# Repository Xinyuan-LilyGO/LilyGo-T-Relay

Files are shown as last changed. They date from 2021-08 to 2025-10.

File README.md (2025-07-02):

<h1 align = "center">🌟LILYGO T-Relay Series🌟</h1>

## 1️⃣ Quick Start:

* T-Relay  Channel  (Basic ESP32S3) **[English](docs/RELAY_2_ESP32S3.MD)**
* T-Relay 4 Channel (Basic ESP32) **[English](docs/RELAY_ESP32.md)/[中文](docs/RELAY_ESP32_CN.MD)**
* T-Relay 8 Channel (Basic ESP32) **[English](docs/RELAY_ESP32.md)/[中文](docs/RELAY_ESP32_CN.MD)**
* T-Relay S3 (Basic ESP32S3)      **[English](docs/RELAY_ESP32S3.MD)/[中文](docs/RELAY_ESP32S3_CN.MD)**

## 2️⃣ Where to buy:

#### T-Relay 4 Channel (Basic ESP32)
[LilyGo Shop](https://www.lilygo.cc/products/t-relay)

#### T-Relay 8 Channel (Basic ESP32)
[LilyGo Shop](https://www.lilygo.cc/products/t-relay-5v-8-channel-relay)

#### T-Relay S3 (Basic ESP32S3)
[LilyGo Shop](https://www.aliexpress.us/item/3256805375487806.html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)

## FAQ

* Q. How should I correctly connect the W5500 Shield to the motherboard?
* A. There are two versions of the W5500 Shield.

    1.T-Relay 4 Channel and T-Relay 8 Channel versions
    <p align="left">
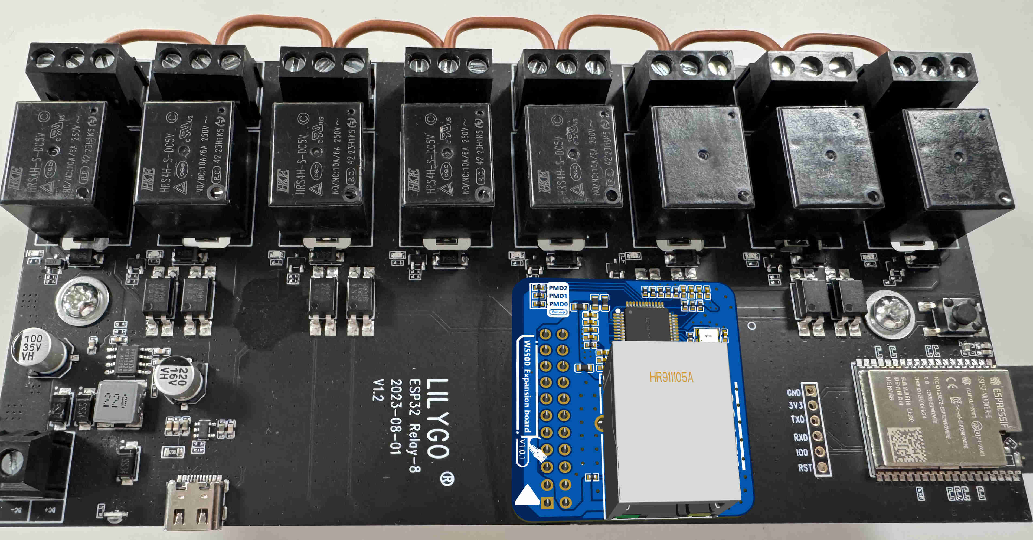
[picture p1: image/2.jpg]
        
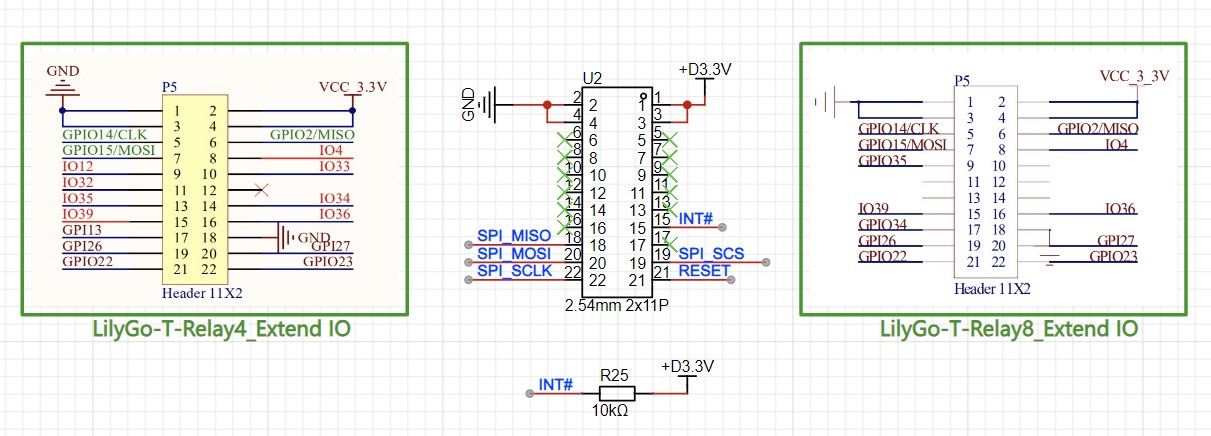
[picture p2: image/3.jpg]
        
    </p>
    <p align="left">
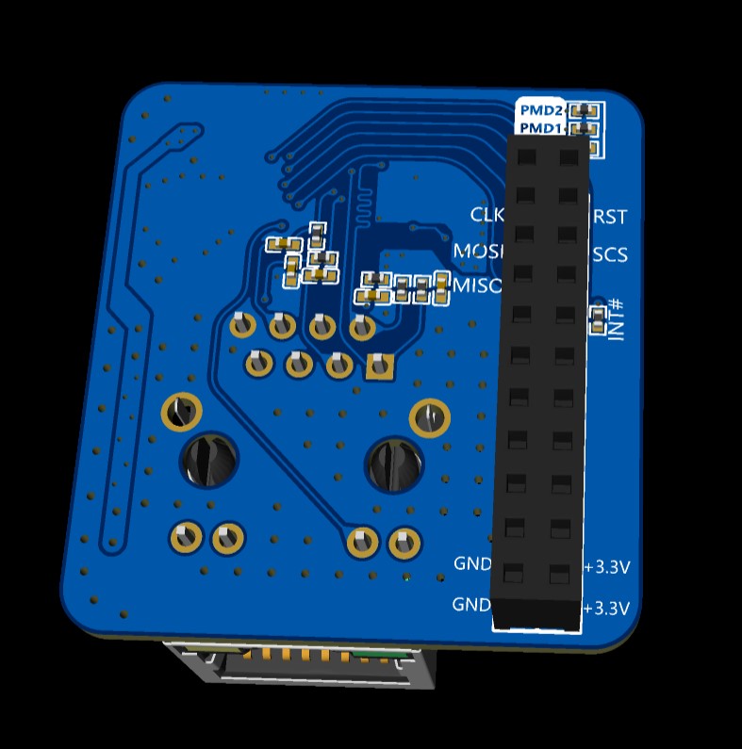
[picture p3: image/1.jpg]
        
    </p>

    2.T-Relay S3 versions
    <p align="left">
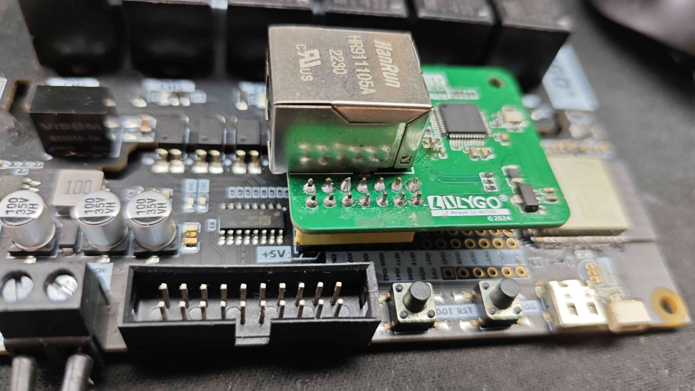
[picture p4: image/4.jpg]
        
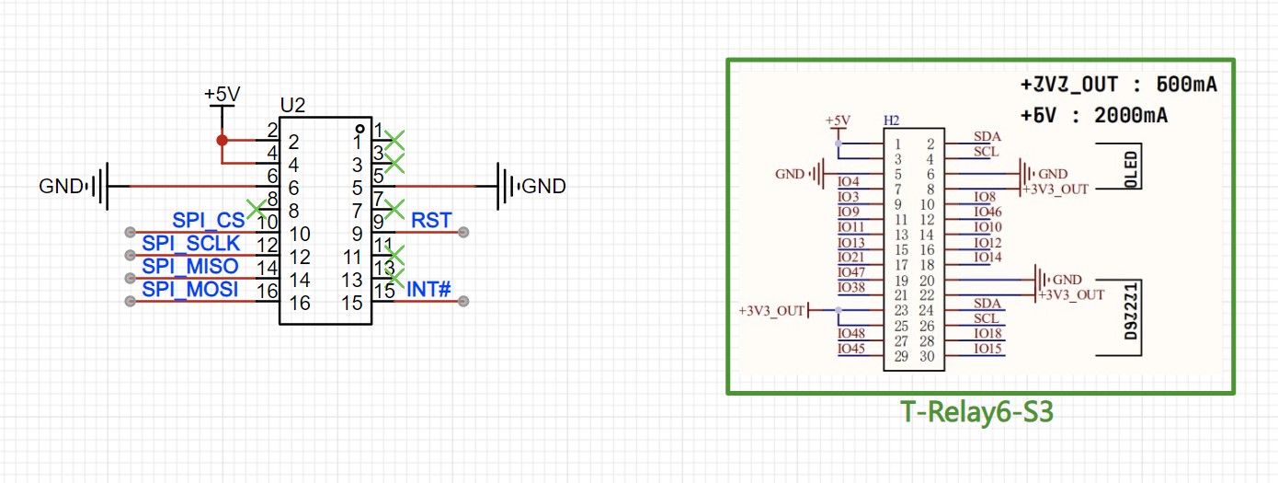
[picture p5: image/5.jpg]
        
    </p>
    <p align="left">
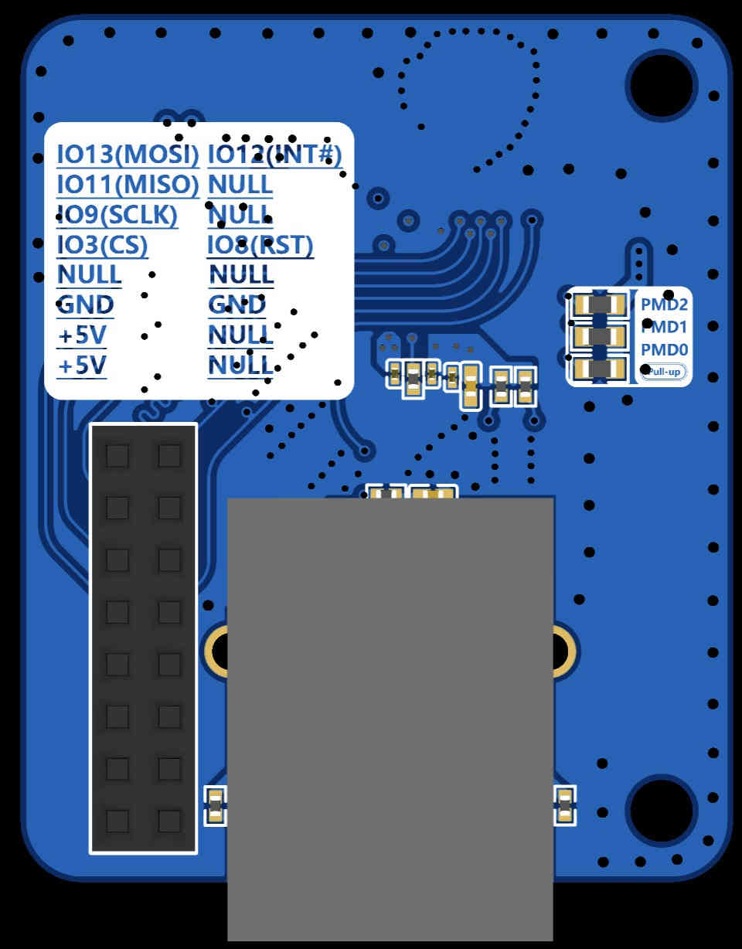
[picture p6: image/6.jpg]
        
    </p>

<br />

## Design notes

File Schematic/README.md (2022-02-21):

## This is LILYGO T-RELAY Schematic File

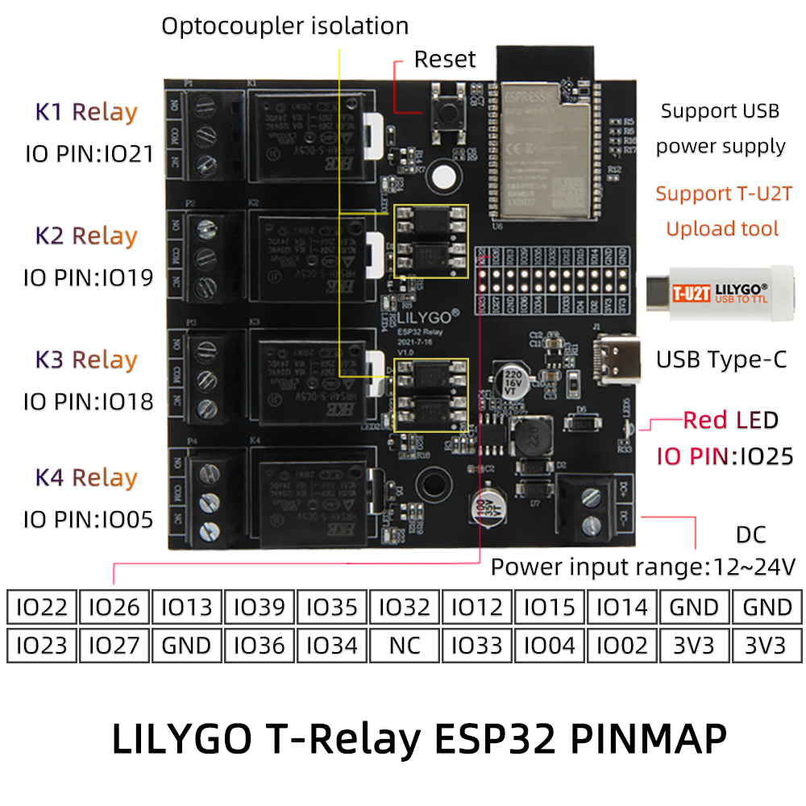
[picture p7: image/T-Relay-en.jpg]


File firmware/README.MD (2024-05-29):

# Write to new users

- This page provides a quick diagnosis of whether the hardware is normal. The firmware in the example table below provides quick testing of the hardware. Please follow the steps below to test

# 1️⃣ Quickly diagnose hardware

| Product | Firmware Name |
| --- | --- |
| [LilyGo-T-Relay-4][1] | [firmware](./LilyGo-T-Relay-4/LilyGo-T-Relay-4-20210816.bin) |
| [LilyGo-T-Relay-8][2] | [firmware](./LilyGo-T-Relay-8/LilyGo-T-Relay-8-20220516.bin) |
| [LilyGo-T-Relay-S3][3] | [firmware](./LilyGo-T-Relay-S3/firmware_LilyGo-Relay-UnitTest_20230830.bin) |
| [LilyGo-T-Relay_W5500_Ethernet 4 Channel][4] | [firmware](./LilyGo-T-Relay_W5500_EthernetServer_Relay4_V1.0_firmware/W5500_EthernetServer_Relay4_V1.0.bin) |
| [LilyGo-T-Relay_W5500_Ethernet 8 Channel][4] | [firmware](./LilyGo-T-Relay_W5500_EthernetServer_Relay8_V1.0_firmware/W5500_EthernetServer_Relay8_V1.0.bin) |
| [T-Relay6-S3-W5500_Original_Test] | [firmware](./LilyGo-T-Relay6-S3-W5500_Original_Test/[T-Relay6-S3_V1.0][T-Relay6-S3_W5500_Original_Test]_firmware_V1.0.0.bin) |

[1]: https://www.lilygo.cc/products/t-relay
[2]: https://www.lilygo.cc/products/t-relay-5v-8-channel-relay
[3]: https://www.lilygo.cc/products/t-relay-s3
[4]: https://www.lilygo.cc/products/t-relay?variant=43164455207093

### Use ESP Download Tool

- Download [Flash_download_tool](https://www.espressif.com.cn/sites/default/files/tools/flash_download_tool_3.9.5_0.zip)

web_flasher

* Note that after writing is completed, you need to press RST to reset.

### Use Web Flasher

- [ESP Web Flasher Online](https://espressif.github.io/esptool-js/)

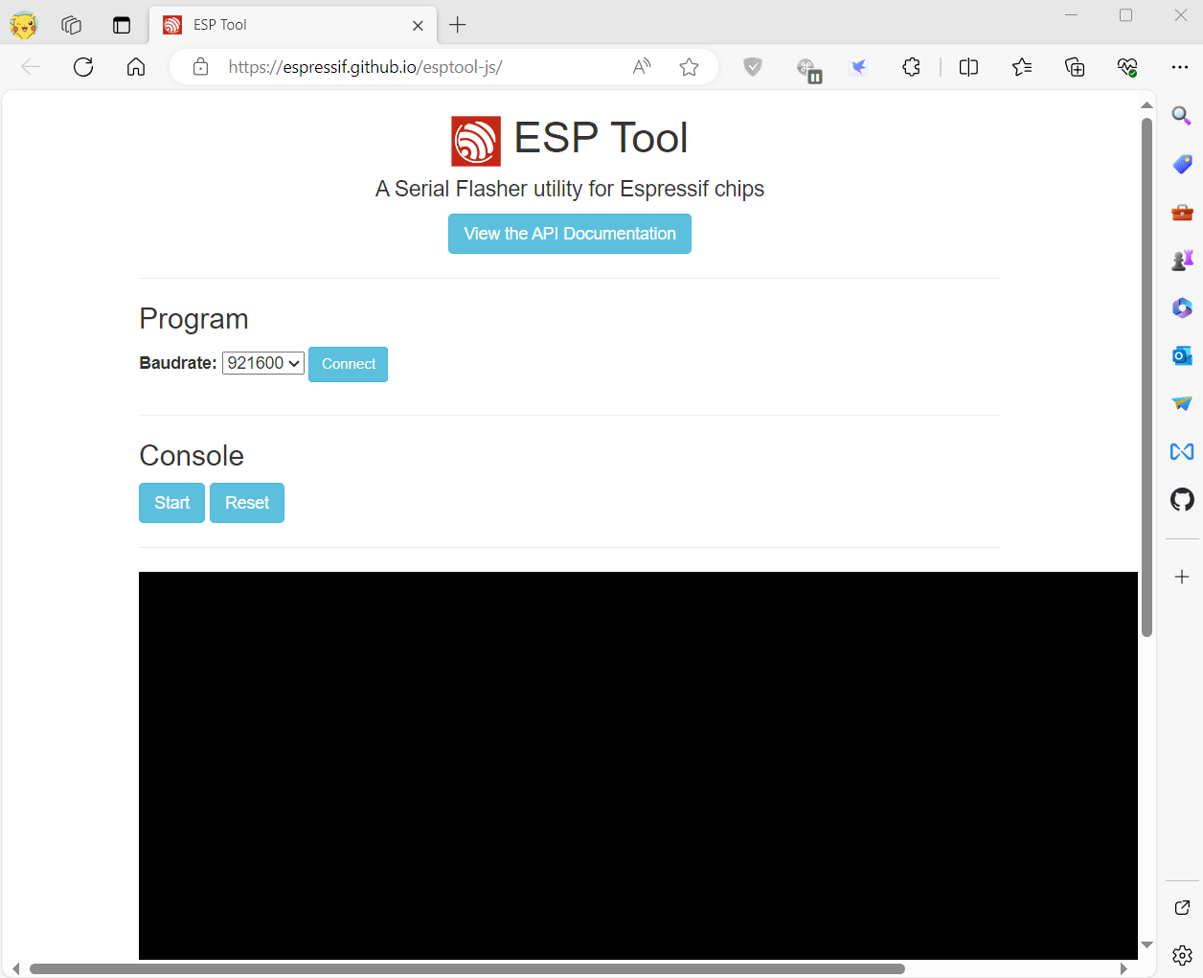
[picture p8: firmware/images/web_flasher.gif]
web_flasher


* Note that after writing is completed, you need to press RST to reset.

### Use command line

If system asks about install Developer Tools, do it.

```
python3 -m pip install --upgrade pip
python3 -m pip install esptool
```

In order to launch esptool.py, exec directly with this:

```
python3 -m esptool
```

For ESP32-S3 use the following command to write

```
esptool --chip esp32s3  --baud 921600 --before default_reset --after hard_reset write_flash -z --flash_mode dio --flash_freq 80m 0x0 firmware.bin

```

# 2️⃣FAQ

- Can't upload any sketch，Please enter the upload mode manually.
   1. Connect the board via the USB cable
   2. Press and hold the **BOOT** button , While still pressing the **BOOT** button (If there is no **BOOT** button, you need to use wires to connect **GND** and **IO0** together.)
   3. Press **RST** button
   4. Release the **RST** button
   5. Release the **BOOT** button (If there is no **BOOT** button, disconnect IO0 from GND.)
   6. Upload sketch
   7. Press the **RST** button to exit download mode

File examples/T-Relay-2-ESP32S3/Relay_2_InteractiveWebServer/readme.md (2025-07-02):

<h1 align = "center">🌟LILYGO T-RELAY🌟</h1>

## You need to write the right wifiCredentials.View the IP Address on the serial port.Enter the IP Address in the same LAN.You can control the state of the relay on the page.

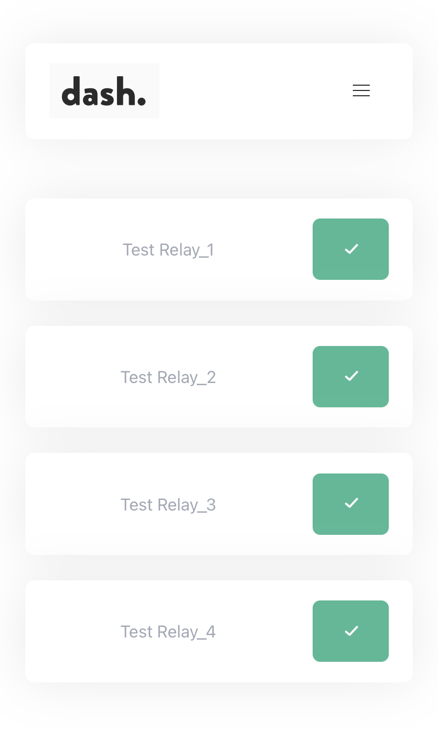
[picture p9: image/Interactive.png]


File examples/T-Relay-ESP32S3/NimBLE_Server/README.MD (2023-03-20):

```
    BLE send data format:
|  Pin index          |  setValue  |
|  Shift register pin |  value     |

```

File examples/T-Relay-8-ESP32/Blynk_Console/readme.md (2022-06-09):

<h1 align = "center">🌟LILYGO T-RELAY🌟</h1>

For [reference](../../../examples/T-Relay/Blynk_Console/readme.md). just add 4 moreVirtual Pin Datastream

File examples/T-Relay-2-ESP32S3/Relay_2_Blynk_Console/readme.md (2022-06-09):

<h1 align = "center">🌟LILYGO T-RELAY🌟</h1>

## Quick start
1. Register and login [blynk.cloud](https://blynk.cloud/dashboard/login)
2. Create a new template or use an existing template (The name can be customized)

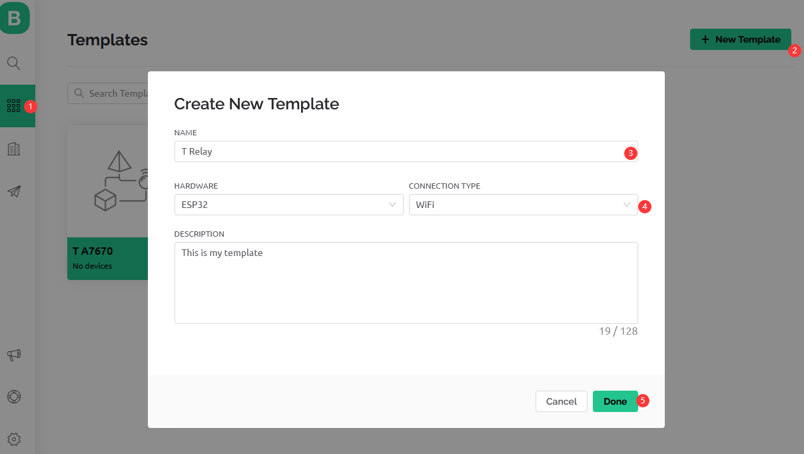
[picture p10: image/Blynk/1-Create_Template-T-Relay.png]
  

3. When the Template is ready, go to Search -> Devices - Create New Device

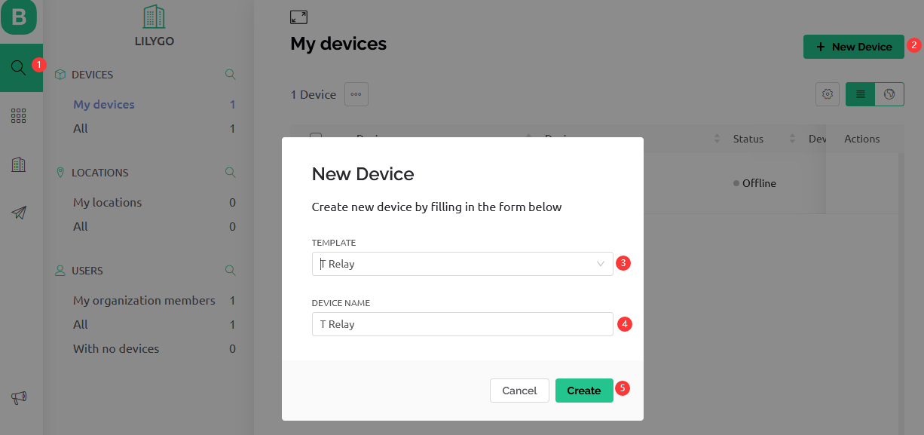
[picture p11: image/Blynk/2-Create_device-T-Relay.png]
  

4. Configuration module

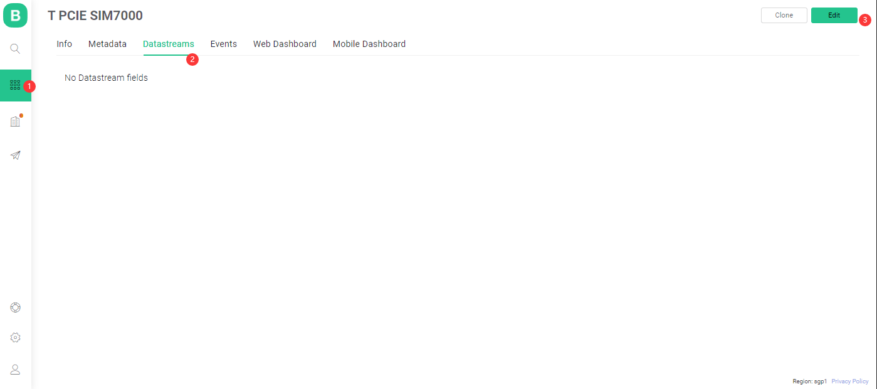
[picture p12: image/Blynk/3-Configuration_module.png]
  

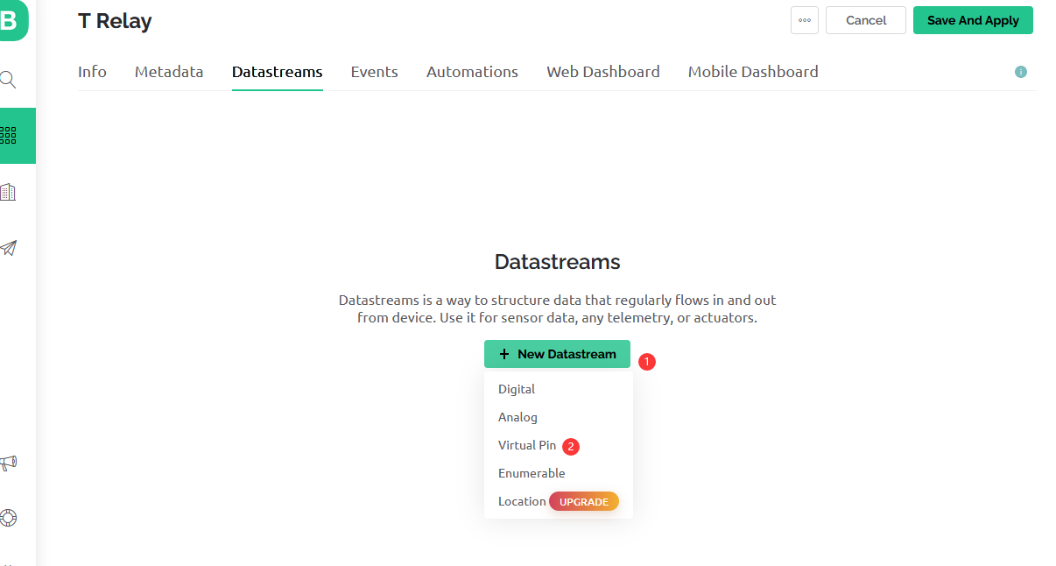
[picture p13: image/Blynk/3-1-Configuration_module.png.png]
  

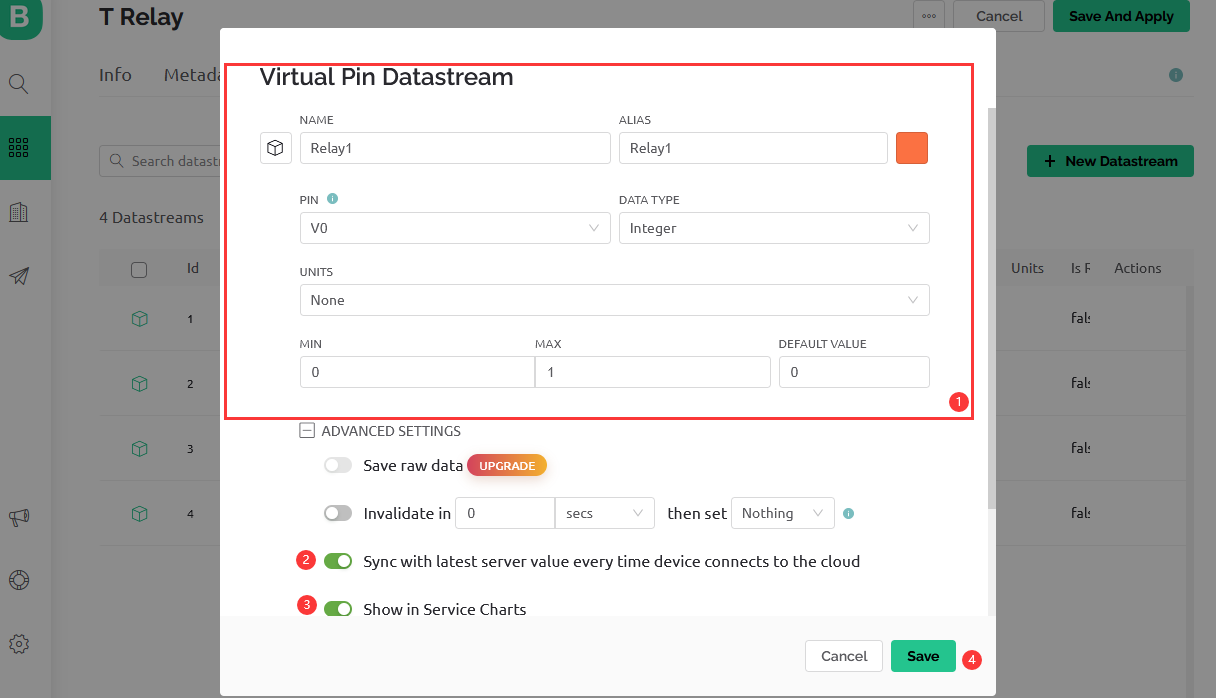
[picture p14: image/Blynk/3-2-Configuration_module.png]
  

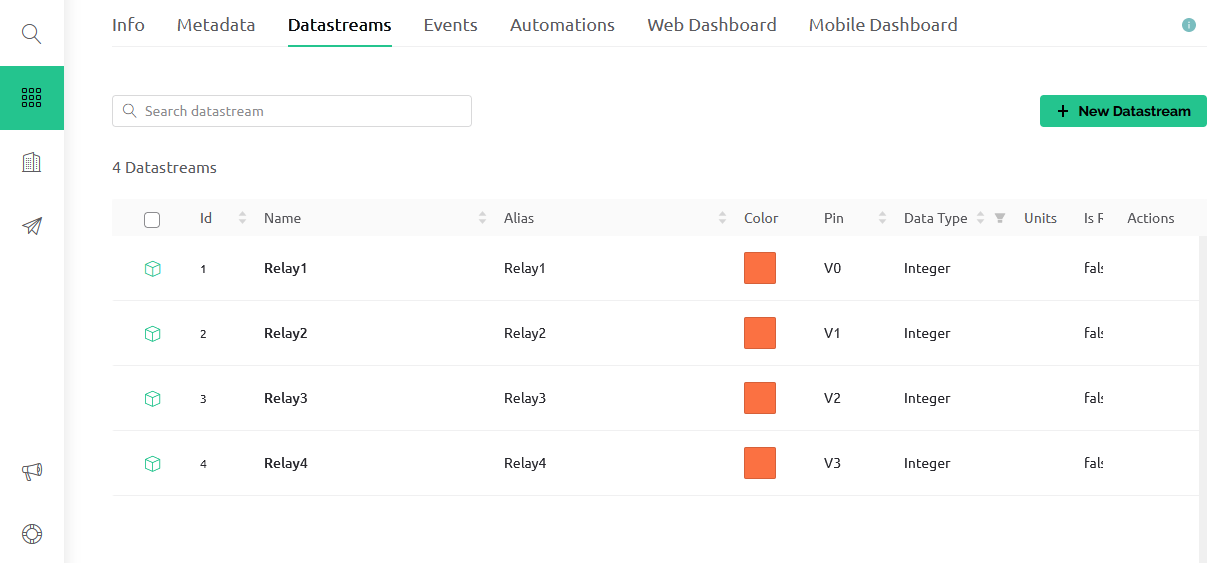
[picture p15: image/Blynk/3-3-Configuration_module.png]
  

5. Set up the Web dashboard 

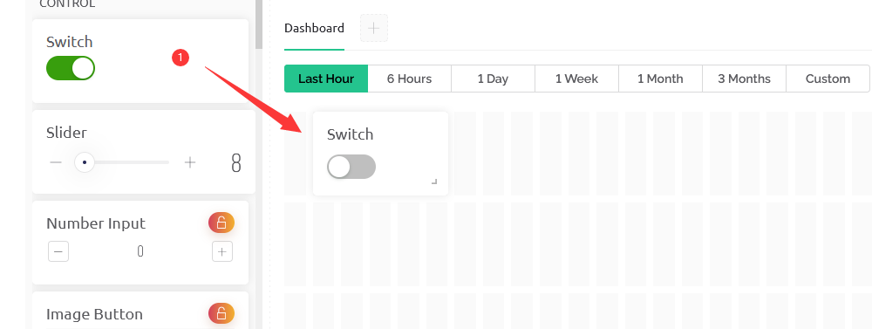
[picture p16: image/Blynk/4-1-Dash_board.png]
  

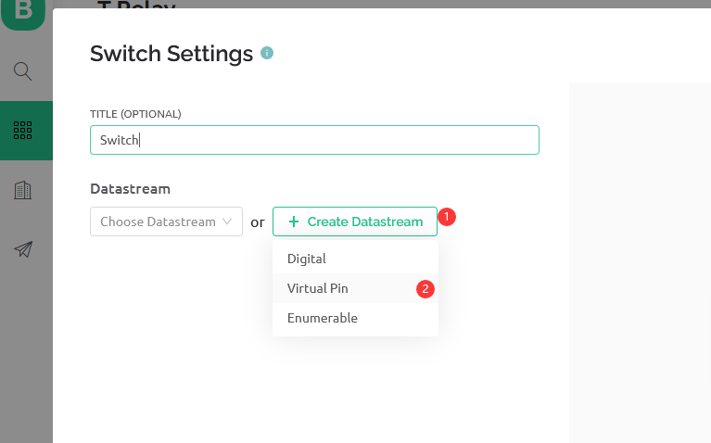
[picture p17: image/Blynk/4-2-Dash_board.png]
  

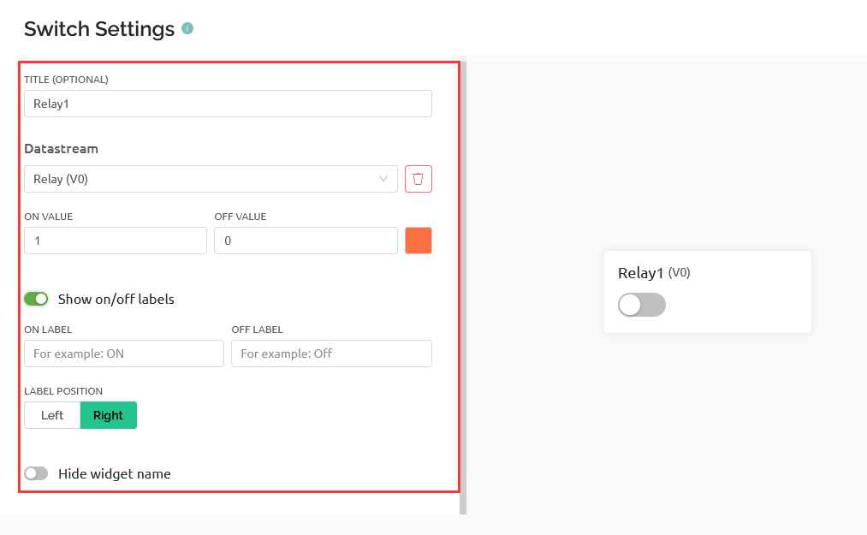
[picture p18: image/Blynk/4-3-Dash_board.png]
   

6. Create a New Event. Go to Template -> Edit -> Events tab.

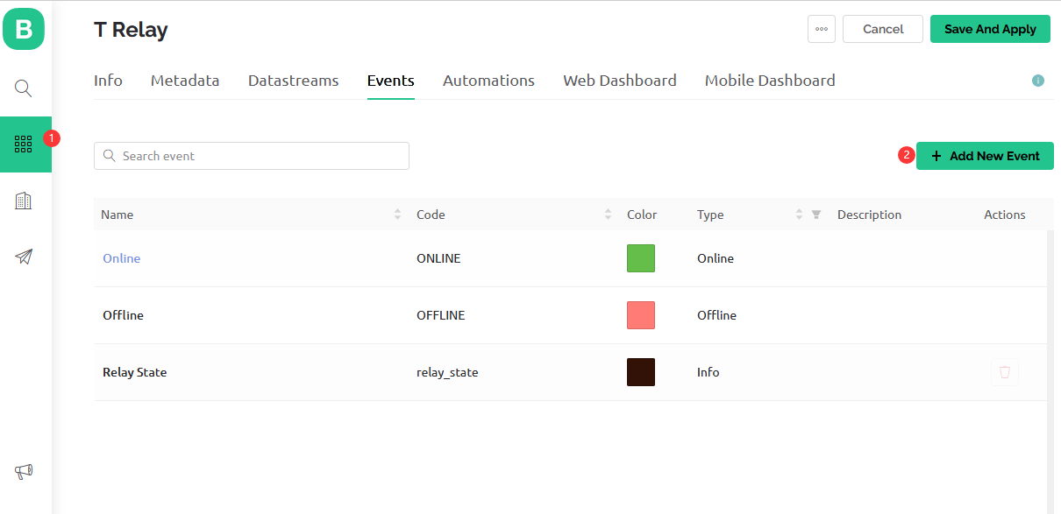
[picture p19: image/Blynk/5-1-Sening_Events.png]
  

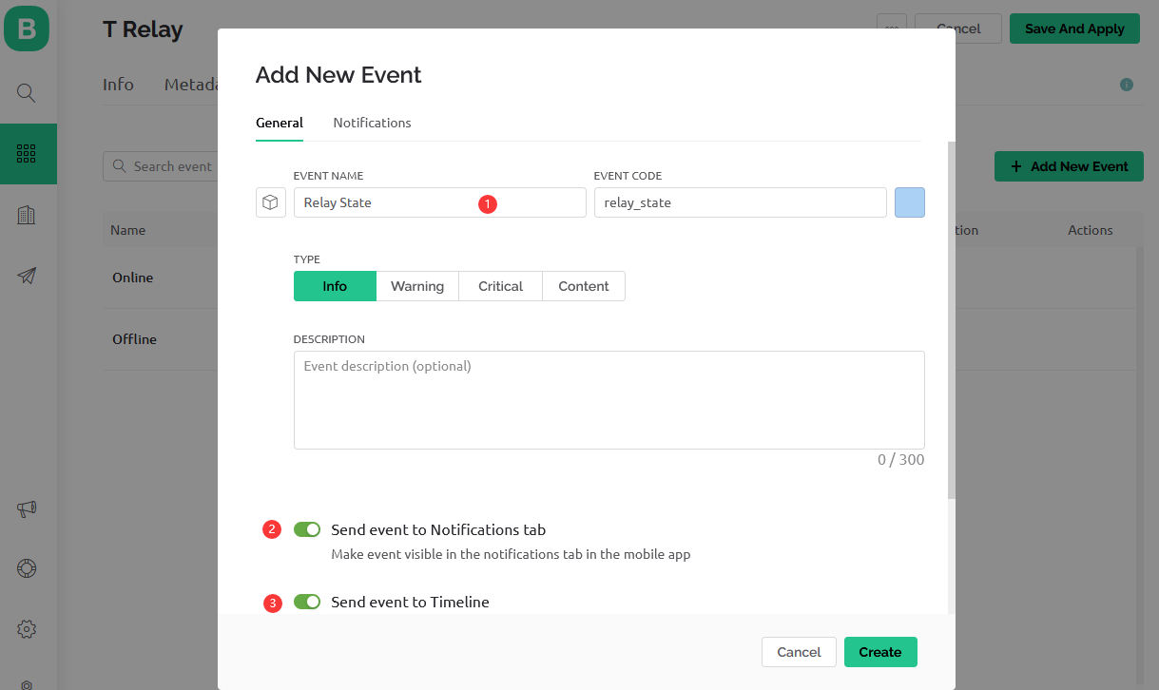
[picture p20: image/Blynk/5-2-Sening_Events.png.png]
  

7. Replace the macro definition in the code

    #define BLYNK_TEMPLATE_ID "" 
    #define BLYNK_DEVICE_NAME "" 
    #define BLYNK_AUTH_TOKEN ""

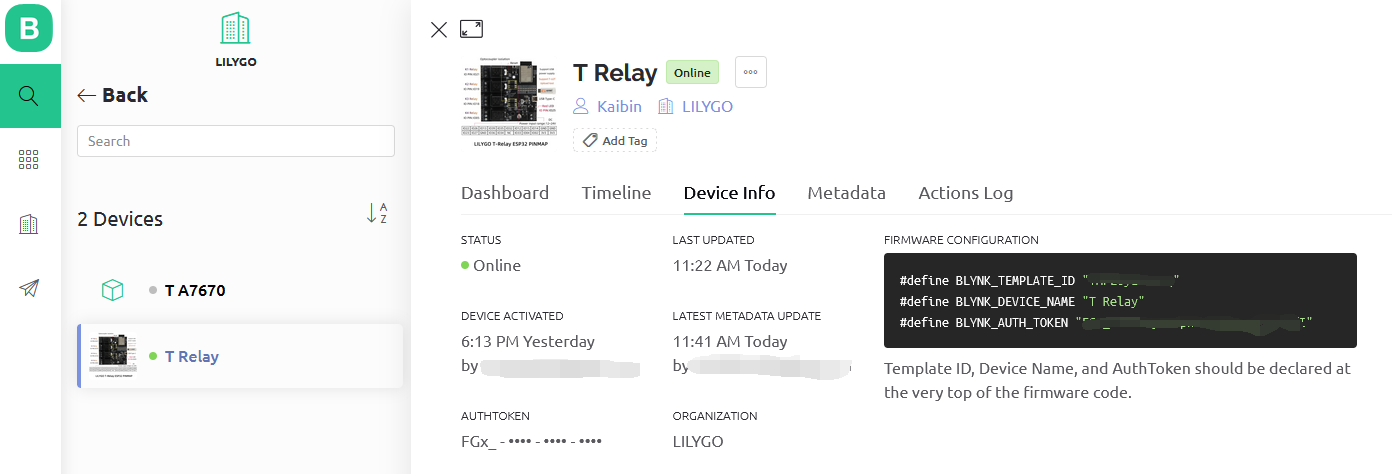
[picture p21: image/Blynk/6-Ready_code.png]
  

8. Upload the code and now you control the LDE and get the data in the cloud

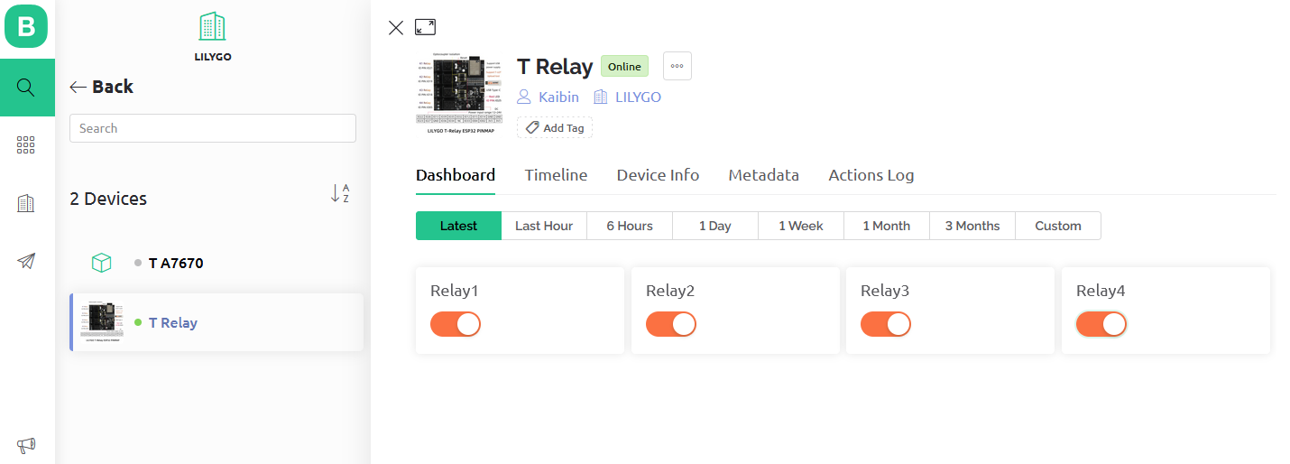
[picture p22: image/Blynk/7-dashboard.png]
  

9. USE [blynk.app](https://docs.blynk.io/en/downloads/blynk-apps-for-ios-and-android)

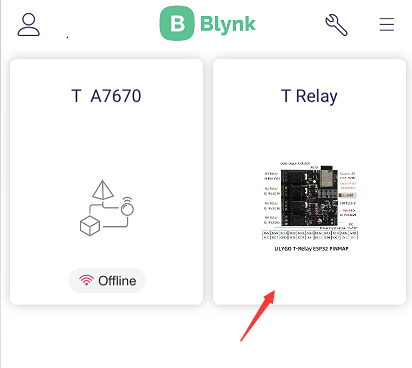
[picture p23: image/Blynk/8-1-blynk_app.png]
  

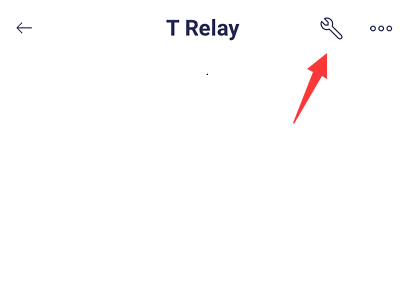
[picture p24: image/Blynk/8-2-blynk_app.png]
  

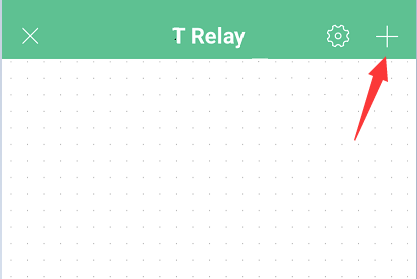
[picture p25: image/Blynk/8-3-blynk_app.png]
  

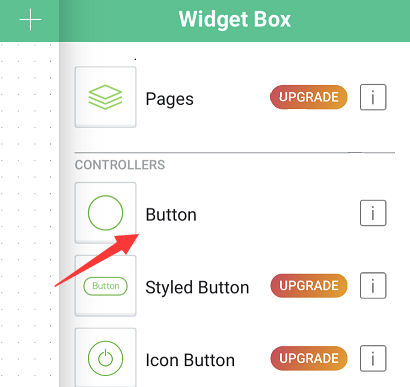
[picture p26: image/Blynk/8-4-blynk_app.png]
  

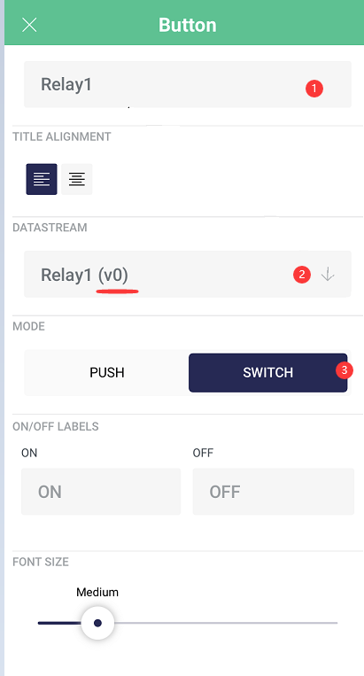
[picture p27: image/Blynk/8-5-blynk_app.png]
  

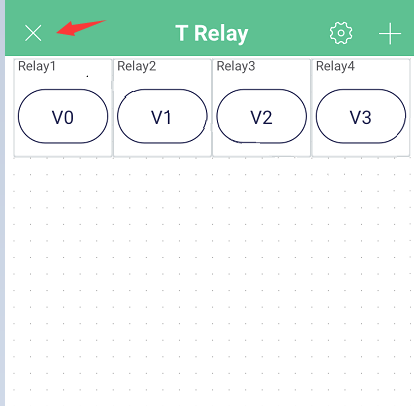
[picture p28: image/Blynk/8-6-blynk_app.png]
  

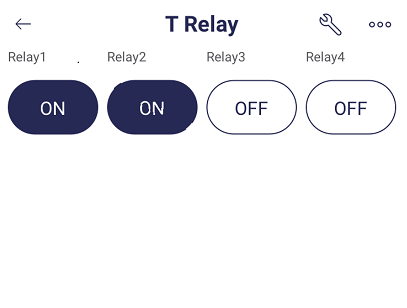
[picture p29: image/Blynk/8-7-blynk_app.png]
  

## Blynk References

1. [Getting Started Guide](https://www.blynk.cc/getting-started)
2. [Documentation](https://docs.blynk.io/en/blynk.apps/overview)
3. [Sketch generator](https://examples.blynk.cc/)

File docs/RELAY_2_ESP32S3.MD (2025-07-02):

<h1 align = "center">✨ LilyGO T-Relay-S3  2-Channel ✨</h1>

## 1️⃣ Examples preview

````

examples 
├── Relay_2_Blynk_Console        ; Blynk example
├── Relay_2_Blynk_WiFi           ; Blynk example
├── Relay_2_Factory              ; Factory test
├── Relay_2_InteractiveWebServer ; WebServer control relay
└── Relay_2_simple               ; Simple test relay

````

## 2️⃣ Quick Start

### PlatformIO

1. Install [VisualStudioCode](https://code.visualstudio.com/) and [Python](https://www.python.org/)
2. Search for the `PlatformIO` plugin in the `VisualStudioCode` extension and install it.
3. After the installation is complete, you need to restart `VisualStudioCode`
4. After restarting `VisualStudioCode`, select `File` in the upper left corner of `VisualStudioCode` -> `Open Folder` -> select the `LilyGo-T-Relay` directory
5. Click on the `platformio.ini` file, and in the `platformio` column, cancel the sample line that needs to be used, please make sure that only one line is valid
6. Click the (✔) symbol in the lower left corner to compile
7. Connect the board to the computer USB
8. Click (→) to upload firmware
9. Click (plug symbol) to monitor serial output

### ArduinoIDE

1. Install [ArduinoIDE](https://www.arduino.cc/en/software)
2. Copy all the folders in the `LilyGo-T-Relay/lib` directory to `<C:\Users\UserName\Documents\Arduino\libraries>`. If there is no `libraries` directory, please create a new one. Please note that you are not copying the `lib` directory, but copying the folders in the lib directory
3. Open ArduinoIDE -> Tools
- Board -> ESP32S3 Dev Module
- USB CDC On Boot -> Enable
- CPU Frequency -> 240MHz
- USB DFU On Boot -> Disable
- Flash Mode -> QIO 80MHz
- Flash Size -> 4MB(32Mb)
- USB Firmware MSC On Boot -> Disable
- PSRAM -> Disabled
- Partition Scheme -> Default 4MB with spiffs (1.2MB APP/1.5MB SPIFFS)
- USB Mode -> Hardware CDC and JIAG
- Upload Mode -> UART0/Hardware CDC
- Upload Speed -> 921600

## 3️⃣ Tips

1. The board uses USB as the JTAG upload port. When printing serial port information on USB_CDC_ON_BOOT configuration needs to be turned on. 
If the port cannot be found when uploading the program or the USB has been used for other functions, the port does not appear. 
Please enter the upload mode manually.
   1. Connect the board via the USB cable
   2. Press and hold the BOOT button , While still pressing the BOOT button, press RST
   3. Release the RST
   4. Release the BOOT button
   5. Upload sketch

## 4️⃣ ESP32S3 Pins

| Relay num | ESP32S3 Pins |
| :---: | :---: |
|  Relay 1  | IO35 |
|  Relay 2  | IO36 |

## QWIIC I2C Pins

| Name  | ESP32S3 Pins |
| :---: | :---: |
|  SDA  | IO16 |
|  SCL  | IO17 |

## QWIIC UART Pins

| Name  | ESP32S3 Pins |
| :---: | :---: |
|  TXD  | IO43 |
|  RXD  | IO44 |

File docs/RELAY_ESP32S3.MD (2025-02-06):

<!--
 * @Description: None
 * @version: V1.0.0
 * @Author: None
 * @Date: 2024-05-29 14:38:46
 * @LastEditors: LILYGO_L
 * @LastEditTime: 2024-07-19 09:57:19
 * @License: GPL 3.0
-->
<h1 align = "center">✨ LilyGO T-Relay S3  ✨</h1>

## **English | [中文](RELAY_ESP32S3_CN.MD)**

## 1️⃣ Examples preview

````

examples 
├─DS18x20_Temperature          # External DS18B20 Example，The default is that there is no such sensor, which requires an external connection
├─HomeAssistant                # Example of easy configuration for accessing Home Assistant+OLED SS1306
├─NimBLE_Server                # uses BLE to control the relay
├─RTC_DS3231_External_Module   # using DS3231 External RTC module
├─RTC_PCF8563_TimeSynchronization    # using On board PCF8563 RTC 
├─TFT_ESPI                     # using a 2.4 'inch resistive touch screen
├─UnitTestExample              # Test programt
├─HT74HC595                #HT74HC595 test program 
└─T-Relay6-S3-W5500_Original_Test        #T-Replay6-S3 External W5500 Factory Test Procedure

````

## 2️⃣ Quick Start

### PlatformIO

1. Install [VisualStudioCode](https://code.visualstudio.com/) and [Python](https://www.python.org/)
2. Search for the `PlatformIO` plugin in the `VisualStudioCode` extension and install it.
3. After the installation is complete, you need to restart `VisualStudioCode`
4. After restarting `VisualStudioCode`, select `File` in the upper left corner of `VisualStudioCode` -> `Open Folder` -> select the `LilyGo-T-Relay` directory
5. Click on the `platformio.ini` file, and in the `platformio` column, cancel the sample line that needs to be used, please make sure that only one line is valid
6. Click the (✔) symbol in the lower left corner to compile
7. Connect the board to the computer USB
8. Click (→) to upload firmware
9. Click (plug symbol) to monitor serial output

### ArduinoIDE

1. Install [ArduinoIDE](https://www.arduino.cc/en/software)
2. Copy all the folders in the `LilyGo-T-Relay/lib` directory to `<C:\Users\UserName\Documents\Arduino\libraries>`. If there is no `libraries` directory, please create a new one. Please note that you are not copying the `lib` directory, but copying the folders in the lib directory
3. Open ArduinoIDE -> Tools
- Board -> ESP32S3 Dev Module
- USB CDC On Boot -> Enable
- CPU Frequency -> 240MHz
- USB DFU On Boot -> Disable
- Flash Mode -> QIO 80MHz
- Flash Size -> 16MB(128Mb)
- USB Firmware MSC On Boot -> Disable
- PSRAM -> OPI PSRAM
- Partition Scheme -> 16M Flash(3MB APP/9.9MB FATFS)
- USB Mode -> Hardware CDC and JIAG
- Upload Mode -> UART0/Hardware CDC
- Upload Speed -> 921600

## 3️⃣ Tips:

1. ⚠`T-Relay` uses `Octal SPI` Flash, so **GPIO35 ~ GPIO37** are not available, please do not use these IOs in the software
2. ⚠`T-Relay` **3v3*** The maximum external current allowed is **500mA**, please do not exceed this supply current
3. ⚠`T-Relay` **5V** Pin The maximum allowable current is 3000mA, ESP32S3 and other external components require nearly 800mA current, so please do not connect external components greater than **2000mA**
4. ⚠`T-Relay` The maximum allowable current for electric shock on relay pins is 10A load current, please do not connect load devices exceeding **2500W**
5. ⚠**If an external relay load greater than 48V is connected, please power off the main board and connected equipment first to prevent electric shock.**
6. ⚠`T-Relay` is a serial-to-parallel design for `74HC595`, allowing multiple `T-Relay` sub-boards to be connected, but please note that due to the design of the power supply of the main board, it is currently recommended that cascaded devices not More than 3 relay sub-boards, cascading three sub-boards, the power supply of the main board will be hot, which is normal, please do not touch it with your hands to prevent burns. If you work for a long time, it is recommended to paste a heat sink on the inductor of the power supply to assist the main board to dissipate heat.
7. ⚠ The DS18B20 sensor interface is reserved by default, and there is no such sensor by default
8. External reserved expansion screen interface [Support TFT Module Link](http://www.lcdwiki.com/zh/2.8inch_SPI_Module_ILI9341_SKU:MSP2807) , Relay-S3 default design size is 2.4 inches
9. The board uses USB as the JTAG upload port. When printing serial port information on USB_CDC_ON_BOOT configuration needs to be turned on. 
If the port cannot be found when uploading the program or the USB has been used for other functions, the port does not appear. 
Please enter the upload mode manually. 
   1. Connect the board via the USB cable
   2. Press and hold the BOOT button , While still pressing the BOOT button, press RST
   3. Release the RST
   4. Release the BOOT button
   5. Upload sketch

## 4️⃣ ESP32S3 Pins:

| Shift register | DATA | CLOCK | LATCH | nOE |
| --- | ---- | ----- | ----- | --- |
| GPIO | 7 | 5 | 6 | 4 |

| RTC  | SDA | SCL | IRQ |
| ---- | --- | --- | --- |
| GPIO | 16  | 17  | 18  |

## 5️⃣ Shift register hardware distribution:

| Relay Channel | CH1 | CH2 | CH3 | CH4 | CH5 | CH6 | CH7 | CH8 |
| --- | --- | --- | --- | --- | --- | --- | --- | --- |
| GPIO | SR1 | SR2 | SR3 | SR4 | SR5 | SR6 | GREEN LED | RED LED |

## 6️⃣ T-Relay6-S3-W5500 Pin:

| T-Relay6-S3-W5500 Pin  | ESP32S3 Pin|
| :---: | :---:|
| SCLK | IO9 |
| MISO | IO11 |
| MOSI | IO13 |
| CS | IO3 |
| RST | IO8 |
| INT | IO12 |

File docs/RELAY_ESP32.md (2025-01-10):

<h1 align = "center">🌟LILYGO T-RELAY🌟</h1>

## **English | [中文](./RELAY_ESP32_CN.MD)**

<h3 align = "left">Quick start:</h3>

## Using **Arduino IDE**

1. Install the current upstream Arduino IDE at the 1.8 level or later. The current version is at the [Arduino website](http://www.arduino.cc/en/main/software).
2. Start Arduino and open Preferences window. In additional board manager add url: https://raw.githubusercontent.com/espressif/arduino-esp32/gh-pages/package_esp32_index.json .separating them with commas.
3. Select Tools -> Board -> ESP32 Dev Module
4. Need to install the following dependencies
     - [blynk-library](https://github.com/blynkkk/blynk-library)
     - [ESP-DASH](https://github.com/ayushsharma82/ESP-DASH)
     - [AsyncTCP](https://github.com/me-no-dev/AsyncTCP)
     - [ESPAsyncWebServer](https://github.com/me-no-dev/ESPAsyncWebServer)

## Using **PlatformIO**

1. Install [VSCODE](https://code.visualstudio.com/) and [Python](https://www.python.org/)

2. Search for the PlatformIO plug-in in the VSCODE extension and install it.

3. After the installation is complete and the reload is completed, there will be a small house icon in the lower left corner. Click to display the Platformio IDE home page

4. Go to file - > Open folder - > Select the LilyGO-T-RELAY .In the platforio.ini file select the project you want to upload. folder and click the (√) symbol in the lower left corner to compile (→) for upload.

<h3 align = "left">Product 📷:</h3>

|  Product  | Product  Link |
| :---: | :---: |
|  T-Relay  | [AliExpress](https://pt.aliexpress.com/item/3256802975186083.html)/[Amazon](https://www.amazon.com/dp/B09XX1HL9Z?ref=myi_title_dp) |
| T-Relay-8 | [AliExpress](https://pt.aliexpress.com/item/3256804149327347.html)/[Amazon](https://www.amazon.com/dp/B0B6TXKXDN?ref=myi_title_dp) |

## T-Relay-8 Pinout


## T-Relay Pinout


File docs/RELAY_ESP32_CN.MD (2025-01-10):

<h1 align = "center">🌟LILYGO T-RELAY🌟</h1>

## **[English](RELAY_ESP32.md) | 中文**

<h3 align = "left">快速开始:</h3>

## 使用**Arduino IDE**

1. 安装1.8以上的[Arduino IDE](http://www.arduino.cc/en/main/software).
2. 打开Arduino IDE 在文件->首选项->附加开发板管理器网站添加 https://raw.githubusercontent.com/espressif/arduino-esp32/gh-pages/package_esp32_index.json .最后用以逗号隔开。(由于这个网站服务器在国外，可能比较慢或者不成功。也可以参考[LilyGo-Document](https://github.com/Xinyuan-LilyGO/LilyGo-Document)来搭建)
3. 选择"工具"->开发板 -> ESP32 Dev Module
4. 需要安装的库
     - [blynk-library](https://github.com/blynkkk/blynk-library)
     - [ESP-DASH](https://github.com/ayushsharma82/ESP-DASH)
     - [AsyncTCP](https://github.com/me-no-dev/AsyncTCP)
     - [ESPAsyncWebServer](https://github.com/me-no-dev/ESPAsyncWebServer)

### 使用**PlatformIO**
1. 安装[VSCODE](https://code.visualstudio.com/)和[Python](https://www.python.org/)
2. 在VSCODE扩展中搜索PlatformIO插件并安装。
3. 安装完成，重新加载后，左下角会多一个小房子图标，点击后即可显示Platformio IDE主页
4. 进入文件- >打开文件夹- >选择LilyGO-T-RELAY，在platform .ini文件中选择要上传的项目。点击左下角的(√)符号编译(→)即可上传。

<h3 align = "left">Product 📷:</h3>

| Product | Product  Link  |
| :---: | :---: |
| [T-Relay]() | [AliExpress]() |

## Pinout


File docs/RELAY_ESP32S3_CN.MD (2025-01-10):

<!--
 * @Description: None
 * @version: V1.0.0
 * @Author: None
 * @Date: 2024-05-29 14:38:46
 * @LastEditors: LILYGO_L
 * @LastEditTime: 2024-05-29 16:53:51
 * @License: GPL 3.0
-->

<h1 align = "center">✨ LilyGO T-Relay S3 ✨</h1>

## **[English](RELAY_ESP32S3.MD) | 中文**

## 1️⃣ 示例预览

```
examples 
├─DS18x20_Temperature            #外接DS18B20示例     
├─HomeAssistant                  #简易配置就可以接入家庭助理 +OLED SS1306  示例
├─NimBLE_Server                  #使用BLE 控制继电器        
├─RTC_DS3231_External_Module   # 使用 外部接入 DS3231 RTC模块
├─RTC_PCF8563_TimeSynchronization    # 使用板载 PCF8563 RTC 
├─TFT_eSPI                       #使用2.4'寸电阻触摸屏 
├─UnitTestExample                #测试程序     
├─HT74HC595                #HT74HC595测试程序     
└─T-Relay6-S3-W5500_Original_Test        #T-Relay6-S3外插W5500出厂测试程序     

```

## 2️⃣ 快速开始

### PlatformIO

1. 安装[VisualStudioCode](https://code.visualstudio.com/) 和 [Python](https://www.python.org/)
2. 在`VisualStudioCode`扩展中搜索`PlatformIO`插件并安装.
3. 安装完成后需要将`VisualStudioCode`重新启动
4. 重新开启`VisualStudioCode`后,选择 `VisualStudioCode` 左上角的 `文件` -> `打开文件夹` ->选择 `LilyGo-T-Relay` 目录
5. 点击 `platformio.ini` 文件,在`platformio` 栏目中取消需要使用的示例行,请确保仅仅一行有效
6. 点击左下角的（✔）符号编译
7. 将板子与电脑USB进行连接
8. 点击（→）上传固件
9. 点击 (插头符号) 监视串行输出s

### ArduinoIDE

1. 安装 [ArduinoIDE](https://www.arduino.cc/en/software)
2. 将 `LilyGo-T-Relay/lib` 目录内的所有文件夹拷贝到`<C:\Users\UserName\Documents\Arduino\libraries>`,如果没有`libraries`目录,请新建,请注意,不是拷贝`lib`目录,而是拷贝lib目录里面的文件夹
3. 打开ArduinoIDE -> Tools 
   - Board -> ESP32S3 Dev Module
   - USB CDC On Boot -> Enable
   - CPU Frequency -> 240MHz
   - USB DFU On Boot -> Disable
   - Flash Mode -> QIO 80MHz
   - Flash Size -> 16MB(128Mb)
   - USB Firmware MSC On Boot -> Disable
   - PSRAM -> OPI PSRAM
   - Partition Scheme -> 16M Flash(3MB APP/9.9MB FATFS)
   - USB Mode -> Hardware CDC and JIAG
   - Upload Mode -> UART0/Hardware CDC
   - Upload Speed -> 921600
4. 插入USB到PC,点击上传<如果无法顺利上传,请保持按压BOOT按键,然后单击RST,然后再点击上传,上传完成时需要点击RST退出下载模式

### ESPHome

1. 请查看参考[配置文件](./esphome/relay.yaml)
2. 在使用过程中,ESPHome得到的效果并不好,不建议使用,如果需要接入HomeAssistant请使用 <examples/HomeAssistant> 草图，可以通过入网配置期间配置继电器数量，MQTT服务器参数 ,HomeAssistant如果开启了自动发现,那么 `T-Relay`能够被 HomeAssistant 自动发现.

## 3️⃣ 提示:

1. ⚠`T-Relay` 使用 `Octal SPI` Flash ,所以 **GPIO35 ~ GPIO37** 为不可用,请不要在软件中使用这几个IO
2. ⚠`T-Relay` **3v3*** 外部允许最大电流为**500mA**，请不要超过此供电电流
3. ⚠`T-Relay` **5V** Pin 最大允许电流为3000mA，ESP32S3 和其他外部元器件需要将近800mA电流，所以请不要在外部连接大于**2000mA**的元器件
4. ⚠`T-Relay` 继电器引脚触电最大允许电流为10A负载电流，请不要连接超过**2500W**的负载设备
5. ⚠**如果外接大于48V的继电器负载，请先将主板和连接设备进行断电，防止触电.**
6. ⚠`T-Relay` 为`74HC595`串行转并行设计,允许多个`T-Relay`副板进行连接,但是请注意，受限于主板的供电的设计,目前建议 级联设备不超过 3 个继电器副板，级联三个副板，主板电源会发烫这是正常的，请不要用手触摸,防止烫伤,如果长时间工作，建议在电源电感处粘贴散热器辅助主板散热.
7. ⚠ 默认预留DS18B20传感器接口,默认是没有这个传感器的

## 4️⃣ ESP32S3 引脚分布:

| Shift register | DATA | CLOCK | LATCH |
| --- | ---- | ----- | ----- |
| GPIO | 7 | 5 | 6 |

| RTC  | SDA | SCL | IRQ |
| ---- | --- | --- | --- |
| GPIO | 16  | 17  | 18  |

## 5️⃣ 移位寄存器硬件分布:

| Relay Channel | CH1 | CH2 | CH3 | CH4 | CH5 | CH6 | CH7 | CH8 |
| --- | --- | --- | --- | --- | --- | --- | --- | --- |
| GPIO | SR1 | SR2 | SR3 | SR4 | SR5 | SR6 | GREEN LED | RED LED |

## 6️⃣ T-Relay6-S3-W5500 引脚:

| T-Relay6-S3-W5500 引脚  | ESP32S3 引脚|
| :---: | :---:|
| SCLK | IO9 |
| MISO | IO11 |
| MOSI | IO13 |
| CS | IO3 |
| RST | IO8 |
| INT | IO12 |

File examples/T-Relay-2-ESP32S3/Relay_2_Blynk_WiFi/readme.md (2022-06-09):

<h1 align = "center">🌟LILYGO T-RELAY🌟</h1>

## Quick start

**Note that this example requires an older version of Blynk.app.  Please use the new version [reference](../Blynk_Console)**

1. Downloads APP
Blynk Apps for iOS or Android
2. Create a Blynk Account
After you download the Blynk App, you’ll need to create a New Blynk account.(If you have already created an account, you can skip this step)

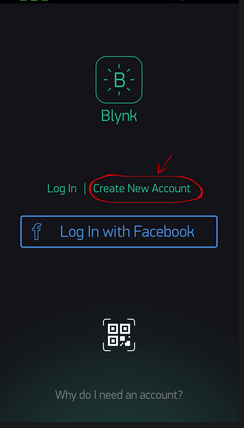
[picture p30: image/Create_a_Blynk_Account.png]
  

3. Create a New Project
After you’ve successfully logged into your account, start by creating a new project.

  

4. Choose Your Hardware
Select the hardware model you will use. 

  

5. Auth Token

  
  

6. Add a Widget

  
Configure GP21, GP19, GP18, and GP5 in sequence.

  

  

7. Upload routines (note the configuration of wifi and Auth tokens).Now you can use it to control the state of the relay.

## Blynk References

1. [Getting Started Guide](https://www.blynk.cc/getting-started)
2. [Documentation](https://docs.blynk.io/en/blynk.apps/overview)
3. [Sketch generator](https://examples.blynk.cc/)

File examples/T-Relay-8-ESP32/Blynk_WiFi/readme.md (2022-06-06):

<h1 align = "center">🌟LILYGO T-RELAY🌟</h1>

## Quick start
1. Downloads APP
Blynk Apps for iOS or Android
2. Create a Blynk Account
After you download the Blynk App, you’ll need to create a New Blynk account.(If you have already created an account, you can skip this step)

  

3. Create a New Project
After you’ve successfully logged into your account, start by creating a new project.

  

4. Choose Your Hardware
Select the hardware model you will use. 

  

5. Auth Token

  
  

6. Add a Widget

  

7. Upload routines (note the configuration of wifi and Auth tokens).Now you can use it to control the state of the relay.

## Blynk References

1. [Getting Started Guide](https://www.blynk.cc/getting-started)
2. [Documentation](https://docs.blynk.io/en/blynk.apps/overview)
3. [Sketch generator](https://examples.blynk.cc/)

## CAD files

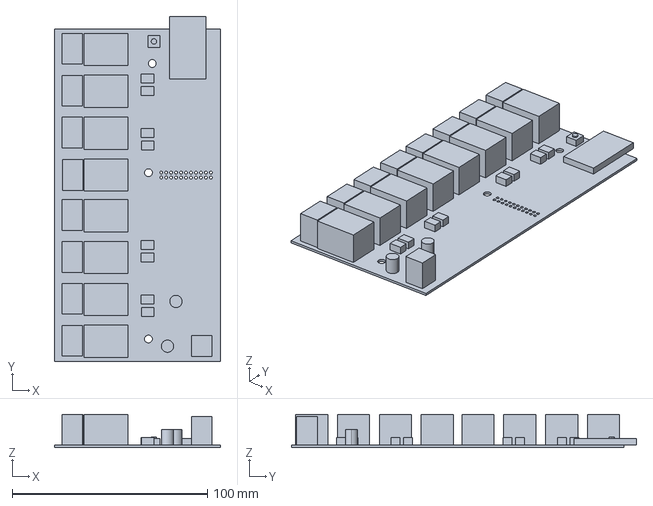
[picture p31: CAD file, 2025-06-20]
dxf/T-Relay8-ESP32-3D.stp
85.0 x 176.5 x 16.9 mm

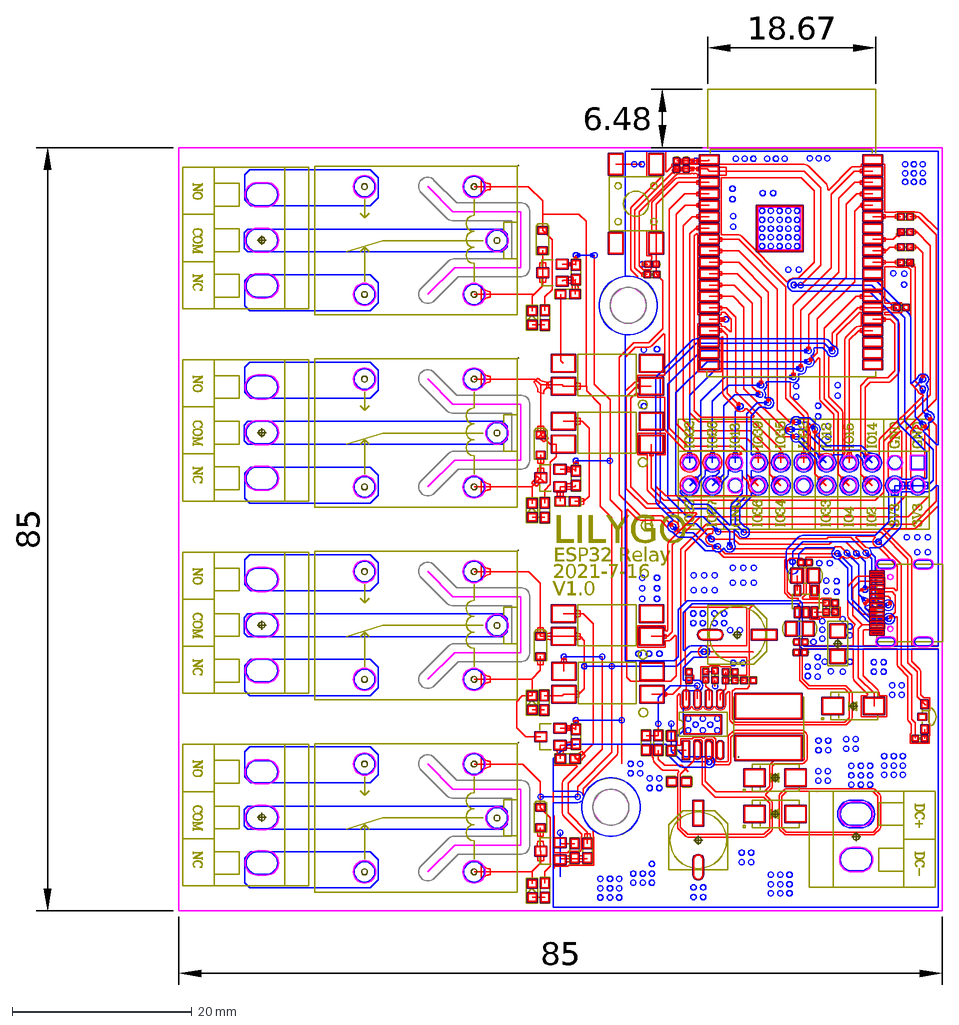
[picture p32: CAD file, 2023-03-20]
dxf/T-Relay-ESP32.dxf
R
LILYGO
ESP32 Relay
2021-7-16
V1.0
85
18.67
6.48

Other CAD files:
dxf/T-Relay6-ESP32S3.dwg
dxf/T-Relay8-ESP32.dxf

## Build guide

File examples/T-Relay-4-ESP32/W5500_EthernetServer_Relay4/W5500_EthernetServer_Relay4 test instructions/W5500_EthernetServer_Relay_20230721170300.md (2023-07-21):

<!--
 * @Description: None
 * @version: V1.0.0
 * @Author: None
 * @Date: 2023-07-21 15:51:36
 * @LastEditors: LILYGO_L
 * @LastEditTime: 2023-07-21 17:29:46
 * @License: GPL 3.0
-->
## Test Instructions V1.0
---
### 1.Whether the W5500 device can be found
* 1.1 Insert the W5500 into the LILYGO-T-Relay, with the Ethernet port facing the edge of the board. After opening the serial port, if there is a W5500 device, it will display "Ethernet W5500 Discovery!" 
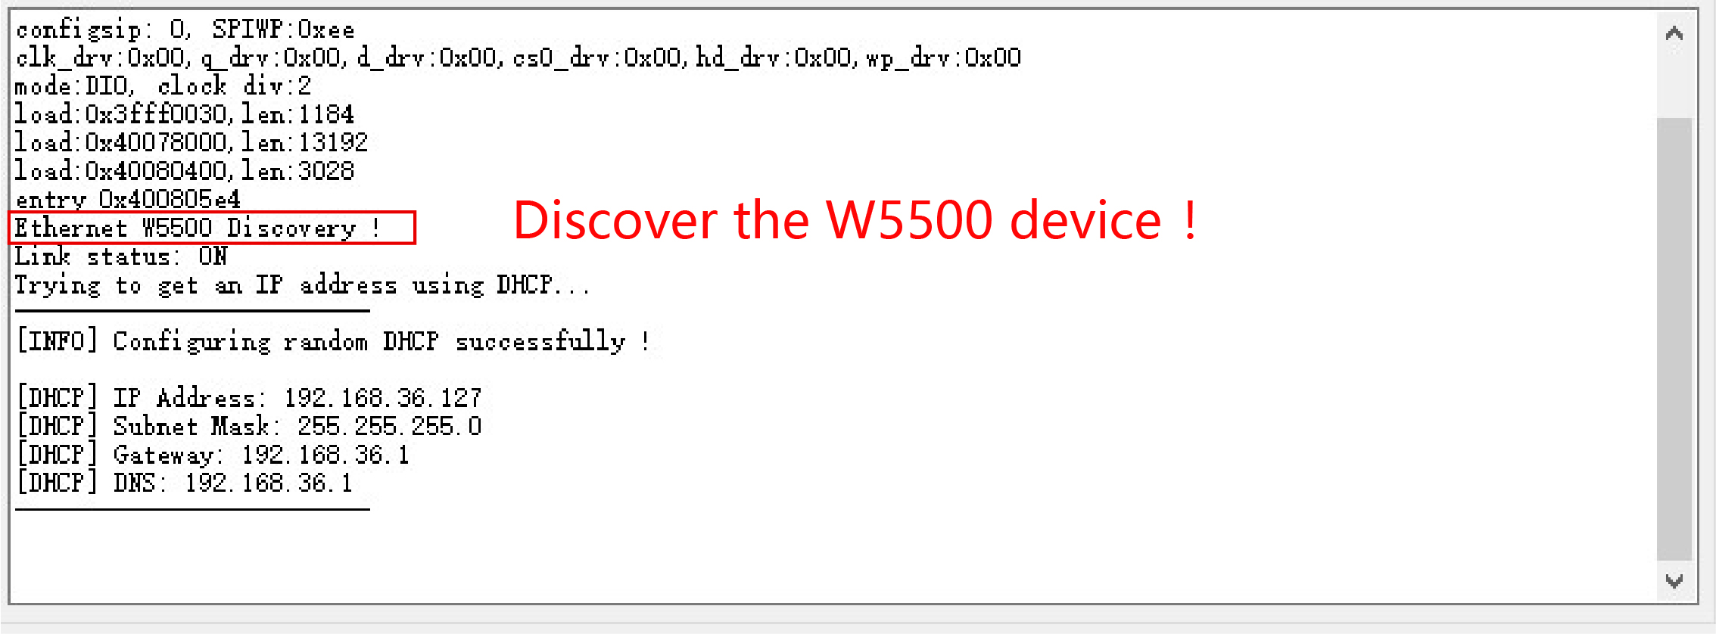
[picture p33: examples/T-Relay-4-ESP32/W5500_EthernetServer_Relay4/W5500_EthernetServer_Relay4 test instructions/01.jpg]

* 1.2 Otherwise, it will display "Ethernet No Hardware". 
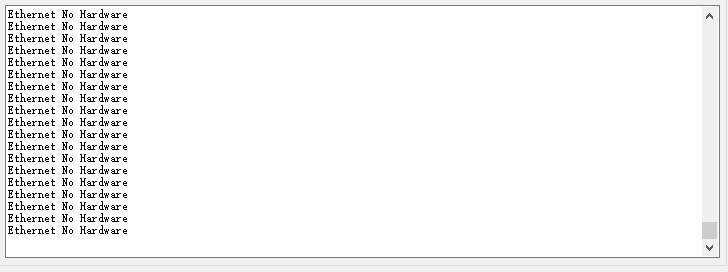
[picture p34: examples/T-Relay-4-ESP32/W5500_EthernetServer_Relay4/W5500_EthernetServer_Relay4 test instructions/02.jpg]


### 2.Whether the Ethernet jack and W5500 chip can communicate properly
* 2.1 After the W5500 device is correctly recognized, insert the router-connected Ethernet cable, and you will see "Link status: ON" on the serial port, indicating that the connection is normal. (There are 3 states: "Link status: ON" indicates a normal connection, "Link status: OFF" indicates that the Ethernet port is not plugged in, and "Link status: Unknown" indicates an unknown connection, which is a hardware error and the W5500 and Ethernet port cannot communicate.) 
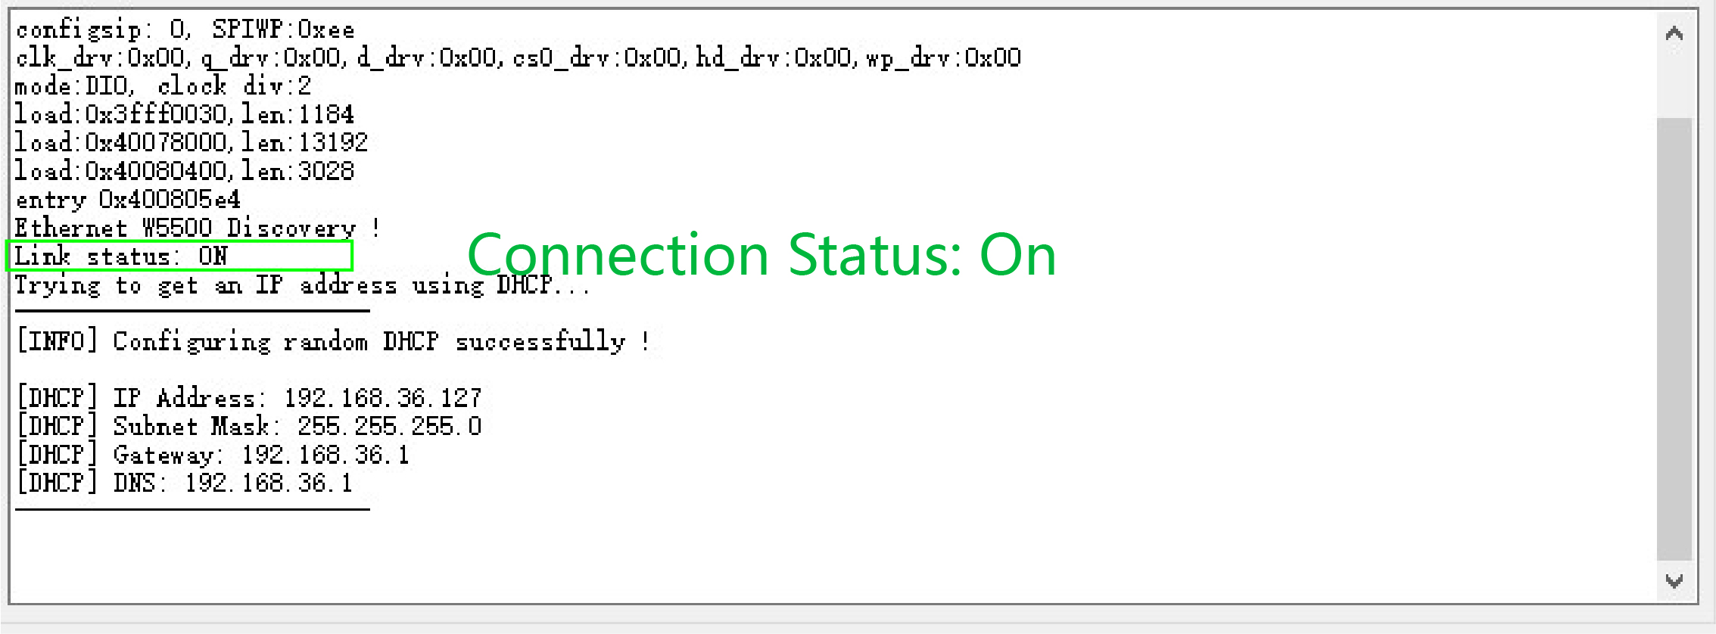
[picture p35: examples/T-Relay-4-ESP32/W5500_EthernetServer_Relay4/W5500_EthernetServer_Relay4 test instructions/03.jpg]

* 2.2 After the W5500 device is correctly recognized, but without inserting the Ethernet cable, it will display "The network cable is not connected!", "Please insert the network cable and try again!", indicating that the Ethernet cable is not inserted, please insert the Ethernet cable and try again. 
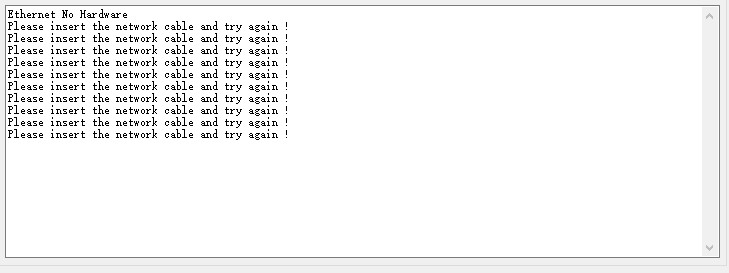
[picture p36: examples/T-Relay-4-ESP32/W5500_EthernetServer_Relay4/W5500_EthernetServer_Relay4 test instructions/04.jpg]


### 3.Whether it can obtain a dynamic IP address (DHCP) properly
* 3.1 If the W5500 can be correctly recognized and the Ethernet cable is connected properly, the system will automatically obtain a random IP address from the router. After waiting for a few seconds, the obtained network IP information will be output to the serial port. 
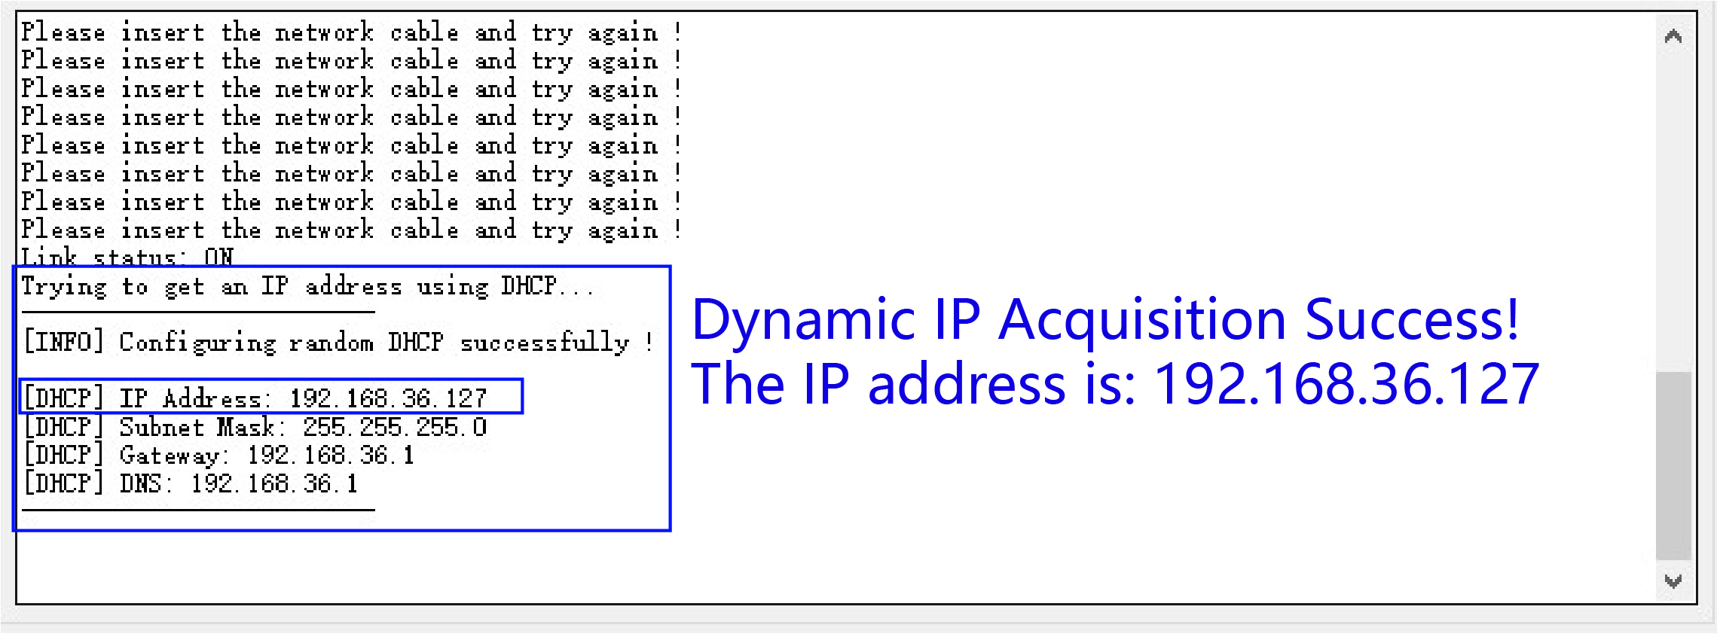
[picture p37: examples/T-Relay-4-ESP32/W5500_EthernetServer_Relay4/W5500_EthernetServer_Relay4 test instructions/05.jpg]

* 3.2 If there are any unexpected situations during the connection (such as plugging in a non-router device into the Ethernet port, or disconnecting during the connection), a static IP address will be assigned. 
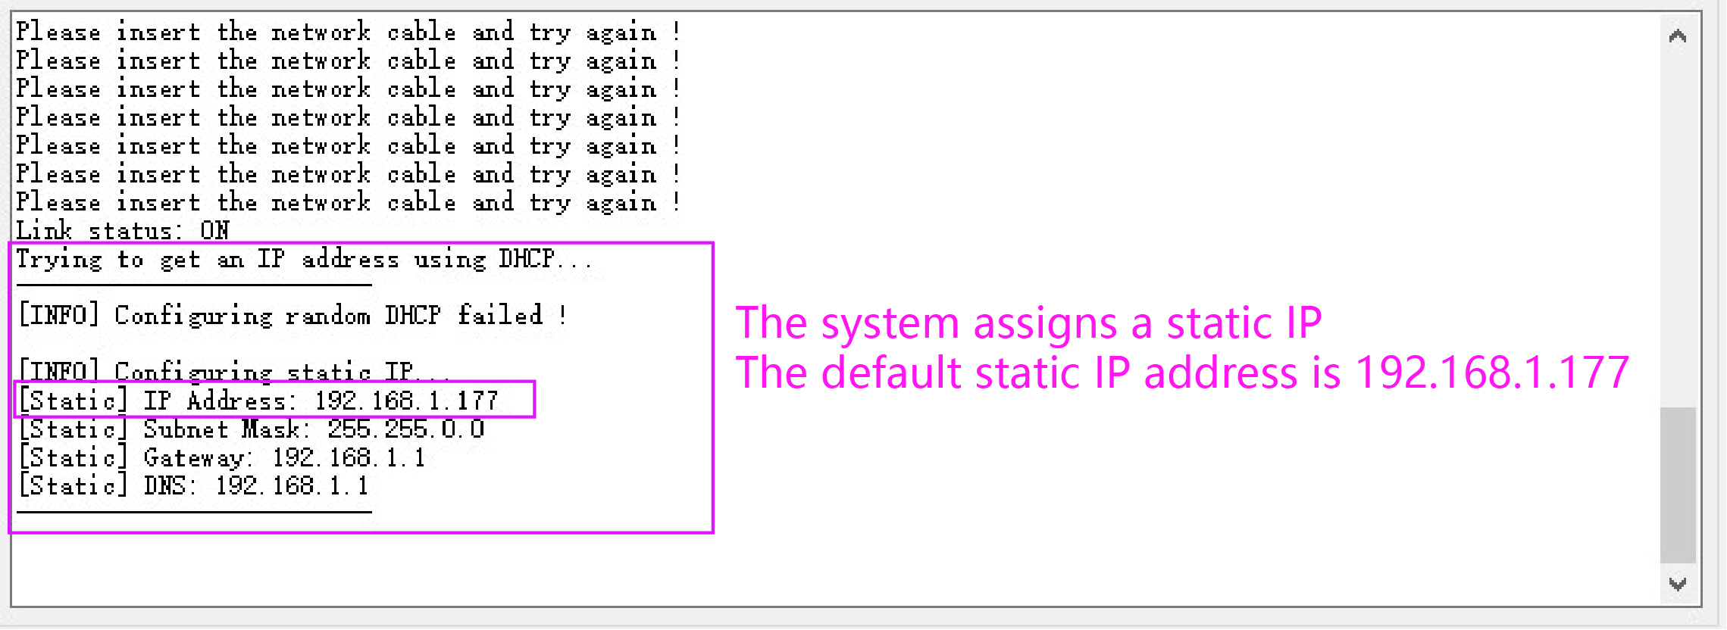
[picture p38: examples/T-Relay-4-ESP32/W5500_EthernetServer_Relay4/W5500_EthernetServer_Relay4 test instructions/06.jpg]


### 4.Whether the relays can be controlled through the web interface
* 4.1 Open the browser on your mobile phone or computer and enter the dynamic IP address (DHCP) assigned by the router, which is displayed on the serial port in 3.1. You will see the LilyGo-T-Relay-4W5500 Ethernet Server Test interface, which has 4 relay control options. If you are using the LilyGo-T-Relay-8 development board, the LilyGo-T-Relay-8W5500 Ethernet Server Test interface will be displayed, which has 8 relay control options. 
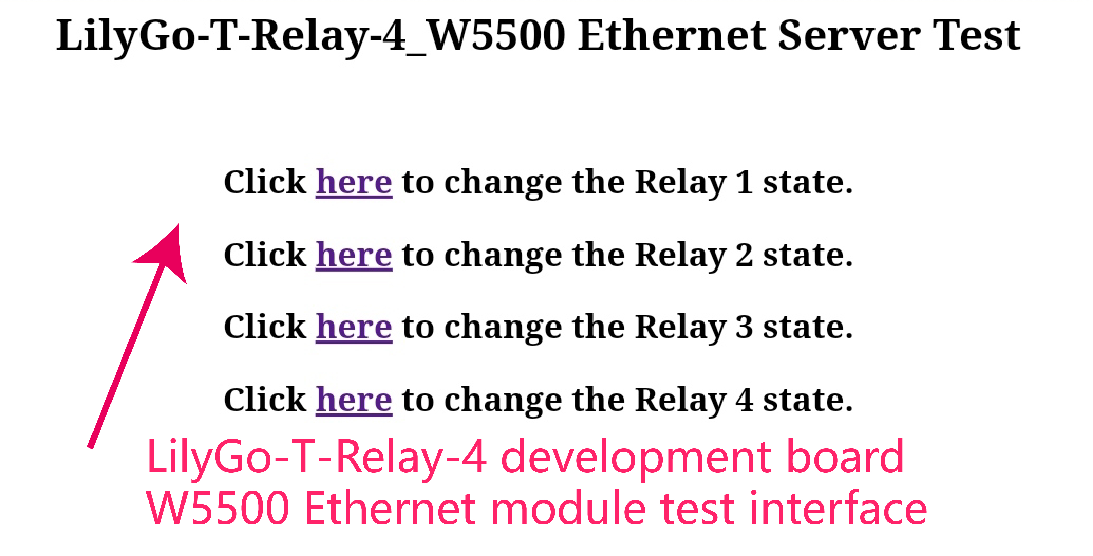
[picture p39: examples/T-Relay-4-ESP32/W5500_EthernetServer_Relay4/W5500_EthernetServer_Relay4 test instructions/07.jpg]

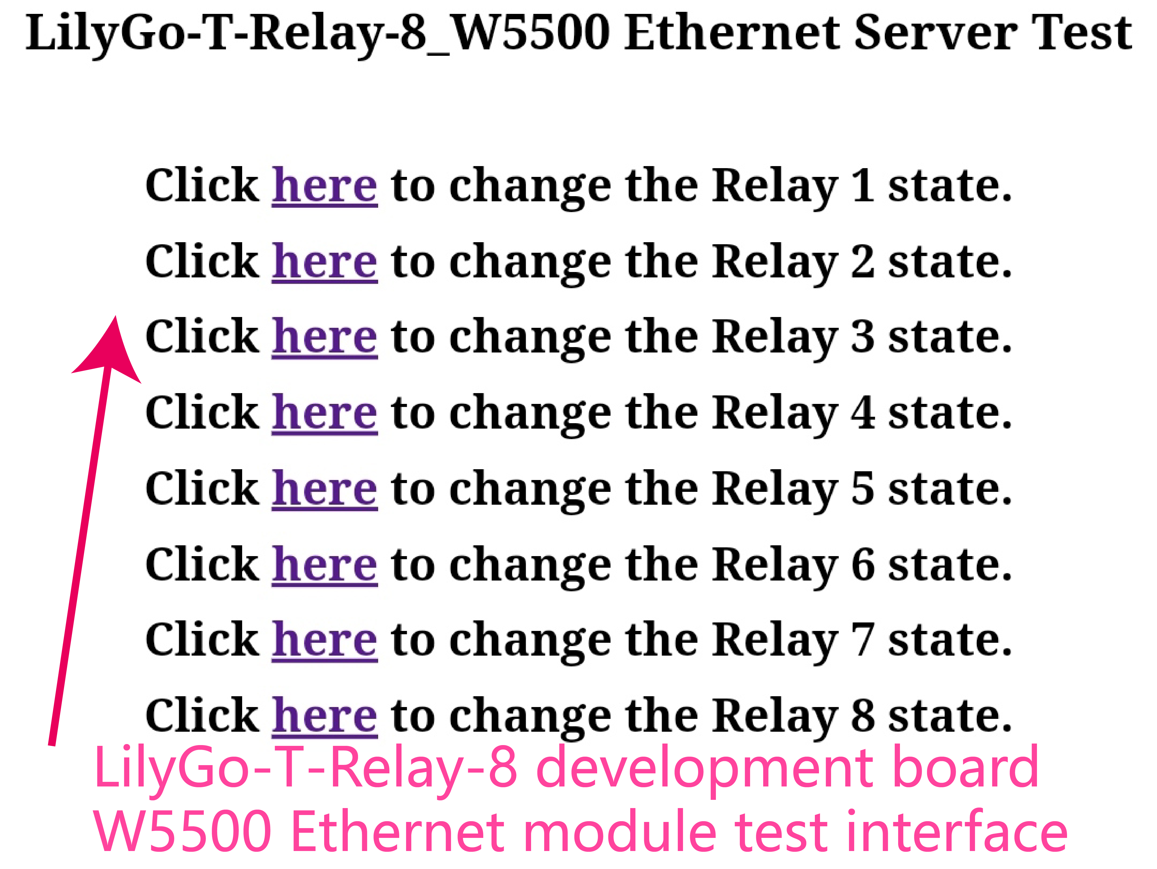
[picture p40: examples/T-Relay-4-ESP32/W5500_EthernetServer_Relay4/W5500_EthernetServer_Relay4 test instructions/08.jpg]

* 4.2 Click on "here" on the web page to control the opening and closing of the relays.

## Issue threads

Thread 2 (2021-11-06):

Is it possible to add external anten for Wifi  ?

David-2D3FE9, 2021-11-06:
Hello first of all, thank you for the versatily and the quality of your products.
I am realy enjoy to discover your T-Relay board and I am wondering if it is possible to add an external antenna for the wifi.

On the product picture it seem to have pads near ESP32,
Is it for soldering an SMA connector for external Wifi Antenna ?

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

Thanks in advance for your response

LilyGO, 2021-11-09:
Hello. Modules have onboard antennas. If external antennas are used, jump resistors and weld antenna seats are required.

David-2D3FE9, 2021-11-24:
Thanks for your response.
My delivery isdelayed so I will see that in January :-)

Closed 2021-11-24.

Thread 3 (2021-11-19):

What is the maximum current rating for the relay ?

X-Ryl669, 2021-11-19:
I see you have mounted 10A relay. Are the screw terminal block and PCB trace matched for 10A ?

LilyGO, 2021-11-20:
Yes. You can refer to the parameters of the relay

X-Ryl669, 2021-11-20:
The trace width seems like they are 3.8mm on the bottom layer but 7.6mm is required to pass 10A on a 1oz PCB (unless there is a trace going under the relay themselves on the top layer too).
Is the PCB copper layer made of 2oz ?
Or is there a trace on the relay pin on the top layer too ?

LilyGO, 2021-11-22:
Yes, it is not recommended to exceed the limit value.

SublimeMudTime, 2022-03-04:
It almost looks like there are traces for the relay on the top and bottom when examining my board. And 2 X 3.8 = 7.6 so it seems ok...

X-Ryl669, 2022-03-04:
Thanks! I've received mine recently and indeed, there are traces on both side so it's ok.

Closed 2022-03-04.

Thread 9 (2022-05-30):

Pin swap required on the connector

X-Ryl669, 2022-05-30:
Hi,

For a future version, it would be better if you could swap the Vcc (3.3V) and GND on the pins row:
```
[... | 15 | 14 | Gnd | Gnd ]
[... | 04 | 02 | 3.3V| 3.3V]
```
to this instead
```
[... | 15 | 14 | 3.3V| Gnd ]
[... | 04 | 02 | 3.3V| Gnd ]
```

Because if you want to make independent connectors, you're more likely to use rows (15,14,Vcc,Gnd) and (4,2,Vcc,Gnd) than columns.

iwoodcock1952, 2022-11-28:
I have 4-relay item. IO21 is normally default I2C SDA..which pin is assigned I2C in this case?

X-Ryl669, 2022-11-28:
You choose what pin to use when instantiating the I2C driver. It's free to use any of them except 32-39 that are readonly IIRC.

iwoodcock1952, 2022-12-01:
Dear Sirs,

I am trying to use the LILYGO ESP32  2021-7-16 V1.0 Relay unit with ESP32
but I find it is almost impossible to program it.

Sometimes randomly it accepts a program, but then refuses to accept
revisions.

I am using Arduino 1.8.18 on latest updated Windows 10.

My aim is to use the dual core capability but it is very difficult when I
can not upload program updates.

Website is no help. Github no help.

It is probable I will discontinue the use of these devices in my projects,
unless you can provide a CLEAR and UNAMBIGUOUS guide how to upload programs
reliably.

KInds regards

Ian Woodcock

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

ZaleAnderson, 2022-12-09:
>
Hey, make sure you have a usb to ttl adapter for the board, it does not come with an on board converter so you need an external one

iwoodcock1952, 2022-12-09:
Good morning
Yes thanks I have the connector.
What I have so far failed is to get the relay unit to detect any i2c
devices using suggestions I've seen on the internet.

Please provide your recommended code to assign i2c to pins 13 and 14 for
example

Kind regards

Ian Woodcock

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

jaseiffert, 2022-12-14:
> Dear Sirs, I am trying to use the LILYGO ESP32 2021-7-16 V1.0 Relay unit with ESP32 but I find it is almost impossible to program it. Sometimes randomly it accepts a program, but then refuses to accept revisions. I am using Arduino 1.8.18 on latest updated Windows 10. My aim is to use the dual core capability but it is very difficult when I can not upload program updates. Website is no help. Github no help. It is probable I will discontinue the use of these devices in my projects, unless you can provide a CLEAR and UNAMBIGUOUS guide how to upload programs reliably. KInds regards Ian Woodcock
> […](#)
> On Mon, 28 Nov 2022 at 15:52, X-Ryl669 ***@***.***> wrote: You choose what pin to use when instantiating the I2C driver. It's free to use any of them except 32-39 that are readonly IIRC. — Reply to this email directly, view it on GitHub <[#9 (comment)](https://github.com/Xinyuan-LilyGO/LilyGo-T-Relay/issues/9#issuecomment-1329333293)>, or unsubscribe <https://github.com/notifications/unsubscribe-auth/ATHI45SO7ZUTHKOWOZSOGKTWKTIKZANCNFSM5XKRMOQQ> . You are receiving this because you commented.Message ID: ***@***.***>

I've had problems with my T-U2T Adapter and had intermittent problems till I pushed the USB C cable into the T-U2T very far till I heard a click. It worked much better after that. I'm not sure why but there is barely any silver of the connector showing.

Thanks,

Jeffery

jaseiffert, 2022-12-14:
> Good morning Yes thanks I have the connector. What I have so far failed is to get the relay unit to detect any i2c devices using suggestions I've seen on the internet. Please provide your recommended code to assign i2c to pins 13 and 14 for example Kind regards Ian Woodcock
>

Depending on your I2C device you can use the following.

#include <Wire.h>

#define I2C_SDA 33
#define I2C_SCL 32
// set the pins you want to use

Under Void setup()
Wire.begin(I2C_SDA, I2C_SCL);

Some libraries you don't need the Wire.begin, just add the I2C_SDA and I2C_SCL to the libraries begin or init. You'll have to read how to do that for different I2C device libraries.

Random Nerd Tutorials is a great source for ESP32 Example and Programming help.

Thanks,

Jeffery

jaseiffert, 2022-12-14:
I'm also disappointed that the default I2C and SPI pins are used for the relays.

SPI can be used for displays.

If you ever make V2 revision of the board leave the I2C and SPI pins alone and use something else.

This board really needs an external Antenna connector for the ESP32.

Instead of using IO25 for a led, just connect the led to the 3v3 voltage coming out of the regulator as just a power indicator.

You could also use a PCF8574 I2C GPIO Expander to control the relays and leave the ESP32 ports available for other things but I'm no Electronics Engineer so I have no clue how involved it is. I've just seen others use this chip to control relays or other things when there are not enough ports available.

Also need the 8mb flash ESP32.

If it's a bit higher in price I think it would be well worth it with these changes.

Thanks,

Jeffery

jaseiffert, 2022-12-16:
This isn't a support forum. It's meant to report problems with their code.

I will answer this time but you should find a support forum like esp32.com or others to post your questions.

I only know two things to try. Pressing the reset button while it's trying to connect to upload your code or if you have a device connected to the I2C pins, to disconnect it so it gets an error and allow you to connect to upload your code.

Thanks,

Jeffery

iwoodcock1952, 2022-12-16:
Hello Jeffery,
Thanks for your reply. I tried both if yhe suggestionswith no success.
Incidentally* Both* of my lilygo boards are dead now, neither will function
with USB TTL dongle or a clean 12.5v supply.

The board is 100% what I wanted, but seems not to be suitable after all.
Thank you for assisting me in this case. I shall return to a system based
on separate components.

Regards

Ian

On Fri, 16 Dec 2022, 16:15 Jeffery Seiffert, ***@***.***>
wrote:

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

jaseiffert, 2022-12-16:
Hi Ian, I'm sorry your having trouble. I looked at the schematic and the reset is connected to the EN pin on the ESP32.
I had a problem with my dongle not making a good connection where the USB C cable plugged into it. I had to push a bit hard so it was fully in hearing a click. There is about 2mm of silver connector showing between the two.

Best of luck,

Jeffery

iwoodcock1952, 2022-12-16:
Jeffery,
Thanks, but I’ve abandoned hope!! The two boards I bought are both quite
dead. Even putting 12v into the power input, nothing happens.
Thanks for all your advice.
Cheers
Ian

On Fri, 16 Dec 2022 at 16:42, Jeffery Seiffert ***@***.***>
wrote:

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

N6RDV, 2023-01-10:
> Jeffery, Thanks, but I’ve abandoned hope!! The two boards I bought are both quite dead. Even putting 12v into the power input, nothing happens. Thanks for all your advice. Cheers Ian

Hey Ian,
I had the same exact issue with board flashing until I figured out that the problem is in incorrect USB-2-TTL driver installed on my Mac (most likely one used for HAM radio flashing cables).

You need to download and install CH341SER driver off http://www.wch-ic.com/ and re-flash both boards. I was able to revive the board that used to boot loop after my shenanigans with it via incorrect driver...

iwoodcock1952, 2023-01-11:
Hi Jeffery, I apprecuiate you coming back to me.
One of my boards has responded but I have decided that the need to amend my sketches to adapt to this board is more than I am capable of. I'm not a regular programmer it is a kind of hobby. I now prefer the uses of an ESP32 in Arduino format with a 4-relay shield. The ESP32 board I am using has three individual I2C connectors making it very simple to use. I have ZERO programming or uploading issues.. It is as pity. This board and its 8-relay partner could have been a very elegant solution for my project.
Kind regards
Ian

N6RDV, 2023-01-11:
Hi Ian,

I'm not Jeffrey. Just came across your discussion with him and chimed in

Using an eSP32 devkit + relay shield sounds reasonable if you need extra pins.
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
lewisxhe, 2023-02-26:
@jaseiffert 1. The power indicator uses CH7 and CH8 channels of the shift register, which are located in the middle of the circuit board
2. External RTC uses PCF8563
3. The DS18B20 is not installed by default, but is reserved
4. 20Pin Vin is 7~28V, which is used for additional boards
5. The VCC at the end of the circuit is 3v3. By default, these pins can be connected to the TFT display, because their order is the same as that of TFT
6. There are some reasons for the design of 6, because if the design is that the internal space of 4 is too small to put these components down, and the external expansion relay board has been designed, which is connected through the 20Pin seat in front of the circuit board

lewisxhe, 2023-02-26:
1. The board uses 3.3V level by default, and most matching sensors are compatible
2. At present, there is no plan to connect shunt resistance in series, and additional components and circuits are needed to measure the load consumption current
@X-Ryl669

jaseiffert, 2023-02-26:
>

On 1, I'm not sure what you mean exactly, Can CH7 and CH8 be used in your program so you could use it to indicate power or a indicator for say the board is connected to WiFi?

2. If it is an external does the battery on the board supply power to something else? Most RTC boards I've seen have their own battery. Would there be a place to put Pins to fit one of these external boards or just use the I2C pins already there?
3. Great!
4. Ah, that makes much better sense that the connector if for additional boards and why it has Vin. Sounds Great.
5. Ah, when you said TFT I realized why those pins were lined up the way on the edge of the board. That's Great.
6. Yes, that makes sense. Sounds like you did a lot of thinking about this design and what would be useful.

Thanks for all the great information.

lewisxhe, 2023-02-27:
1. Yes, it can be used as an indicator light
2. CR1202 is only used as the backup power supply of RTC
@jaseiffert

lewisxhe, 2023-02-28:
The board has on-board RTC, which is located next to the logo of Lilygo. 3v3 * is a separate LDO, which allows external connection of 500mA load.

lewisxhe, 2023-02-28:
Under test…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

jaseiffert, 2023-02-28:
> The board has on-board RTC, which is located next to the logo of Lilygo. 3v3 * is a separate LDO, which allows external connection of 500mA load.

That's great!

The pictures are great. I really like your base and cover design. Looks like the Main relay board is DIN mountable and I'm guessing the Relay modules are too but can't really see.

It looks like a great setup! Although I wouldn't need that many relays but I'm sure there are others out there that would.

The daisy chain is a great idea!

The only thing that I think your really missing is an external antenna connection for the WiFi.
It definitely needs one weather you have it in a plastic box but especially in a metal box and it could be a bit far away so you could add a different size antenna for the distance.

Either way you should sell them with an external antenna connection.

Lately for my projects I've found having external antenna on the ESP32's is a great help as I've run into WiFi problems with the built-in ones and you get a greater range. I'm not sure if they have a dual function ESP32S3 that can do both but if not I'd go with the external antenna option. The cable and Antenna are cheap for a short one.

Looking great!!

Thanks,

Jeffery

lewisxhe, 2023-03-01:
I agree with you. I have considered the antenna problem you said. We may use the ESP32S3 module with IPEX antenna, so that users can connect their own external WiFi antenna, which is suitable for the occasions installed in the iron case

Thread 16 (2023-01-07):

Infinite boot loop after binary upload

N6RDV, 2023-01-07:
The board was alive upon receival, blinked using running light pattern when powered on via usb dongle
I attempted to upload the ESPHome sketch from this site and upload went to 100% but failed to verify the uploaded flash

Now the board is in infinite boot loop. Serial monitor shows infinite stream of
```
rst:0x10 (RTCWDT_RTC_RESET),boot:0x12 (SPI_FAST_FLASH_BOOT)
12:30:47.390 -> flash read err, 1000
12:30:47.390 -> ets_main.c 371
12:30:49.812 -> ets Jun  8 2016 00:22:57
```

I tried also connecting to the board via https://espressif.github.io/esptool-js/
Most of the times it fails to connect, but from time to time it does
So I tried uploading the binary via espressif js tool with the same effect
```
esptool.js v0.1-dev
Serial port WebSerial VendorID 0x1a86 ProductID 0x55d4
Connecting....
Detecting chip type... ESP32
Chip is ESP32-D0WD (revision 1)
Features: Wi-Fi, BT, Dual Core, 240MHz, VRef calibration in efuse, Coding Scheme None
Crystal is 40MHz
MAC: ....
Uploading stub...
Running stub...
Stub running...
Changing baudrate to 921600
Changed
Compressed 3084992 bytes to 258749...
Writing at 0x1000... (6%)
Writing at 0x5000... (12%)
Writing at 0x9000... (18%)
Writing at 0xd000... (25%)
Writing at 0x11000... (31%)
Writing at 0x15000... (37%)
Writing at 0x19000... (43%)
Writing at 0x1d000... (50%)
Writing at 0x21000... (56%)
Writing at 0x25000... (62%)
Writing at 0x29000... (68%)
Writing at 0x2d000... (75%)
Writing at 0x31000... (81%)
Writing at 0x35000... (87%)
Writing at 0x39000... (93%)
Writing at 0x3d000... (100%)
Wrote 3084992 bytes (258749 compressed) at 0x1000 in 2.918 seconds.
File  md5: 916dae96966cbb74d0c914e77c70cb76
Flash md5: 4fa117c057552d512f686f7e56fc4fdf
Error: MD5 of file does not match data in flash!
```

Bad hardware? Should I try another t-relay board, or there's a way to revive this one?

N6RDV, 2023-01-11:
Figured out that the problem was in a wrong USB driver used to flash the board via cable.

Closed 2023-01-11.

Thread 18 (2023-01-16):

Configure the pins for I2C

rogeriopedroso, 2023-01-16:
Hello everybody,
I need to configure I2C, and I can't do it using the wire.begin(26, 14) method. Can someone explain to me how I configure the pins for I2C

trothe, 2023-02-17:
I ran into the same issue and managed to make it work like this:

```c
#include <Wire.h>

#define I2C_SDA 33
#define I2C_SCL 32

void setup() {
  Wire.begin(I2C_SDA, I2C_SCL);
}
```

Here the full example for reading a BME280:

```c
#include <Wire.h>
#include <Adafruit_Sensor.h>
#include <Adafruit_BME280.h>

#define I2C_SDA 33
#define I2C_SCL 32

Adafruit_BME280 bme;

void setup() {

  Wire.begin(I2C_SDA, I2C_SCL);

  Serial.begin(9600);
  // while (!Serial);

  if (!bme.begin(0x76)) {
    Serial.println("Error, check I2c address and wiring!");
    while (1);
  }
}

void loop() {
  Serial.print("Temp:");
  Serial.print(bme.readTemperature());
  Serial.println("*C");

  Serial.print("Pressure:");
  Serial.print(bme.readPressure() / 100.0F);
  Serial.println("hPa");

  Serial.print("Humidity:");
  Serial.print(bme.readHumidity());
  Serial.println("%");

  Serial.println();
  delay(1000);
}

```

supermarioprof, 2023-08-03:
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

How do you physically connect to pin 32 and 33? soldering directly to the ESP32 board on the T-relay board?
and, how can you use this pins for I2C whyle using for controlling relays?
on T-relay 8X pins 32 and 33 are connected to relays K1 and K2

TAMILOLI, 2024-02-03:
Hi, We are use it **T_Relay4_ESP32** with **I2C**. In our development is IDF. we set it as pin into **SDA - 26, SCL - 14.** But Not Working as to LCD Display. Please Give me solution. In our code reference is [](https://esp32tutorials.com/i2c-lcd-esp32-esp-idf/)

trothe, 2024-02-03:
> Hi, We are use it **T_Relay4_ESP32** with **I2C**. In our development is IDF. we set it as pin into **SDA - 26, SCL - 14.** But Not Working as to LCD Display. Please Give me solution. In our code reference is https://esp32tutorials.com/i2c-lcd-esp32-esp-idf/

In my case on the T_Relay4 it was SDA 33 SCL 32. Maybe the T-Relay 8x is using other pins. you should give it a try.

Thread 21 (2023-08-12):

Installing tasmota in T-RelayS3

Nachorov027, 2023-08-12:
Hi, I'm trying to install the full tasmota firmware in this device. I've compiled tasmota source with the #define USE_SHIFT595 and I have my board flashed and runnig but now, I'm stuck in how to configure Tasmota to the proper pins of TRelayS3

Tasmota Signals are labeled :
74x595  SRCLK
74x595 RCLK
74x595 OE
74595  SER

How do this signal match with GPIOS in your board?

Any clue in how to be abel to have this board (and extension) up and running?

Thx!!!

lewisxhe, 2023-08-12:
I have not used tasmota, the CH595 of Relays3 is bound to the relay, you need to drive the relay, you only need to drive the CH595

Nachorov027, 2023-08-14:
I finally get it working. These are the steps in case someone needs it. I'll also submit this info to the blacadder website.

First, you need to compila tasmota with these options:

`#define USE_SHIFT595
#define USE_RTC_CHIPS               // Enable RTC chip support and NTP server
#define USE_DS3231                  // [I2cDriver26] Enable DS3231 RTC (I2C address 0x68) (+1k2 code)
#define USE_RTC_ADDR    0x51`

My recomendation, use tasmocompiler docker: You simple create a new docker

`docker pull benzino77/tasmocompiler

docker run --rm --name tasmocompiler -p 3000:3000 benzino77/tasmocompiler`
point your browser http://<you_broker_host>:3000

It will first ask you to update to the latest tasmota code. If done it with V13, but its always good to go with the latest version (if it works :))
Click Next and it will ask you to enter your wifi settings. If you leave this blank, you'll get the regular Tasmota-xxxx ap to configure the relay board.
Click next and you'll get a screen full of options. You MUST select ESP32 S3 in the second block and "humidity and temp sensors" (in order to enable I2C support and to be able to use the DS18B20 port available in TRELAY-S3,
Click nect and youl get a "Personal Config Parameters" screen, copy and paste these:
`#define USE_SHIFT595
#define USE_RTC_CHIPS               // Enable RTC chip support and NTP server
#define USE_DS3231                  // [I2cDriver26] Enable DS3231 RTC (I2C address 0x68) (+1k2 code)
#define USE_RTC_ADDR    0x51`
Click next, and select tastmota version and languaje and finally, click "Compile"

It will take a few minutes, but when it finished, you'll find foyr buttons, click "Download Firmware_factory.bin" (VERY IMPORTAN, use the factory version of the .bin file!)

Once you have it downloaded, flash it on your RELAY with  (you will have to install esptool if you don't have it already)
`esptool write_flash 0x0  firmwate.factory.bin`

To put your device in flashmode, just push the reset button (the one on the right), keep holding reset and push the boot mode button (left one), release reset and release boot. Then issue the previous command.

Once flashing finish, reset again your relay board and configure wifi the usual tasmota way (unless you have already place the wifi data at compile time).

FINAL STEPS!

Go to Tasmota web in your device, click in "Configuration", and then click on "Extra Config". Once in this menu paste in the "Template" textbox the follwing json:
`{"NAME":"LilyGo T-RealyS3","GPIO":[8352,1,1,1,1,8288,8320,8384,1,1,1,1,1,1,1,1,640,608,1,1,1,1,0,0,0,0,0,1,1,1,1,1,1,1,1,1,1,1],"FLAG":0,"BASE":1}`
and click, "Activate"
Go back to the main menu and voila! you have 8 relays. Relay 1-6 are the relays at the board, 7 and 8 are the red and green led.

If you have an extension board, you need to do one more thing to enable it.
Go to consoles menu, the first option (Console) and type this command:
`Shift595DeviceCount 2`
Number 2 means that you have 2 devices (main+extensions). If you have 2 extension, put 3, and so. on...

Hope it helps someone, it took me several hours to make it!!
Regards

lewisxhe, 2023-08-14:
Good job.

diegozalez, 2024-09-07:
Hi there is a problem with the new revision boards
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
As you can see enable the pin of the HT74HC595ARZ I pull high and it makes it really frustrating because if you follow all your steps it looks like everything is working but it is not.

I did a quick fix where I set GPIO 4 as a relay and if you turn it on it disables the relays and low to activate the output.

Do you suggest another way and maybe modify the template?

Thanks for your time it helps a lot.

lewisxhe, 2024-09-09:
New version When booting, you need to set GPIO4 to low to drive CH595

diegozalez, 2024-09-10:
I've set GIPO4 to low on the device configuration do you recommend a better way to do this?

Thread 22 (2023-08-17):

T-Relay S3 Chain in ESP Home

Misiu, 2023-08-17:
T-Relay S3 supports up to 3 expansion boars to have up to 24 relays.
I'd like to ask for an example with an expansion board, so it will be easier for beginners (like me) to get started.

Also, do I need additional hardware (T-U2T) to connect the board to PC?
Sadly I can't find any information and I want to buy all parts that are needed at once.

Misiu, 2023-10-10:
@LilyGO ping :)

lewisxhe, 2023-12-25:
T-Relay S3 is based on ESP32S3 and does not require an additional downloader. I think it has already been mentioned in README that programming can be done directly by inserting USB
https://github.com/xinyuan-lilygo/lilygo-t-relay/blob/main/docs/relay_esp32s3.md

lewisxhe, 2023-12-25:
The expansion board does not require special examples, only the number of relays in the sketch needs to be changed

Misiu, 2023-12-30:
@lewisxhe thank you for the reply,
I'm not sure if I need to add another hub or should I use the same hub and use other switches.
According to https://esphome.io/components/sn74hc595.html one SN74HC595 can be used with 8 pins, if you want to use more you must daisy chain them, but I don't know how to configure that in ESPHome.
Guess I'll wait for the board to be available on my local amazon to be able to order it and rest everything with option to return the board if something doesn't work.

fgastald, 2024-02-10:
same problem here cannot find adeguate informations for configure correctly the YAML file.

szab0lcs, 2024-04-01:
Here is my working code in ESPHome.
The `sr_count` is define how many chains is daisy chained together.
```yaml
esphome:
  name: test-6-relay
  friendly_name: Test 6 Relay

esp32:
  board: esp32-s3-devkitc-1
  framework:
    type: arduino

sn74hc595:
  - id: "sn74hc595_hub"
    data_pin: 7
    clock_pin: 5
    latch_pin: 6
    sr_count: 2

# Individual outputs
switch:
  - platform: gpio
    # SN74HC595 Pin #0
    name: "Switch 1"
    pin:
      sn74hc595: sn74hc595_hub
      # Use pin number 0
      number: 0
      inverted: false
      id: relay1

  - platform: gpio
    # SN74HC595 Pin #1
    name: "Switch 2"
    pin:
      sn74hc595: sn74hc595_hub
      # Use pin number 1
      number: 1
      inverted: false
      id: relay2

  - platform: gpio
    # SN74HC595 Pin #2
    name: "Switch 3"
    pin:
      sn74hc595: sn74hc595_hub
      # Use pin number 2
      number: 2
      inverted: false
      id: relay3

  - platform: gpio
    # SN74HC595 Pin #3
    name: "Switch 4"
    pin:
      sn74hc595: sn74hc595_hub
      # Use pin number 3
      number: 3
      inverted: false
      id: relay4

  - platform: gpio
    # SN74HC595 Pin #4
    name: "Switch 5"
    pin:
      sn74hc595: sn74hc595_hub
      # Use pin number 4
      number: 4
      inverted: false
      id: relay5

  - platform: gpio
    # SN74HC595 Pin #5
    name: "Switch 6"
    pin:
      sn74hc595: sn74hc595_hub
      # Use pin number 5
      number: 5
      inverted: false
      id: relay6

  - platform: gpio
    # SN74HC595 Pin #8 chain: 1
    name: "Switch Chain_1"
    pin:
      sn74hc595: sn74hc595_hub
      # Use pin number 8
      number: 8
      inverted: false
      id: relay1_chain

  - platform: gpio
    # SN74HC595 Pin #9 chain: 2
    name: "Switch Chain_2"
    pin:
      sn74hc595: sn74hc595_hub
      # Use pin number 9
      number: 9
      inverted: false
      id: relay2_chain

  - platform: gpio
    # SN74HC595 Pin #10 chain: 3
    name: "Switch Chain_3"
    pin:
      sn74hc595: sn74hc595_hub
      # Use pin number 10
      number: 10
      inverted: false
      id: relay3_chain

  - platform: gpio
    # SN74HC595 Pin #11 chain: 4
    name: "Switch Chain_4"
    pin:
      sn74hc595: sn74hc595_hub
      # Use pin number 11
      number: 11
      inverted: false
      id: relay4_chain

  - platform: gpio
    # SN74HC595 Pin #12 chain: 5
    name: "Switch Chain_5"
    pin:
      sn74hc595: sn74hc595_hub
      # Use pin number 12
      number: 12
      inverted: false
      id: relay5_chain

  - platform: gpio
    # SN74HC595 Pin #13 chain: 6
    name: "Switch Chain_6"
    pin:
      sn74hc595: sn74hc595_hub
      # Use pin number 13
      number: 13
      inverted: false
      id: relay6_chain

# Enable logging
logger:

# Enable Home Assistant API
api:
  encryption:
    key: "XXXXXXXXXXXXXXXXXXXXXXXXXXXXXXXX"

ota:
  password: "XXXXXXXXXXXXXXXX"

wifi:
  ssid: !secret wifi_ssid
  password: !secret wifi_password

  # Enable fallback hotspot (captive portal) in case wifi connection fails
  ap:
    ssid: "Test-6-Relay Fallback Hotspot"
    password: "ZBnPdRLZ3foz"

captive_portal:
```

Misiu, 2024-04-02:
@szab0lcs thank you for sharing your code.
Did you have flickering issues - https://github.com/Xinyuan-LilyGO/LilyGo-T-Relay/issues/24#issuecomment-1868701351
When you restart the device does any of the repays turn on/off? I want to use T-Relay S3 as a garage controller to control doors and read a couple of DS18B20 sensors.

szab0lcs, 2024-04-02:
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

Yes I have but I will try to solve that issue. If I get any solution I'll keep you posted.

szab0lcs, 2024-04-03:
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

https://github.com/Xinyuan-LilyGO/LilyGo-T-Relay/issues/24#issuecomment-2034384008

cremer42, 2024-09-25:
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

@szab0lcs I basically copied your yaml, loaded it to my board I got today and I cannot get relays to even function.... Am I missing something?

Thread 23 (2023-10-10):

ESPHome example of T-Relay 5V 8 Channel Relay and T-Relay W5500 Shield

Misiu, 2023-10-10:
First of all, thank you for creating this repository with sample configurations.
I'd like to ask for additional config for T-Relay with W5500 Shield and ESPHome.

Thank you :)

lewisxhe, 2023-12-25:
I searched for Ephome and currently do not have any components for w5500

B48D81EFCC, 2024-07-25:
Hi,

ESPHome supports W5500 now.

bartoszkaminski, 2025-01-21:
Hi! I'm also trying to get T-Relay 8 channel to work with T-Relay W5500 Shield using ESPHome. Do you by any change have any working example?

lewisxhe, 2025-01-22:
Since I don't have actual hardware to test, you could try testing this

```c
esphome:
  name: t-relay-8

esp32:
  board: esp32dev
  framework:
    type: arduino

# Enable logging
logger:

# wifi:
#   ssid: "ssid"
#   password: "password"

#   # Enable fallback hotspot (captive portal) in case wifi connection fails
#   ap:
#     ssid: "T-Relay Fallback Hotspot"
#     password: "g8TaLY13NVW6"

ethernet:
  type: W5500
  clk_pin: GPIO22
  mosi_pin: GPIO26
  miso_pin: GPIO34
  cs_pin: GPIO27
  interrupt_pin: GPIO36
  reset_pin: GPIO23

switch:
  - platform: gpio
    pin: GPIO33
    name: "Relay #1"
    id: relay1

  - platform: gpio
    pin: GPIO32
    name: "Relay #2"
    id: relay2

  - platform: gpio
    pin: GPIO13
    name: "Relay #3"
    id: relay3

  - platform: gpio
    pin: GPIO12
    name: "Relay #4"
    id: relay4

  - platform: gpio
    pin: GPIO21
    name: "Relay #5"
    id: relay5

  - platform: gpio
    pin: GPIO19
    name: "Relay #6"
    id: relay6

  - platform: gpio
    pin: GPIO18
    name: "Relay #7"
    id: relay7

  - platform: gpio
    pin: GPIO5
    name: "Relay #8"
    id: relay8

captive_portal:
```

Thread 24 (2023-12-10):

Prevent relay trigger on boot or reset with esphome code

davidusb-geek, 2023-12-10:
I'm using a very similar code to the one here for esphome and Home Assistant.
Everything works fine except that when the board resets or reboot all the relay are triggered.
Very inconvenient when controlling a garage door for example.
Any suggestions to solve this and avoid these relay triggering?
I have tried some solutions using the relay options on esphome (ALWAYS_OFF, etc.) but without success.
Any help will be much appreciated.

Misiu, 2023-12-18:
@davidusb-geek what model or relay are you using (T-Relay, T-Relay 8, or T-Relay S3)?
I'm thinking about ordering those relays and I'd like to know did you solved the issue you described.
I also want to use it to control garage doors, so I can't allow random opening.
Thank you for the reply.

davidusb-geek, 2023-12-18:
I'm using the t-relay 8.
The issue is not solved, it's open.
So I disconnected the garage door for now.

Misiu, 2023-12-18:
Sad to hear that.
Mayby try to contact support via website chat.

davidusb-geek, 2023-12-23:
Oh man, I've just solved this after months looking for a solution!
So the thing is that I've already tested with options `mode: INPUT_PULLUP` and `inverted: True` but without good results. But my problem was with indentation in my yaml for esphome. These parameters were just being ignored.
Today I just found that the correct way to pass this parameters and make my switch work without triggering at boot is this:

First define the output pins:
```
output:
  - platform: gpio
    pin:
      number: GPIO33
      mode: INPUT_PULLUP
      inverted: True
    id: output_pin_1 # garage door
```

Then I define my switch for the garage door like this:
```
switch:
  - platform: output
    restore_mode: ALWAYS_OFF
    id: garage_door_bare_switch
    output: output_pin_1
  - platform: template
    restore_mode: ALWAYS_OFF
    name: "Garage Door Switch"
    icon: "mdi:garage"
    id: garage_door_bare_template_switch
    lambda: 'return id(garage_door_bare_switch).state;'
    turn_on_action:
      - switch.turn_on: garage_door_bare_switch
      - delay: 0.5s
      - switch.turn_off: garage_door_bare_switch
    turn_off_action:
      - switch.turn_on: garage_door_bare_switch
      - delay: 0.5s
      - switch.turn_off: garage_door_bare_switch
```

And that's it, works like charm.

Misiu, 2023-12-24:
@davidusb-geek thank you for sharing the solution :)
Now I think I order the boards with confidence.
Did you maybe attach the board to a DIN rail? I was searching for a mounting solution and I would like to know what you choose.

davidusb-geek, 2023-12-24:
Wait! I spoke too soon!
Actually the switch is not working. I thought it was fine because it didn't trigger at boot and it was showing fine on Home Assistant (and it was very late yesterday night) . But it is not working, the switch is not responding. My guess is that the INPUT_PULLUP is not supported by the hardware.
I'm reopening the issue :-(

davidusb-geek, 2023-12-24:
Yes I'm using DIN rail. I'll post the aliexpress link for that piece. It is a shame that I have this issue because the board quality is very good.

davidusb-geek, 2023-12-24:
These DIN supports work fine: Just found this amazing item on AliExpress. Check it out! 0,34€ | 1 Pair DRG-01 PCB Mounting Brackets Screws Green For DIN 35 Mounting Rails Adapter Replacements Parts
https://a.aliexpress.com/_EwgujuV

lewisxhe, 2023-12-25:
Relay4/realy8 should not have this problem, but there is indeed a chance that this problem will occur on realy6

davidusb-geek, 2023-12-25:
Ok I will try the INPUT_PULLUP option on relay4 or relay8 and see how it goes.

davidusb-geek, 2023-12-30:
> Relay4/realy8 should not have this problem, but there is indeed a chance that this problem will occur on realy6

I just tested it on relay 4 (ie. GPIO21), still doesn't works.

Misiu, 2023-12-30:
> Relay4/realy8 should not have this problem, but there is indeed a chance that this problem will occur on realy6

@lewisxhe could you please say more about relay6 (T-Relay S3)? I need to be 100% sure that the relays won't switch on/off after power loss. I want to control my garage door, so if this issue occurs my garage will open!

davidusb-geek, 2023-12-31:
> Relay4/realy8 should not have this problem, but there is indeed a chance that this problem will occur on realy6

So I completely misinterpreted this reply.

Misiu, 2023-12-31:
> > Relay4/realy8 should not have this problem, but there is indeed a chance that this problem will occur on realy6
>
> So I completely misinterpreted this reply.

I'm not sure if I understand it right. I'm assuming it was related to product types and not to relay in T-Relay 8

davidusb-geek, 2024-01-01:
Ok, got it working now! Tested it for real and everything is working fine and as expected.

I tested many options and finally got it working with this configutaion:
```
output:
  - platform: gpio
    pin:
      number: GPIO12
      inverted: True
      mode:
        pullup: True
        output: True
    id: output_pin_1 # garage door
```

The switch part of the yaml code is the same that I posted earlier in this issue.

Cheers!!!

Misiu, 2024-01-01:
@davidusb-geek thank you for sharing a solution. Yesterday I ordered a T-relay 8 board, it should arrive in about 3-4 weeks so I'll also test all the options.

szab0lcs, 2024-04-03:
I got it working with an easier method, the `mode: OUTPUT` was the key part:

```yaml
sn74hc595:
  - id: "sn74hc595_hub"
    data_pin: 7
    clock_pin: 5
    latch_pin: 6
    sr_count: 2

# Individual outputs
switch:
  - platform: gpio
    # SN74HC595 Pin #0
    name: "Switch 1"
    pin:
      sn74hc595: sn74hc595_hub
      # Use pin number 0
      number: 0
      inverted: false
      mode: OUTPUT
    id: relay1
```

forgotmyprozac, 2024-11-17:
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

Hey mate, I really like this board but the relays triggering on boot is killing me. What's the issue and how did you deal with it? I'm using ESPHome on the Lilygo T-Relay with Home Assistant. Thanks a bunch.

davidusb-geek, 2024-11-17:
> @davidusb-geek
>
> Hey mate, I really like this board but the relays triggering on boot is killing me. What's the issue and how did you deal with it? I'm using ESPHome on the Lilygo T-Relay with Home Assistant. Thanks a bunch.

Sorry to hear that. I also liked this board.
At first that solution that I posted worked and then some of these flickering came back.
I had enough with that so I changed to another board. I changed for the Kincony A4, working like charm, no more flickering problems.

Of course that requires changing the board. So probably try the solution proposed by @szab0lcs

lewisxhe, 2024-11-18:
@forgotmyprozac  Can you please tell me what version of your board is? Can you take a picture of the front of the board for me to see?

forgotmyprozac, 2024-11-18:
@lewisxhe

> @forgotmyprozac Can you please tell me what version of your board is? Can you take a picture of the front of the board for me to see?

Images below. Thank you.

https://i.ibb.co/Hzg5BXc/PXL-20241118-064935332.jpg
https://i.ibb.co/19ZnpMT/PXL-20241118-064929583.jpg
https://i.ibb.co/h1c5ypK/PXL-20241118-064924938.jpg

lewisxhe, 2024-11-18:
This is an early version and can be solved by adding a resistor, see the picture
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
@forgotmyprozac

lewisxhe, 2024-11-18:
After this change, 74HC595 will be enabled through GPIO4, and only GPIO4 low level can drive the relay

forgotmyprozac, 2024-11-18:
@lewisxhe
@davidusb-geek

> After this change, 74HC595 will be enabled through GPIO4, and only GPIO4 low level can drive the relay

Thank you very much for the help. What wattage for the resistor and what AWG wire for IO4?

What do you mean "after normal power on, set IO4 to LOW" > Do I need to set this in my code? So it will boot up and be high, then the code will pull it low, then relays can be used?

How can we tell what version the board is? I have another one coming from Aliexpress and want to know if it will have the same problem.

https://www.aliexpress.com/item/1005005576226160.html?spm=a2g0o.order_list.order_list_main.5.2e521802TrkVnZ

Thank you

lewisxhe, 2025-04-01:
The new version has a resistor here, and the version number is V1.1

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

Misiu, 2025-04-01:
Thank you for such a fast reply. Now I need to contact local sellers and ask for the board version. The rev must be 1.1 for the main board or also for the chain boards?
P.S. Thank you for the W5500 examples :)

lewisxhe, 2025-04-01:
Chain boards have not been updated, they are still the same as before, it should not affect

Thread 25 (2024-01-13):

Testing T-Relay W5500 Shield - discovery working but no LEDs (LinkOFF)

linkedupbits, 2024-01-13:
I have the T-4 relay and the T-Relay W5500 Shield and I am trying to get the sample working.

The W5500 initializes (serial monitor prints "Ethernet W5100 Discovery !") but
``` c++
Ethernet.linkStatus()
```
always returns LinkOFF, and the LEDs on the RJ45 socket do not light up.

I understand I should be able to test the LEDs simply by plugging in a live network cable and supplying 3.3v and Gnd to the W5500 (without having the T-relay connected) - just for testing.

Which of the header pins (other than the SPI) are used on the T-Relay W5500 Shield and are connected ?

There should be 3 x GND and two 3v3 as per the pinout, and the SPI communication appears to be working based on successful discovery.

Thanks in advance

Llgok, 2024-02-29:
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

Your Ethernet cable may not be properly connected.

After the W5500 device is correctly recognized, insert the router-connected Ethernet cable, and you will see "Link status: ON" on the serial port, indicating that the connection is normal. (There are 3 states: "Link status: ON" indicates a normal connection, "Link status: OFF" indicates that the Ethernet port is not plugged in, and "Link status: Unknown" indicates an unknown connection, which is a hardware error and the W5500 and Ethernet port cannot communicate.)

Closed 2024-07-10.

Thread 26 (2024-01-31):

Internal PCF8563 not incrementing with T-Relay S3 [H629]

Olli69, 2024-01-31:
Hi,
I tested internal PCF8563 rtc with the sample program RTC_PCF8563_TimeSynchronization. It got updates from ntp-server and set date/time to the rtc, but the rtc was not incrementing. For example just after ntp update loop() printed out
```
Hardware clock :Wednesday, January 31 2024 17:25:17
System   clock :Wednesday, January 31 2024 17:25:17
````
but 10 seconds later:
```

Hardware clock :Wednesday, January 31 2024 17:25:17
System   clock :Wednesday, January 31 2024 17:25:27
```

I had the same problem with Adafruit library as well as https://github.com/Makuna/Rtc library. Could it be a hardware problem? I just got the board from LilyGo (order 13992).

lewisxhe, 2024-01-31:
Can you use I2C scan to test whether PCF8563 is online?
Normally, as long as the PCF8563 is powered on, the time will accumulate.

Olli69, 2024-01-31:
> Can you use I2C scan to test whether PCF8563 is online? Normally, as long as the PCF8563 is powered on, the time will accumulate.

It has a fresh CR-1220 battery (does it save the static time but not accumulate?) . Also response from i2c scan (`WIRE.begin(16,17);`): `I2C device found at address 0x51  !`

lewisxhe, 2024-01-31:
Then I may suspect that the RTC crystal is not working properly. Is it possible for you to measure the clock waveform of 32.768khz?

Olli69, 2024-01-31:
I do have an oscilloscope, but not very professional with it. If you could send  a pic of pins to measure, I could try.

lewisxhe, 2024-01-31:
I will send it to you tomorrow and add instructions

lewisxhe, 2024-02-01:
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

Check these two pins, adjust the oscilloscope probe to the 10X gear, then adjust the period to 10us and the voltage to 50mV. If your oscilloscope supports period measurement, you can open the period measurement option and observe whether there is a 32.768khz waveform output.

Olli69, 2024-02-01:
I got quite nice sine waves from pin 1 and pin 2.  But are the voltage levels correct for PCF8563 to operate, OSCI between 356mV-828mV? I measured VDD voltage levels from PIN 8: 2.88V-3.12V.

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

lewisxhe, 2024-02-01:
There seems to be no problem. The crystal is already oscillating. You can try my test file to see if it accumulates every one second.

There seems to be no problem. The crystal is already oscillating. You can try my test file to see if it accumulates every one second.

[RTC_Firmware.zip](https://github.com/Xinyuan-LilyGO/LilyGo-T-Relay/files/14121926/RTC_Firmware.zip)

How to flash firmware , you can see here, the method is the same, the writing address is 0x0

https://github.com/Xinyuan-LilyGO/LilyGo-AMOLED-Series/blob/master/firmware/README.MD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

Olli69, 2024-02-01:
Thanks for additional diagnostics. I flashed your test file and it does not seem to accumulate.
```
Hardware clock :Monday, January 01 2024 00:00:00
Hardware clock :Monday, January 01 2024 00:00:00
Hardware clock :Monday, January 01 2024 00:00:00
Hardware clock :Monday, January 01 2024 00:00:00
Hardware clock :Monday, January 01 2024 00:00:00
Hardware clock :Monday, January 01 2024 00:00:00
Hardware clock :Monday, January 01 2024 00:00:00
```

lewisxhe, 2024-02-01:
@Olli69 Sorry for confusing you
At present, it seems from all aspects that the PCF8563 chip may be damaged, causing it to not work properly. Please contact customer service for after-sales service.

Olli69, 2024-02-01:
@lewisxhe , no problem! Thank you for prompt responses with diagnostics. So good that we got this far so quickly. I have contacted your sales and asked for a replacement board.

lewisxhe, 2024-02-01:
You're welcome. If you don't have any other questions, please close it.

Closed 2024-02-01.

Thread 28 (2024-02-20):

LilyGo-T-Relay w5500: Which hardware SPI Pins?

JFLSeoul, 2024-02-20:
Hello I just bought LilyGo-T-Relay 4 way and trying to add ethernet with a w5500 module (a standard one, not the LilyGo one) What are the correct Hardware SPI pins? On the homepage the picture shows: PIN_W5500_CLK IO22, PIN_W5500_MOSI IO26, PIN_W5500_MISO IO13, PIN_W5500_CS IO27, are those the correct pins ? I have tested the same shield with another esp32 without any problem, but having problems to get this running on the LilyGo...Thanks Joop

Llgok, 2024-02-29:
> Hello I just bought LilyGo-T-Relay 4 way and trying to add ethernet with a w5500 module (a standard one, not the LilyGo one) What are the correct Hardware SPI pins? On the homepage the picture shows: PIN_W5500_CLK IO22, PIN_W5500_MOSI IO26, PIN_W5500_MISO IO13, PIN_W5500_CS IO27, are those the correct pins ? I have tested the same shield with another esp32 without any problem, but having problems to get this running on the LilyGo...Thanks Joop

Hello,

The pin configuration for the W5500 module on the LilyGo-T-Relay-4 version is:
#define PIN_W5500_CLK 22
#define PIN_W5500_MISO 13 // LilyGo-T-Relay-4
#define PIN_W5500_MOSI 26
#define PIN_W5500_CS 27
#define PIN_W5500_RESET 23
#define PIN_W5500_INT 36

The pin configuration for the W5500 module on the LilyGo-T-Relay-8 version is:
#define PIN_W5500_CLK 22
#define PIN_W5500_MISO 34 // LilyGo-T-Relay-8
#define PIN_W5500_MOSI 26
#define PIN_W5500_CS 27
#define PIN_W5500_RESET 23
#define PIN_W5500_INT 36

Closed 2024-07-10.

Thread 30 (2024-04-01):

LilyGo T-Relay(6) S3 - pin assigments in documentation doesnt match schematic/reallity

LordRafa, 2024-04-01:
The pin assignments shown in [LilyGo T Relay S3](https://github.com/Xinyuan-LilyGO/LilyGo-T-Relay/blob/main/docs/RELAY_ESP32S3.MD) documentation doesn't match the [schematics](https://github.com/Xinyuan-LilyGO/LilyGo-T-Relay/blob/main/Schematic/T_Relay6_ESP32S3.pdf).

I think that these are the right ones:
static const uint8_t TX = 43;
static const uint8_t RX = 44;

static const uint8_t SDA = 16;
static const uint8_t SCL = 17;

// Temperature Sensor
static const uint8_t DSDATA = 21; // Not Connected

// RTC
static const uint8_t RTC_CLK32 = 15; // Not Connected
static const uint8_t RTC_INT = 18;

// HT74HC595ARZ

static const uint8_t SHIFT_REG_CLK   = 5
static const uint8_t SHIFT_REG_LATCH = 6
static const uint8_t SHIFT_REG_DATA  = 7

lewisxhe, 2024-04-05:
Thank you. It seems that the document was not changed in time after changing the GPIO. It has been corrected now.

Closed 2024-04-09.

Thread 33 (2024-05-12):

External pin setted with input pull-up is not working.

DAZABAMUKER, 2024-05-12:
I connected external pins with switches like images below.

At first, the switches worked well.
But now the external pins float(intermittently triggered)

how to fix it?

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

```
#include <PubSubClient.h>
#include <WiFi.h>

const char *ssid =  "########";
const char *password = "#######";

const char* ID = "Outdoor Lights";  // Name of our device, must be unique
const char* LightTOPIC = "outdoor/light/sub";
const char* INTOPIC = "Outdoor/light/pub";

const char* mqttUser = "########";
const char* mqttPassword = "########";
const char* broker = "########";

WiFiClient wclient;
PubSubClient client(wclient);

char messages[50];
String msg = "";
int light_sel = 0;
String light_val = "";
int lightPin_num[7] = {33, 32, 13, 12, 21, 19, 18};
int switch_num[7] = {2, 23, 26, 27, 15, 14, 4};
boolean light_num[7] = {false, false, false, false, false, false, false};
boolean light_state[7] = {true, true, true, true, true, true, true};
boolean light_state_old[7] = {true, true, true, true, true, true, true};
const char* LightTOPICs[7] = {
  "outdoor/light/entrance_front",
  "outdoor/light/entrance_back",
  "outdoor/light/agung-i",
  "outdoor/light/outdoor1",
  "outdoor/light/outdoor2",
  "outdoor/light/outdoor3",
  "outdoor/light/outdoor4"
};

void setup_wifi() {
  Serial.print("\nConnecting to ");
  Serial.println(ssid);

  WiFi.begin(ssid, password);
  while (WiFi.status() != WL_CONNECTED) {
    delay(500);
    Serial.print(".");
  }
  Serial.println();
  Serial.println("WiFi connected");
  Serial.print("IP address: ");
  Serial.println(WiFi.localIP());
}

void reconnect() {
  // Loop until we're reconnected
  while (!client.connected()) {
    Serial.print("Attempting MQTT connection...");
    // Attempt to connect
    if (client.connect(ID, mqttUser, mqttPassword)) {
      Serial.println("connected");
      Serial.print("Publishing to: ");
      Serial.println(LightTOPIC);
      Serial.println('\n');
      client.subscribe(INTOPIC);

    } else {
      Serial.print("failed, rc=");
      Serial.print(client.state());
      Serial.println("\n try again in 5 seconds");
      // Wait 5 seconds before retrying
      delay(5000);
    }
  }
}

void callback(char* topic, byte* payload, unsigned int length) {
  Serial.print("Received messages: ");
  Serial.print(INTOPIC);
  msg = "";
  light_sel = 0;
  light_val = "";
  for(int i=0; i<length; i++){
    //Serial.println((char) payload[i]);
    msg += (char)payload[i];
  }
  if (msg == "none") {
    return;
  }
  Serial.print(" ");
  Serial.println(String(msg));
  int msg_index = msg.indexOf('_');
  light_sel = msg.substring(0, msg_index).toInt();
  light_val = msg.substring(msg_index+1, msg.length());
  Serial.println(light_sel);
  Serial.println(light_val);
  boolean light = false;
  if (light_val == "f") {
    light = false;
  } else if (light_val == "t") {
    light = true;
  }
  if (light_num[light_sel] != light) {
    lightControl(light_sel);
  }
  delay(100);
}

void lightControl(int selected) {
  Serial.println("clicked");
  light_num[selected] = !light_num[selected];
  digitalWrite(lightPin_num[selected], light_num[selected]);
  snprintf(messages, 75, "%s", String(light_num[selected]));
  client.publish(LightTOPICs[selected], messages);
}

void setup() {
  // put your setup code here, to run once:
  for(int i = 0; i < 7; i++){
    pinMode(lightPin_num[i], OUTPUT);
    pinMode(switch_num[i], INPUT_PULLUP);
  }
  dacWrite(25, 100);

  Serial.begin(115200);
  setup_wifi(); // Connect to network
  client.setServer(broker, 1883);
  client.setCallback(callback);
}

void loop() {
  // put your main code here, to run repeatedly:
  if (!client.connected()){
    reconnect();
  }
  client.loop();

  for(int i = 0; i < 7; i++) {
    light_state[i] = digitalRead(switch_num[i]);
    if (light_state[i] != light_state_old[i]) {
      lightControl(i);
      light_state_old[i] = light_state[i];
    }
  }
  delay(100);
}
```

lewisxhe, 2024-05-25:
Adding a 10K pull-up resistor to the GPIO can solve the floating problem, and can also be set as an input pull-up, but only with GPIO below GPIO33.
```
pinMode(gpio, INPUT_PULLUP);
```

DAZABAMUKER, 2024-05-25:
Thanks I understood.

Closed 2024-07-10.

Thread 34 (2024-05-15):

T-relay-s3 (H629) 6 relay board simple coding & pin out

Maxheadroom831, 2024-05-15:
Hello,
I am a beginner and had trouble getting the relays to work.
After I realized the six relays were controlled by a SIPO (serial in parallel out) shift register chip 74HC595 chip and not by direct pin allocations of the ESP32-S3 microprocessor . The code was easy to find an example for.

If you look at the schematic for the LilyGo-T-Relay

https://github.com/Xinyuan-LilyGO/LilyGo-T-Relay/blob/main/Schematic/T-Relay6-ESP32S3-Rev1.1.pdf

On the schematic there is circuit called Driver which show a 74HC595 chip  controlling the relays. To control the 74HC595 chip there are 3 control pins.  Latch , Clock and A (data) pin

They are controlled by the esp32-s3 pins as follows:

pin 5 = Latch (latch LOW keeps the 74HC595 from sending out there serial data, High sends the data out).
pin 6 = Clock
pin 7= A (data)

I used a 6 bit binary number to represent each of the 6 relays.
i.e. B000000 = all off, B111111 = all on, B000001 = relay #1 on, B101010 = relays 6/4/2 on.

You could also use a HEX number.

...........Simple CODE........

```
// Define pin connections  from the esp32-s3 to 74HC595 chip.

const int latchPin = 6;
const int clockPin = 5;
const int dataPin = 7;

void setup ()
{
  // Setup pins as Outputs

  pinMode(latchPin, OUTPUT);
  pinMode(clockPin, OUTPUT);
  pinMode(dataPin, OUTPUT);

}

void loop() {

 //turn off all relays

    digitalWrite(latchPin, LOW); // to keep relays from changing while reading serial data

    shiftOut(dataPin, clockPin, MSBFIRST, B000000); // turn all relays off

    digitalWrite(latchPin, HIGH); // send out to serial data to the relays

    delay(1000);

    // Shift out the bits 1 through 6 with left most bit first
    digitalWrite(latchPin, LOW);

    shiftOut(dataPin, clockPin, MSBFIRST, B000001);  // turn on relay #1

    digitalWrite(latchPin, HIGH);

 delay(1000);

 // Shift out the bits 1 through 6
    digitalWrite(latchPin, LOW);

    shiftOut(dataPin, clockPin, MSBFIRST, B000010);  // turn on relay #2

    digitalWrite(latchPin, HIGH);

 delay(1000);

 // Shift out the bits 1 through 6
    digitalWrite(latchPin, LOW);

    shiftOut(dataPin, clockPin, MSBFIRST, B000100);  // turn on relay #3

    digitalWrite(latchPin, HIGH);

 delay(1000);

 // Shift out the bits 1 through 6
    digitalWrite(latchPin, LOW);

    shiftOut(dataPin, clockPin, MSBFIRST, B001000);  // turn on relay #4

    digitalWrite(latchPin, HIGH);

 delay(1000);

 // Shift out the bits 1 through 6
    digitalWrite(latchPin, LOW);

    shiftOut(dataPin, clockPin, MSBFIRST, B010000);  // turn on relay #5

    digitalWrite(latchPin, HIGH);

 delay(1000);

 // Shift out the bits 1 through 6
    digitalWrite(latchPin, LOW);

    shiftOut(dataPin, clockPin, MSBFIRST, B100000);  // turn on relay #6

    digitalWrite(latchPin, HIGH);

 delay(1000);
}

```

Llgok, 2024-07-10:
@Maxheadroom831
You can refer to the following example program to write your code [HT74HC595](https://github.com/Xinyuan-LilyGO/LilyGo-T-Relay/tree/main/examples/T-Relay-ESP32S3/HT74HC595)

Closed 2024-07-10.

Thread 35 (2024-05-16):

Movement and ghost switching

charlesnoble, 2024-05-16:
In our motorhome we have:

- 1 * T-Relay 4 Channel
- 2 * T-Relay S3 (both with an extension board

This bug is hard to describe, but I will do my best here. The two sets of T-Relay S3 relays (each a master and slave unit) are mounted via two of the four holes on the corners of the board.

I'm running all boards via Home Assistant / ESPHome. Here is my code for one of the boards:

```
esphome:
  name: "esp32-behind-freezer"

esp32:
  board: esp32-s3-devkitc-1
  framework:
    type: arduino

# Enable logging
logger:

# Enable Home Assistant API
api:
  encryption:
    key: ##REMOVED##

ota:
  password: ##REMOVED##

wifi:
  ssid: !secret wifi_ssid
  password: !secret wifi_password

  # Enable fallback hotspot (captive portal) in case wifi connection fails
  ap:
    ssid: "Behind-Freezer Fallback Hotspot"
    password: ##REMOVED##

captive_portal:

sn74hc595:
  - id: "sn74hc595_hub"
    data_pin: 7
    clock_pin: 5
    latch_pin: 6
    sr_count: 2

# Individual outputs
switch:
  - platform: gpio
    # SN74HC595 Pin #0
    name: "Behind Freezer Switch 1"
    pin:
      sn74hc595: sn74hc595_hub
      # Use pin number 0
      number: 0
      mode: OUTPUT
      inverted: false
      id: behind_freezer_switch_1

  - platform: gpio
    # SN74HC595 Pin #1
    name: "Behind Freezer Switch 2"
    pin:
      sn74hc595: sn74hc595_hub
      # Use pin number 1
      number: 1
      mode: OUTPUT
      inverted: false
      id: behind_freezer_switch_2

  - platform: gpio
    # SN74HC595 Pin #2
    name: "Behind Freezer Switch 3"
    pin:
      sn74hc595: sn74hc595_hub
      # Use pin number 2
      number: 2
      mode: OUTPUT
      inverted: false
      id: behind_freezer_switch_3

  - platform: gpio
    # SN74HC595 Pin #3
    name: "Behind Freezer Switch 4"
    pin:
      sn74hc595: sn74hc595_hub
      # Use pin number 3
      number: 3
      mode: OUTPUT
      inverted: false
      id: behind_freezer_switch_4

  - platform: gpio
    # SN74HC595 Pin #4
    name: "Behind Freezer Switch 5"
    pin:
      sn74hc595: sn74hc595_hub
      # Use pin number 4
      number: 4
      mode: OUTPUT
      inverted: false
      id: behind_freezer_switch_5

  - platform: gpio
    # SN74HC595 Pin #5
    name: "Behind Freezer Switch 6"
    pin:
      sn74hc595: sn74hc595_hub
      # Use pin number 5
      number: 5
      mode: OUTPUT
      inverted: false
      id: behind_freezer_switch_6

  - platform: gpio
    # SN74HC595 Pin #8 chain: 1
    name: "Behind Freezer Switch 7"
    pin:
      sn74hc595: sn74hc595_hub
      # Use pin number 8
      number: 8
      mode: OUTPUT
      inverted: false
      id: behind_freezer_switch_7

  - platform: gpio
    # SN74HC595 Pin #9 chain: 2
    name: "Behind Freezer Switch 8"
    pin:
      sn74hc595: sn74hc595_hub
      # Use pin number 9
      number: 9
      mode: OUTPUT
      inverted: false
      id: behind_freezer_switch_8

  - platform: gpio
    # SN74HC595 Pin #10 chain: 3
    name: "Behind Freezer Switch 9"
    pin:
      sn74hc595: sn74hc595_hub
      # Use pin number 10
      number: 10
      mode: OUTPUT
      inverted: false
      id: behind_freezer_switch_9

  - platform: gpio
    # SN74HC595 Pin #11 chain: 4
    name: "Behind Freezer Switch 10"
    pin:
      sn74hc595: sn74hc595_hub
      # Use pin number 11
      number: 11
      mode: OUTPUT
      inverted: false
      id: behind_freezer_switch_10

  - platform: gpio
    # SN74HC595 Pin #12 chain: 5
    name: "Behind Freezer Switch 11"
    pin:
      sn74hc595: sn74hc595_hub
      # Use pin number 12
      number: 12
      mode: OUTPUT
      inverted: false
      id: behind_freezer_switch_11

  - platform: gpio
    # SN74HC595 Pin #13 chain: 6
    name: "Behind Freezer Switch 12"
    pin:
      sn74hc595: sn74hc595_hub
      # Use pin number 13
      number: 13
      mode: OUTPUT
      inverted: false
      id: behind_freezer_switch_12
```

Everything was working smoothly until one day, I got up from the seat above which one of the relay board(s) was mounted, and it immediately triggered all relays to turn off. It's super strange, as nothing from the seat touches the board or relays. Now it happens every other time from getting up from the seat.

Here is what the relay board looks like when a relay is normally triggered (putting our stairs up and down):

https://github.com/Xinyuan-LilyGO/LilyGo-T-Relay/assets/972843/2232f1f9-238c-4752-8eee-aac9da434deb

And here is what the relay does when I hope up from the seat directly above it:

https://github.com/Xinyuan-LilyGO/LilyGo-T-Relay/assets/972843/cb347f5c-0d15-4c06-a544-172deec671d4

You'll notice the relay board doesn't move. However, all relays turn off, and a green light labeled 'CH8' switches on. I then switch the stairs back on via Home Assistant. This causes the green light to turn off and the relay to turn on again.

In some cases, other relays on the board switch on with the green LED going on. It's not until I trigger any relay via Home Assistant that things return to normal.

The pattern of the behavior is erratic and hard to measure. It doesn't happen every time I hop up from the seat. This issue also occurs with the other set of T-Relay S3 boards under the bed. However, in this case, it's even harder to capture the occurrence of this issue.

I'm sorry I can't give you too much more information. The ESPhome logs do not mention any issues.

lewisxhe, 2024-05-25:
I don't understand, you mean the relay will activate randomly?

Can you remove the expansion relay cable first and then test it?

charlesnoble, 2024-05-25:
> I don't understand, you mean the relay will activate randomly?

That's correct, my friend. The movement seems to trigger it. You'll see in the second video that the the relay is 'on', and when I hop up from my seat (which is directly above the relay board), the relay turns 'off', and that green 'ch8' light turns on. I can't see any noticeable pressure on the board itself. It's just the general movement of the motorhome when I get up from the seat.

When I open home assistant to check, nothing has changed on home assistant. Home assistant still thinks the relay is 'on'. So, on Home Assistant, I turn the relay 'off' and 'on' again to return things to normal.

 > Can you remove the expansion relay cable first and then test it?

OK, I can test this, but it's hard to replicate this issue as it's not consistent.

lewisxhe, 2024-05-25:
I have been using T-Relay-S3 for three months and have not found any problems with it automatically triggering. However, I placed it on the table. You can try removing the extension cable first and see if it will cause any problems when used alone. this situation

marc-gist, 2024-06-03:
Sounds like a power issue to me. ensure its receiving adequate power supply, no lose connections. check esphome and see if the board is rebooting during this event. if so, you have a power issue, or the board is damaged and a trace on the pcb has come lose/broken.

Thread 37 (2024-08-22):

Can't switch T-Relay status

JpEncausse, 2024-08-22:
Hello,
I bought a T-Relay S3 I try yo make it work, my code seems ok but nothing happened and I don't know how to debug.

My code is inspired from HT74HC595 here is the Setup part:

```
ShiftRegister74HC595_NonTemplate *HT74HC595 = NULL;
void setupRelay()
{
    HT74HC595 = new ShiftRegister74HC595_NonTemplate(8, HT74HC595_DATA, HT74HC595_CLOCK, HT74HC595_LATCH);

    pinMode(HT74HC595_OUT_EN, OUTPUT);
    digitalWrite(HT74HC595_OUT_EN, HIGH); // Close output data HT74HC595

    digitalWrite(HT74HC595_OUT_EN, LOW);
    HT74HC595->setAllLow();
    digitalWrite(HT74HC595_OUT_EN, HIGH);
}
```

and the loop part

```
void loopRelay()
{
    static unsigned long relay_t0 = millis();
    unsigned long t1 = millis();
    int delta = t1 - relay_t0;

    for (int i = 0; i < relayCount; i++) {

        if (relayTime[i] == 0 && relayState[i] == false){ continue; }
        relayTime[i] -= delta;

        if (relayTime[i] > 0){
            if (relayState[i] == false){
                digitalWrite(HT74HC595_OUT_EN, LOW);
                HT74HC595->set(i, HIGH, true);
                digitalWrite(HT74HC595_OUT_EN, HIGH);
                relayState[i] = true;
                Serial.printf("Relay %d: %d\n", i, relayTime[i]);
            }
            continue;
        }

        relayTime[i]  = 0;
        relayState[i] = false;
        digitalWrite(HT74HC595_OUT_EN, LOW);
        HT74HC595->set(i, LOW, true);
        digitalWrite(HT74HC595_OUT_EN, HIGH);
        Serial.printf("Relay %d: OFF\n", i);
    }
    relay_t0 = t1;
}

```
I have a WebSocket that change the relayTime so every x millisecond watch and decide to keep the relay HIGH or LOW.
- The Serial.printf() provide the right information.
- The wire are on COM (Ground) and NO (10V) if I make them touch physically it works. I also try to reverse the wire
So when I put, let say, 2000ms in item 3 it should set relay 3 to HIGH for 2000ms then LOW.

But nothing happened and my code seems OK.
Can you please tell me what I'm missing ?
- May be the order do not go to the relay ?
- Or the 10V do not go between the 2 wires when the relay is HIGH ?

lewisxhe, 2024-08-23:
Please refer to [UnitTestExample](https://github.com/Xinyuan-LilyGO/LilyGo-T-Relay/blob/ac5a099de31cd6af825681d2ca6bdb7cf5708ff8/examples/T-Relay-ESP32S3/UnitTestExample/UnitTestExample.ino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) , HT74HC595_OUT_EN only needs to be set to LOW after power-on. Do not operate this GPIO afterwards.

```
ShiftRegister74HC595_NonTemplate *HT74HC595 = NULL;
void setupRelay()
{
    HT74HC595 = new ShiftRegister74HC595_NonTemplate(8, HT74HC595_DATA, HT74HC595_CLOCK, HT74HC595_LATCH);

    pinMode(HT74HC595_OUT_EN, OUTPUT);
    digitalWrite(HT74HC595_OUT_EN, HIGH); // Close output data HT74HC595

    HT74HC595->setAllLow();
    digitalWrite(HT74HC595_OUT_EN, LOW);

}

void loopRelay()
{
    static unsigned long relay_t0 = millis();
    unsigned long t1 = millis();
    int delta = t1 - relay_t0;

    for (int i = 0; i < relayCount; i++) {

        if (relayTime[i] == 0 && relayState[i] == false){ continue; }
        relayTime[i] -= delta;

        if (relayTime[i] > 0){
            if (relayState[i] == false){
                HT74HC595->set(i, HIGH, true);
                relayState[i] = true;
                Serial.printf("Relay %d: %d\n", i, relayTime[i]);
            }
            continue;
        }

        relayTime[i]  = 0;
        relayState[i] = false;
        HT74HC595->set(i, LOW, true);
        Serial.printf("Relay %d: OFF\n", i);
    }
    relay_t0 = t1;
}

```

JpEncausse, 2024-08-23:
Ohhh thanks it works !
I looked into multiple sample doing this so I was not sure. Many thanks !

Closed 2024-08-23.

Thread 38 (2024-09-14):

Pin Mapping for T-Relay with 4 Relays

JohannesNeu, 2024-09-14:
Hello everyone,

I bought a https://www.lilygo.cc/products/t-relay with 4 Relays and flashed tasmota, which works very well.

Next I would like to attach two to three MAX31865 via SPI and I am therefore looking for the correct PINs.
According to this schematic: https://github.com/Xinyuan-LilyGO/LilyGo-T-Relay/blob/main/Schematic/T_Relay4_ESP32.pdf
(page one upper right corner) The proper PINs on the header would be:

- Header PIN 5 = GPIO PIN 14 [IO14] = CLK
- Header PIN 7 = GPIO PIN 15 [IO15] = MOSI
- Header PIN 6 = GPIO PIN 2 [IO2] = MISO

The schematics describe a "ESP32-WROVER-**B**".
While the ESP on my board is labeled "ESP32-WROVER-**E**"

According to the ESP32-WROVER-E datasheet from Espressif: https://www.espressif.com/sites/default/files/documentation/esp32-wrover-e_esp32-wrover-ie_datasheet_en.pdf (page 5 - 7) the PINs would be different (table 4).

- Header PIN 5 = GPIO PIN 14 [IO14] = HSPICLK = CLK
- Header PIN 15 = GPIO PIN 39 [IO39] = HSPID = MOSI
- Header PIN 9 = GPIO PIN 12 [IO12] = HSPIQ = MISO

The IO15, which is used as MOSI in the lilygo schematics is the HSPICS0 chip select according to the Espressif documentation and IO2 is HSPIWP according to it.

I would appreciate your help to figure out which configuration is correct and if both are feasible an explanation where this difference comes from.

kind regards,
Johannes

lewisxhe, 2024-09-18:
No, you just need to specify which GPIO to use
```
int sck = Less than GPIO 33;
int miso = any_pin;
int mosi = Less than GPIO 33;
SPI.begin(sck,miso,mosi);

```

JohannesNeu, 2024-09-23:
Thank you for the reply, but what you are describing is software SPI, right?
I tried it with tasmota and if I want to use SSPI it works with every pin.
But what if i want to use hardware SPI ?

lewisxhe, 2024-09-24:
This is hardware SPI

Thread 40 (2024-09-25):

Not able to get relays working

cremer42, 2024-09-25:
Hello, I purchased this board due to many reasons. This is supposed to replace a generic 4 channel ESP device I already have built/programmed.

I have put what I would consider a basic ESPhome program on it and I am not able to get relays to pull in. Am I missing something? Any help would be appreciated.

Below is my current code:

cremer42, 2024-09-25:
```
substitutions:
  name: "pool-control-v2"
  friendly_name: Pool Controller v.2.0
  relay_1_name: Switch 1
  relay_2_name: Switch 2
  relay_3_name: Switch 3
  relay_4_name: Switch 4
  relay_5_name: Switch 5
  relay_6_name: Switch 6
  dallas_1: Pre Heater Temp
  dallas_2: Post Heater Temp
  dallas_3: Panel Temperature

esphome:
  name: ${name}
  friendly_name: ${friendly_name}
  comment: Lilygo T-Relay S3

esp32:
  board: esp32-s3-devkitc-1
  framework:
    type: arduino

# Enable logging
logger:

# Enable Home Assistant API
api:
  encryption:
    key: !secret pool_controller_api_key

ota:
  platform: esphome
  password: !secret pool_controller_ota_pw

wifi:
  ssid: !secret wifi_ssid
  password: !secret wifi_password

  # Enable fallback hotspot (captive portal) in case wifi connection fails
  ap:
    ssid: ${friendly_name}
    password: !secret wifi_password

web_server:
  port: 80

sn74hc595:
  - id: "relay_hub"
    data_pin: 7
    clock_pin: 5
    latch_pin: 6
    sr_count: 2

# Individual outputs
switch:
  - platform: gpio
    # SN74HC595 Pin #0
    name: ${relay_1_name}
    pin:
      sn74hc595: relay_hub
      number: 0  # Use pin number 0
      inverted: false
      id: relay_1

  - platform: gpio
    # SN74HC595 Pin #1
    name: ${relay_2_name}
    pin:
      sn74hc595: relay_hub
      number: 1  # Use pin number 1
      inverted: false
      id: relay_2

  - platform: gpio
    # SN74HC595 Pin #2
    name: ${relay_3_name}
    pin:
      sn74hc595: relay_hub
      number: 2  # Use pin number 2
      inverted: false
      id: relay_3

  - platform: gpio
    # SN74HC595 Pin #3
    name: ${relay_4_name}
    pin:
      sn74hc595: relay_hub
      number: 3  # Use pin number 3
      inverted: false
      id: relay_4

  - platform: gpio
    # SN74HC595 Pin #4
    name: ${relay_5_name}
    pin:
      sn74hc595: relay_hub
      number: 4  # Use pin number 4
      inverted: false
      id: relay_5

  - platform: gpio
    # SN74HC595 Pin #5
    name: ${relay_6_name}
    pin:
      sn74hc595: relay_hub
      number: 5        # Use pin number 5
      inverted: false
      id: relay_6

captive_portal:
```

jasonmhite, 2024-10-01:
For anybody coming across this and wondering why ESPHome is struggling with this device, @cremer42 's solution is correct, you need to pull up the enable pin on the shift register, which is tied to GPIO4. This is not mentioned anywhere in the docs [page](https://github.com/Xinyuan-LilyGO/LilyGo-T-Relay/blob/main/docs/RELAY_ESP32S3.MD) for this board. @LilyGO or @lewisxhe should probably mention this in the docs.

A slightly improved version of @cremer42 's solution that gets the polarity of the enable pin right and sets it to an internal switch so that it doesn't show up in Home Assistant:

```yaml
switch:
  - platform: gpio
    pin:
      number: GPIO4
      inverted: True
    name: "SN74HC595 Enable"
    internal: True
    id: ch_en_pin
    restore_mode: ALWAYS_ON
```

cremer42, 2024-10-02:
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

You are correct. I wanted mine to show up in HA in my circumstance. Mostly for troubleshooting. This was actually a benefit for me. Since I've automated my pool using this board, I have an automation that locks out my equipment. My automation can now just trigger GPI04 and turn all the relays off.

But yes, if this was better documented, it would've made my life a lot easier.

lewisxhe, 2024-10-04:
Hi @cremer42

I have set the initial voltage of HC595 4 Pin to LOW in yaml, so it should work normally?
https://github.com/Xinyuan-LilyGO/LilyGo-T-Relay/blob/fd145e8e2d1f830eabd84213349a2f8e72d09321/ESPHome/T-Relay-ESP32S3.yaml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

Closed 2024-09-25.

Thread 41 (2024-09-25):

I2C and DS18B20 Pin Definition

cremer42, 2024-09-25:
I've looked and looked at the schematics page.... Does someone have a better pin breakdown of what the GPIO's are they relate to?

I am trying to setup a one_wire bus and a i2c bus using ESPhome.

I plant to solder wires to the DS18B20 location on the board, so knowing the built in pin would be beneficial. I was also considering using the Qwiic / Stemma connector for my I2C bus, so knowing what Pins that uses would be greatly appreciated as well.

Thank you,!

lewisxhe, 2024-09-26:
Do you mean T-Relay-S3? If yes, look here

https://github.com/Xinyuan-LilyGO/LilyGo-T-Relay/blob/fd145e8e2d1f830eabd84213349a2f8e72d09321/examples/T-Relay-ESP32S3/DS18x20_Temperature/DS18x20_Temperature.ino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

cremer42, 2024-09-26:
Ok... Thank you. What about the I2C? Is it defined? Specifically the Qwiic connector? If not, can it be changed to say, GPIO 16 and 17?

lewisxhe, 2024-09-27:
DS18B20 PCB reserves a 4.7k resistor position, close to DS18B20
You should check if the delay is caused by the network delay, not the relay driver delay.

cremer42, 2024-09-27:
Sorry for the inexperienced reply. But how do I check both of those?

Thanks

cremer42, 2024-09-27:
Thanks. I'll see if I can figure out how to do that into esphome.

cremer42, 2024-09-28:
I have no clue how to "write" this driver relay.... All I know is when I insruct a relay to turn on/off, i have a 10-18 second delay. Any help you can provide would be appreciated.

cremer42, 2024-09-28:
Unsure if this could be causing issues....

[23:27:17][E][PCF8563:025]: Communication with PCF8563 failed!
[23:27:17][E][component:082]:   Component pcf8563.time is marked FAILED

lewisxhe, 2024-10-01:
https://github.com/Xinyuan-LilyGO/LilyGo-T-Relay/blob/main/firmware%2FLilyGo-T-Relay-S3%2Ffirmware_LilyGo-Relay-UnitTest_20240409.bin

Try this factory test, using io0 to switch the relay.

cremer42, 2024-10-04:
Maybe I am a little fresh when it comes to these things... I installed the BIN, but how do I connect to it to switch on io0?

lewisxhe, 2024-10-04:
Just uploaded a firmware for relay testing, you can use this to test
https://github.com/Xinyuan-LilyGO/LilyGo-T-Relay/blob/main/firmware/LilyGo-T-Relay-S3/firmware_relay_test_241004.bin

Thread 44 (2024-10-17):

S3relay ESPHome - Output ch_en_pin error

dew1989, 2024-10-17:
It seems that ESPHome will not compile with your posted code due to this section
```
output:
  - id: ch_en_pin
    pin: 4  # enable 74ch595
    initial_state: low
```

ESPHome requires a "platform" to be set. Please advise on the correct code

lewisxhe, 2024-10-17:
Try this

```
esphome:
  name: lilygo-relays3
  build_path: .esphome/build/lilygo-relays3

esp32:
  board: esp32-s3-devkitc-1
  framework:
    type: arduino

sn74hc595:
  - id: "sn74hc595_hub"
    data_pin: 7
    clock_pin: 5
    latch_pin: 6
    sr_count: 1

output:
  - platform: gpio
    id: ch_en_pin
    pin: 4

# Individual outputs
switch:
  - platform: gpio
    name: "Switch 1"
    pin:
      sn74hc595: sn74hc595_hub
      number: 0
      inverted: false
      id: relay1

  - platform: gpio
    name: "Switch 2"
    pin:
      sn74hc595: sn74hc595_hub
      number: 1
      inverted: false
      id: relay2

  - platform: gpio
    name: "Switch 3"
    pin:
      sn74hc595: sn74hc595_hub
      number: 2
      inverted: false
      id: relay3

  - platform: gpio
    name: "Switch 4"
    pin:
      sn74hc595: sn74hc595_hub
      number: 3
      inverted: false
      id: relay4

  - platform: gpio
    name: "Switch 5"
    pin:
      sn74hc595: sn74hc595_hub
      number: 4
      inverted: false
      id: relay5

  - platform: gpio
    name: "Switch 6"
    pin:
      sn74hc595: sn74hc595_hub
      number: 5
      inverted: false
      id: relay6
mqtt:
  broker: Your MQTT server
  # username: Your MQTT Username
  # password:  Your MQTT Password
  port: Your MQTT port

logger:
  level: DEBUG
  baud_rate: 115200
  logs:
    mqtt.component: DEBUG
    mqtt.client: ERROR

api:
  encryption:
    key: "E4AvftHULay+f6wwnKgHzsu7q7nzUdcrHp/Mjhyyjvk="

ota:
  password: "0204c885b8f04777ae94a8e51b4619c5"

wifi:
  ssid: "Your WiFi ssid"
  password: "Your WiFi password"

  ap:
    ssid: "Relay Fallback Hotspot"
    password: "fltzKdbsbDEn"

captive_portal:

```

lewisxhe, 2024-10-18:
Sorry, I found a mistake, I have updated esphome, please retest https://github.com/Xinyuan-LilyGO/LilyGo-T-Relay/blob/main/ESPHome/T-Relay-ESP32S3.yaml

Closed 2024-10-18.

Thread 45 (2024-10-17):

relay S3 no wifi and strange behaviar

bkbartk, 2024-10-17:
Hello,

I just  got my Lilygo T-RelayS3, but I can't get it to work as expected.
I flashed esphome on it using the config below
wifi settings are in my `.base.yaml`
I connected the external antenna,
-still my device does not connect to wifi.
-no AP is created for fall back
-on boot, random switches are enabled, no clue way.
-when I try to get anything out of the serial logger the serial adapter keeps disconnecting which makes logging impossible.
So actually I don't get anything to work.

I power my device using usb-c, but powering is from my PC or using an RPI-4 adapter doesn't matter, the behaviar is the same.

I must be missing something but can't figure what it is.
```
esphome:
  name: lilygotest
  friendly_name: lilygotest

esp32:
  board: esp32-s3-devkitc-1
  framework:
    type: esp-idf

packages:
  base: !include .base.yaml

sn74hc595:
  - id: "sn74hc595_hub"
    data_pin: 7
    clock_pin: 5
    latch_pin: 6
    sr_count: 1

# output:
#   - id: ch_en_pin
#     pin: 4  # enable 74ch595
#     initial_state: low

# Individual outputs
switch:
  - platform: gpio
    # SN74HC595 Pin #0
    name: "Switch 1"
    restore_mode: RESTORE_DEFAULT_OFF
    pin:
      sn74hc595: sn74hc595_hub
      # Use pin number 0
      number: 0
      inverted: false
      id: relay1
      mode: output

  - platform: gpio
    # SN74HC595 Pin #1
    name: "Switch 2"
    restore_mode: RESTORE_DEFAULT_OFF
    pin:
      sn74hc595: sn74hc595_hub
      # Use pin number 1
      number: 1
      inverted: false
      id: relay2
      mode: output

  - platform: gpio
    # SN74HC595 Pin #2
    name: "Switch 3"
    restore_mode: RESTORE_DEFAULT_OFF
    pin:
      sn74hc595: sn74hc595_hub
      # Use pin number 2
      number: 2
      inverted: false
      id: relay3
      mode: output

  - platform: gpio
    # SN74HC595 Pin #3
    name: "Switch 4"
    restore_mode: RESTORE_DEFAULT_OFF
    pin:
      sn74hc595: sn74hc595_hub
      # Use pin number 3
      number: 3
      inverted: false
      id: relay4
      mode: output

  - platform: gpio
    # SN74HC595 Pin #4
    name: "Switch 5"
    restore_mode: RESTORE_DEFAULT_OFF
    pin:
      sn74hc595: sn74hc595_hub
      # Use pin number 4
      number: 4
      inverted: false
      id: relay5
      mode: output

  - platform: gpio
    # SN74HC595 Pin #5
    name: "Switch 6"
    restore_mode: RESTORE_DEFAULT_OFF
    pin:
      sn74hc595: sn74hc595_hub
      # Use pin number 5
      number: 5
      inverted: false
      id: relay6
      mode: output

```

lewisxhe, 2024-10-18:
Sorry, I found a mistake, I have updated esphome, please retest https://github.com/Xinyuan-LilyGO/LilyGo-T-Relay/blob/main/ESPHome/T-Relay-ESP32S3.yaml

bkbartk, 2024-10-18:
I applied the changes for `GPIO4` but it doesn't help.
this serial addapter keeps diconnecting `USB JTAG/Serial debug urit(COM3) - paired`
so the log only says
```
[22:53:42]ESP-ROM:esp32s3-20210327
Terminal disconnected: NetworkError: The device has been lost.
```
the only way the keep the com port steady is to hold the boot button. but then I don't get logs either.
I also set the restore mode to always_On, but that doesn't change anything, It's just like my flash doesn't stick to the device.

bkbartk, 2024-10-18:
some comment, it seems to work when I use framework: arduino,
but all fails when using framework: esp-idf.
is there no support for this? and if not will there ever be?

lewisxhe, 2024-10-21:
Are you using esphome? Does it keep disconnecting? What method did you use to write to it?

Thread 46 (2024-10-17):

Relay S3 - main board not working but chained board works

dew1989, 2024-10-17:
I just got a S3 relay and one daisy chained board. I flashed via ESPHome, I have full working control over the daisy chained board, but cannot get the relays to turn on or off on the main board. Wifi connects, and I have no trouble reflashing, but cannot control the main board. Do I have a faulty board?

I think my code is good, but here it is regardless:
```
esphome:
  name: lilygo-relay
  friendly_name: relay
  build_path: .esphome/build/lilygo-relays3

esp32:
  board: esp32-s3-devkitc-1
  framework:
    type: Arduino

# Enable logging
logger:
  baud_rate: 115200

# Enable Home Assistant API
api:

ota:
  platform: esphome

wifi:
  ssid: ###
  password: ###

  # Enable fallback hotspot (captive portal) in case wifi connection fails
  # SSID is device name. No password
  ap: {}

captive_portal:

output:
  - platform: gpio
    id: ch_en_pin
    pin: 4
    inverted: true

sn74hc595:
  - id: "sn74hc595_hub"
    data_pin: 7
    clock_pin: 5
    latch_pin: 6
    sr_count: 2

# Individual outputs
switch:
  - platform: gpio
    # SN74HC595 Pin #0
    name: "Switch 1"
    pin:
      sn74hc595: sn74hc595_hub
      # Use pin number 0
      number: 0
      inverted: false
      id: relay1

  - platform: gpio
    # SN74HC595 Pin #1
    name: "Switch 2"
    pin:
      sn74hc595: sn74hc595_hub
      # Use pin number 1
      number: 1
      inverted: false
      mode: OUTPUT
      id: relay2

  - platform: gpio
    # SN74HC595 Pin #2
    name: "Switch 3"
    pin:
      sn74hc595: sn74hc595_hub
      # Use pin number 2
      number: 2
      inverted: false
      mode: OUTPUT
      id: relay3

  - platform: gpio
    # SN74HC595 Pin #3
    name: "Switch 4"
    pin:
      sn74hc595: sn74hc595_hub
      # Use pin number 3
      number: 3
      inverted: false
      mode: OUTPUT
      id: relay4

  - platform: gpio
    # SN74HC595 Pin #4
    name: "Switch 5"
    pin:
      sn74hc595: sn74hc595_hub
      # Use pin number 4
      number: 4
      inverted: false
      mode: OUTPUT
      id: relay5

  - platform: gpio
    # SN74HC595 Pin #5
    name: "Switch 6"
    pin:
      sn74hc595: sn74hc595_hub
      # Use pin number 5
      number: 5
      inverted: false
      mode: OUTPUT
      id: relay6

  - platform: gpio
    # SN74HC595 Pin #8 chain: 1
    name: "Switch Chain_1"
    pin:
      sn74hc595: sn74hc595_hub
      # Use pin number 8
      number: 8
      inverted: false
      mode: OUTPUT
      id: relay1_chain

  - platform: gpio
    # SN74HC595 Pin #9 chain: 2
    name: "Switch Chain_2"
    pin:
      sn74hc595: sn74hc595_hub
      # Use pin number 9
      number: 9
      inverted: false
      mode: OUTPUT
      id: relay2_chain

  - platform: gpio
    # SN74HC595 Pin #10 chain: 3
    name: "Switch Chain_3"
    pin:
      sn74hc595: sn74hc595_hub
      # Use pin number 10
      number: 10
      inverted: false
      mode: OUTPUT
      id: relay3_chain

  - platform: gpio
    # SN74HC595 Pin #11 chain: 4
    name: "Switch Chain_4"
    pin:
      sn74hc595: sn74hc595_hub
      # Use pin number 11
      number: 11
      inverted: false
      mode: OUTPUT
      id: relay4_chain

  - platform: gpio
    # SN74HC595 Pin #12 chain: 5
    name: "Switch Chain_5"
    pin:
      sn74hc595: sn74hc595_hub
      # Use pin number 12
      number: 12
      inverted: false
      mode: OUTPUT
      id: relay5_chain

  - platform: gpio
    # SN74HC595 Pin #13 chain: 6
    name: "Switch Chain_6"
    pin:
      sn74hc595: sn74hc595_hub
      # Use pin number 13
      number: 13
      inverted: false
      mode: OUTPUT
      id: relay6_chain

```

lewisxhe, 2024-10-18:
Sorry, I found a mistake, I have updated esphome, please retest https://github.com/Xinyuan-LilyGO/LilyGo-T-Relay/blob/main/ESPHome/T-Relay-ESP32S3.yaml

dew1989, 2024-10-18:
This fixed it. Thank you!

Closed 2024-10-18.

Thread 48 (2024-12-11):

Replace esp module?

drosner, 2024-12-11:
Not sure if this can be answered but i have 2 boards that i fried the esp module and want to replace. I tried using an air station like i would a normal IC chip but it wouldn't budge. Anyone have any suggestions or familiar with how these are manufactured that can give me some pointers to remove the esp module from the PCB board?

lewisxhe, 2024-12-13:
You need a heat gun, the temperature needs to be adjusted to about 330°, and then it must be heated for several minutes before it can be completely disassembled.

drosner, 2024-12-13:
Thank you sir! I'm using a hot air rework station and have been using 400C. Heating from top and bottom for 20 mins! Thing won't budge....

lewisxhe, 2024-12-13:
You can add some solder oil to assist heating, or you can add some low-temperature solder paste to neutralize the lead-free solder on the PCB.
Also, the air outlet of the hot air gun should cover the entire ESP32 as much as possible.

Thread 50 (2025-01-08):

T-Relay 8 channel doesn't work with W5500 Shield attached

bartoszkaminski, 2025-01-08:
Hello!

I purchased LilyGo T-Relay 8ch and I wanted to use it with T-Relay W5500 shield to have Ethernet. I soldered all pins of the shield but now my relay board doesn’t start at all. When I supply 12V  to the relay board there’s no reaction, it doesn’t go online. Ethernet port doesn’t blink when cable is attached.

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

Can you help me figure out what is wrong? Before soldering the shield I had ESPHome installed on the relay board and it worked perfectly.

Llgok, 2025-01-09:
@bartoszkaminski
Hello, thank you for your report. I noticed that you seem to have soldered the W5500 module to the bottom of the board. Doing so will cause both boards to short circuit. The correct approach is to solder the W5500 to the top of the main board, as shown in the following image.
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

bartoszkaminski, 2025-01-09:
I was assuming that two square pins must be connected together.

Can you confirm that my understanding of pins orientation is correct now?

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

BTW, do you think I fried the board? If it works after correctly connecting the shield then I'm good or will its lifespan be limited due to the fact that I shorted it?

Llgok, 2025-01-09:
@bartoszkaminski
Yes, the connection method you are demonstrating now is correct. Could you try this method to see if the device can function properly? Previously, reversing the power supply might have caused a short circuit on the board.
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

Misiu, 2025-04-01:
@Llgok please consider adding a picture to the product description page showing the correct placement of the W5500 Shield (both to the W5500 shield and to the T-Relay board pages.
It would be super helpful for less technical users like myself.

Llgok, 2025-04-02:
@Misiu
It has been updated to the [FAQ](https://github.com/Xinyuan-LilyGO/LilyGo-T-Relay?tab=readme-ov-file#faq).

Misiu, 2025-04-02:
Thank you 😊

Llgok, 2025-06-23:
The issue was closed due to no response for a long time. If you still have questions, please reopen it.

Closed 2025-06-23.

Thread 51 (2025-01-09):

T-Relay Chain problems

carbuthn, 2025-01-09:
1. I could not find a schematic for the T-Relay Chain board.
2. All of the pictures show the cable that connect the T-Relay S3 motherboard to the T-Relay Chain connected to the left side of the T-Relay Chain board, this is labeled as an output on the board. I was able to get the board to work once I moved the cable to the input (right) side of the board.
3. Would like to know the pin to turn off the red LED on the T-Relay Chain board.

lewisxhe, 2025-01-10:
The red LED cannot be turned off, it is the power indicator

carbuthn, 2025-01-11:
I was afraid of that, I didn't have one on the main board, only the chain board. Time for some black paint.

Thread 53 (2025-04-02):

esp32_8relays module max current

qvlogan88, 2025-04-02:
hi all,

I would like to protect my circuit with a fuse, but I couldn't find the maximum current that flows through the board in the docs
someone knows it? thanks in advance and forgive for bad english!

qvlogan88, 2025-04-02:
nono, I'm talking about the maximum current that the card can handle before burning out

lewisxhe, 2025-04-02:
Are you referring to the board's power output? As far as I know, this board only has 3.3V pins exposed, right?

lewisxhe, 2025-04-02:
Input current of the board? Are you talking about the current limit for powering the board? There is no input current limit. It is recommended to use DC power supply. Only about 10W of current is needed to work well.

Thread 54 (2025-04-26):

Lily go ESP32-S3 T6 relay

tirty7th, 2025-04-26:
Hi. I’m new to programming and don’t have much experience, but I am having a difficult time programming the dev board for t6 relay. Do I need the usb adapter to program it properly? I have tried the most basic code to toggle on the relays but none of the pin outs numbers work. I was able to toggle on all 6 relays with a random AI generated code, but it was inconsistent and activated random relays. There is very little information available on this dev board so I am asking for help. The GitHub pages seem to be out of date and geared towards only the esp dev boards, not the esp32-S3 ones. Any assistance is greatly appreciated.

lewisxhe, 2025-04-26:
This is a register controlled using a shift register, not relays controlled individually using GPOP, have you looked at the examples here?
https://github.com/Xinyuan-LilyGO/LilyGo-T-Relay/tree/main/examples/T-Relay-ESP32S3

What code did you use for testing?

tirty7th, 2025-04-26:
Does this mean that it requires an additional board to program? I’m fairly
new to programming and so I assumed that it would use GPIO to control the
relays.

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

lewisxhe, 2025-04-26:
This is the most basic example of controlling a relay https://github.com/Xinyuan-LilyGO/LilyGo-T-Relay/blob/main/examples/T-Relay-ESP32S3/HT74HC595/HT74HC595.ino

No additional programmer is required, please see README, all documents are up to date.

tirty7th, 2025-04-26:
I receive this error: Compilation error:
ShiftRegister74HC595_NonTemplate.h: No such file or directory

Is there a URL I need to add to the board manager? What step am I missing?

thanks.

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

lewisxhe, 2025-04-26:
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

tirty7th, 2025-04-26:
I'm on a macbook. I copied the lib files to the library folder. I now get
this error:

Compilation error: pin_config.h: No such file or directory

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

lewisxhe, 2025-04-26:
Isn't pinconfig.h here?

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

lewisxhe, 2025-04-26:
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

Just copy the pin definition to the sketch. Your question is really elementary. 😂😂😂

tirty7th, 2025-04-26:
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

lewisxhe, 2025-04-26:
I just deleted it and put it on the sketch.

tirty7th, 2025-04-26:
I mentioned that I am very inexperienced at programming. However, what is
elementary to you is not to others. The code that you referenced in your
picture is missing.

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

lewisxhe, 2025-04-26:
That's okay. Just do the best I can.

tirty7th, 2025-04-26:
I am confused then. If it is on the sketch then why is it saying that the
directory does not exist?

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

lewisxhe, 2025-04-26:
Please show me a screenshot of your ide

tirty7th, 2025-04-26:
I don't understand what you mean.

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

lewisxhe, 2025-04-26:
Send me a screenshot of the error interface and your sketch directory folder.

tirty7th, 2025-04-26:
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

lewisxhe, 2025-04-26:
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
Apparently your Arduino IDE doesn't open pinconfig.h, can you check if they are in the same directory?

tirty7th, 2025-04-26:
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

How would the pin_config.h file be present? It is not on GitHub

tirty7th, 2025-04-26:
If you have the file pin_config.h available, that would be helpful.

lewisxhe, 2025-04-26:
No need... I have updated the sketch... Just download this file again.

https://github.com/Xinyuan-LilyGO/LilyGo-T-Relay/blob/main/examples/T-Relay-ESP32S3/HT74HC595/HT74HC595.ino

tirty7th, 2025-04-26:
Thank you very much for your assistance. The code is working now.

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

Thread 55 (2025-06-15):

T-Relay S3 unresponsive when connected to T-Relay Chain

R0X, 2025-06-15:
Hi there,

i am having problems with the T-Relay S3 when i connect one T-Relay Chain to it.
I setup the relays to switch on for 400ms and then turn off again. When i connect the T-Relay Chain they sometimes just switch on only a few ms. Furthermore sometimes random relays are activated. I am using adjustable 12v 24 Watt power supply. Rising the Voltage to 15v didn't make a difference.

In this [Video](https://youtube.com/shorts/UzArPEQac_0?feature=share) i triggered the cee2_switch switch on action

```
    turn_on_action:
      - switch.turn_on: relay2
      - delay: 400ms
      - switch.turn_off: relay2
 ```

three times, only the last one succeeded. In attemp 1 and 2 you can hear the relay click very shortly but no led indication.

The following esphome config is used:

```

esphome:
  name: $devicename
  comment: ${device_description}

esp32:
  board: esp32-s3-devkitc-1
  framework:
    type: arduino

logger:

api:
  password: !secret api_password

ota:
  - platform: esphome
    password: !secret ota_password

wifi:
  ssid: !secret wifi_name
  password: !secret wifi_password

  manual_ip:
    static_ip: ${device_ip}
    gateway: 172.16.49.254
    subnet: 255.255.255.0
    dns1: 172.16.40.5
    dns2: 172.16.47.15

  ap:
    ssid: "${devicename} Fallback Hotspot"
    password: !secret wifi_fallback_password

time:
  - platform: homeassistant
    id: homeassistant_time

web_server:
  port: 80
  auth:
    username: admin
    password: !secret web_server_password

text_sensor:
  - platform: version
    name: "Version"
    icon: mdi:cube-outline

sn74hc595:
  - id: "sn74hc595_hub"
    data_pin: 7
    clock_pin: 5
    latch_pin: 6
    sr_count: 2

binary_sensor:
  - platform: status
    name: "Status"
    device_class: connectivity

  - platform: gpio
    id: input1
    internal: true
    pin:
      number: GPIO13
      mode: INPUT_PULLUP
      inverted: false
  - platform: gpio
    id: input2
    internal: true
    pin:
      number: GPIO21
      mode: INPUT_PULLUP
      inverted: false
  - platform: gpio
    id: input3
    internal: true
    pin:
      number: GPIO47
      mode: INPUT_PULLUP
      inverted: false
  - platform: gpio
    id: input4
    internal: true
    pin:
      number: GPIO38
      mode: INPUT_PULLUP
      inverted: false
  - platform: gpio
    id: input5
    internal: true
    pin:
      number: GPIO48
      mode: INPUT_PULLUP
      inverted: false
  - platform: gpio
    id: input6
    internal: true
    pin:
      number: GPIO45
      mode: INPUT_PULLUP
      inverted: false

sensor:
  - platform: wifi_signal
    name: "Wifi Signal"
    update_interval: 60s
    icon: mdi:wifi

  - platform: uptime
    name: "Uptime"
    update_interval: 60s
    icon: mdi:clock-outline

switch:
  - platform: gpio
    id: ch_en
    pin:
      number: GPIO4
      inverted: true
    restore_mode: ALWAYS_ON

  - platform: gpio
    # SN74HC595 Pin #0
    name: "Switch 1"
    id: relay1
    internal: true
    pin:
      sn74hc595: sn74hc595_hub
      # Use pin number 0
      number: 0
      inverted: false
      mode: OUTPUT

  - platform: gpio
    # SN74HC595 Pin #1
    name: "Switch 2"
    id: relay2
    internal: true
    pin:
      sn74hc595: sn74hc595_hub
      # Use pin number 1
      number: 1
      inverted: false
      mode: OUTPUT

  - platform: gpio
    # SN74HC595 Pin #2
    name: "Switch 3"
    id: relay3
    internal: true
    pin:
      sn74hc595: sn74hc595_hub
      # Use pin number 2
      number: 2
      inverted: false
      mode: OUTPUT

  - platform: gpio
    # SN74HC595 Pin #3
    name: "Switch 4"
    id: relay4
    internal: true
    pin:
      sn74hc595: sn74hc595_hub
      # Use pin number 3
      number: 3
      inverted: false
      mode: OUTPUT

  - platform: gpio
    # SN74HC595 Pin #4
    name: "Switch 5"
    id: relay5
    internal: true
    pin:
      sn74hc595: sn74hc595_hub
      # Use pin number 4
      number: 4
      inverted: false
      mode: OUTPUT

  - platform: gpio
    # SN74HC595 Pin #5
    name: "Switch 6"
    id: relay6
    internal: true
    pin:
      sn74hc595: sn74hc595_hub
      # Use pin number 5
      number: 5
      inverted: false
      mode: OUTPUT

  - platform: gpio
    # SN74HC595 Pin #8 chain: 1
    name: "Switch Chain_1"
    id: relay1_chain
    internal: true
    pin:
      sn74hc595: sn74hc595_hub
      # Use pin number 8
      number: 8
      inverted: false
      mode: OUTPUT

  - platform: gpio
    # SN74HC595 Pin #9 chain: 2
    name: "Switch Chain_2"
    id: relay2_chain
    internal: true
    pin:
      sn74hc595: sn74hc595_hub
      # Use pin number 9
      number: 9
      inverted: false
      mode: OUTPUT

  - platform: gpio
    # SN74HC595 Pin #10 chain: 3
    name: "Switch Chain_3"
    id: relay3_chain
    internal: true
    pin:
      sn74hc595: sn74hc595_hub
      # Use pin number 10
      number: 10
      inverted: false
      mode: OUTPUT

  - platform: gpio
    # SN74HC595 Pin #11 chain: 4
    name: "Switch Chain_4"
    id: relay4_chain
    internal: true
    pin:
      sn74hc595: sn74hc595_hub
      # Use pin number 11
      number: 11
      inverted: false
      mode: OUTPUT

  - platform: gpio
    # SN74HC595 Pin #12 chain: 5
    name: "Switch Chain_5"
    id: relay5_chain
    internal: true
    pin:
      sn74hc595: sn74hc595_hub
      # Use pin number 12
      number: 12
      inverted: false
      mode: OUTPUT

  - platform: gpio
    # SN74HC595 Pin #13 chain: 6
    name: "Switch Chain_6"
    id: relay6_chain
    internal: true
    pin:
      sn74hc595: sn74hc595_hub
      # Use pin number 13
      number: 13
      inverted: false
      mode: OUTPUT

  - platform: template
    name: "CEE1"
    id: cee1_switch
    lambda: |-
      return id(input1).state;
    turn_on_action:
      - switch.turn_on: relay1
      - delay: 400ms
      - switch.turn_off: relay1
    turn_off_action:
      - switch.turn_on: relay1_chain
      - delay: 400ms
      - switch.turn_off: relay1_chain
    optimistic: false

  - platform: template
    name: "CEE2"
    id: cee2_switch
    lambda: |-
      return id(input2).state;
    turn_on_action:
      - switch.turn_on: relay2
      - delay: 400ms
      - switch.turn_off: relay2
    turn_off_action:
      - switch.turn_on: relay2_chain
      - delay: 400ms
      - switch.turn_off: relay2_chain
    optimistic: false

  - platform: template
    name: "CEE3"
    id: cee3_switch
    lambda: |-
      return id(input3).state;
    turn_on_action:
      - switch.turn_on: relay3
      - delay: 400ms
      - switch.turn_off: relay3
    turn_off_action:
      - switch.turn_on: relay3_chain
      - delay: 400ms
      - switch.turn_off: relay3_chain
    optimistic: false

  - platform: template
    name: "CEE4"
    id: cee4_switch
    lambda: |-
      return id(input4).state;
    turn_on_action:
      - switch.turn_on: relay4
      - delay: 400ms
      - switch.turn_off: relay4
    turn_off_action:
      - switch.turn_on: relay4_chain
      - delay: 400ms
      - switch.turn_off: relay4_chain
    optimistic: false

  - platform: template
    name: "CEE5"
    id: cee5_switch
    lambda: |-
      return id(input5).state;
    turn_on_action:
      - switch.turn_on: relay5
      - delay: 400ms
      - switch.turn_off: relay5
    turn_off_action:
      - switch.turn_on: relay5_chain
      - delay: 400ms
      - switch.turn_off: relay5_chain
    optimistic: false

  - platform: template
    name: "CEE6"
    id: cee6_switch
    lambda: |-
      return id(input6).state;
    turn_on_action:
      - switch.turn_on: relay6
      - delay: 400ms
      - switch.turn_off: relay6
    turn_off_action:
      - switch.turn_on: relay6_chain
      - delay: 400ms
      - switch.turn_off: relay6_chain
    optimistic: false
```

R0X, 2025-06-17:
i used the config from you but still same error
[see this Video](https://youtube.com/shorts/FPoKLlbd9nU)

first three attempt you hear the relay click but too short and the led also doesnt stay on.
only fourth attempt led stays on

when i unplug the chain it works normaly.

lewisxhe, 2025-06-18:
There is no problem with the yaml file, and the single test is OK. It seems to be a network delay problem. Connect the USB and check the control output of the serial monitor. After clicking the switch, the serial console should immediately output the controlled relay number.

lewisxhe, 2025-06-21:
Two test methods,
1. Write the relay driver test to see if it is normally closed https://github.com/Xinyuan-LilyGO/LilyGo-T-Relay/blob/main/examples/T-Relay-ESP32S3/HT74HC595/HT74HC595.ino

2. You said that the mainboard is abnormal when connected to 220V, so you can take the board outside the distribution box for testing first

From my personal opinion, it seems that the strong current causes the wifi signal to be abnormal. Have you checked the serial output message according to the method I mentioned above?

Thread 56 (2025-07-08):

Library and EthernetServer server issue

Deoyjadzo, 2025-07-08:
Hello everyone. I am trying to use the Lilygo board 4 relay with the w5500 shield and I am facing some dificulties. My guess it is a library issue, but please feel free to correct me if not.

I am using arduino IDE 2.0.2 with board set as ESP32 dev board - same setup that I use for all other Lilygo boards projects and all other projects works smoothly.

But right now I am facing this error:

C:\Users\Luiz Eduardo\Documents\Arduino\trygithublilygorj45\trygithublilygorj45.ino:135:16: error: cannot declare variable 'server' to be of abstract type 'EthernetServer'
 EthernetServer server(80);
                ^~~~~~
In file included from C:\Users\Luiz Eduardo\Documents\Arduino\trygithublilygorj45\trygithublilygorj45.ino:118:
c:\Users\Luiz Eduardo\Documents\Arduino\libraries\Ethernet\src/Ethernet.h:254:7: note:   because the following virtual functions are pure within 'EthernetServer':
 class EthernetServer : public Server {
       ^~~~~~~~~~~~~~
 ^

exit status 1

Compilation error: cannot declare variable 'server' to be of abstract type 'EthernetServer'

In a basic research I found that this should be a library issue. But indeed I tryed with 5 or 6 types of ethernet libraries. Ethernet, Ethernet_Generic, WIZ, and some of EthernetWebServer by khoi. None of them worked and I got the same error for all.

So basically my first question is, which library setup is being used here ? Is there anything else I need to know to make it work ?

lewisxhe, 2025-07-09:
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
Which version did you use ?

Llgok, 2025-07-11:
@Deoyjadzo
Hello, for W5500 examples in ESPLib v3.0 and above, please use this one: [w5500_esplib_v3.0](https://github.com/Xinyuan-LilyGO/LilyGo-T-Relay/tree/main/examples/T-Relay-4-ESP32/w5500_esplib_v3.0).

Deoyjadzo, 2025-07-11:
> [@Deoyjadzo](https://github.com/Deoyjadzo) Hello, may I ask which example you are using for compilation? Currently, I am using the W5500_EthernetServer_Relay4.ino from esplib-v2.0.14, and it compiles and runs normally.
>
> 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

Which Ethernet library did you use in this case ?

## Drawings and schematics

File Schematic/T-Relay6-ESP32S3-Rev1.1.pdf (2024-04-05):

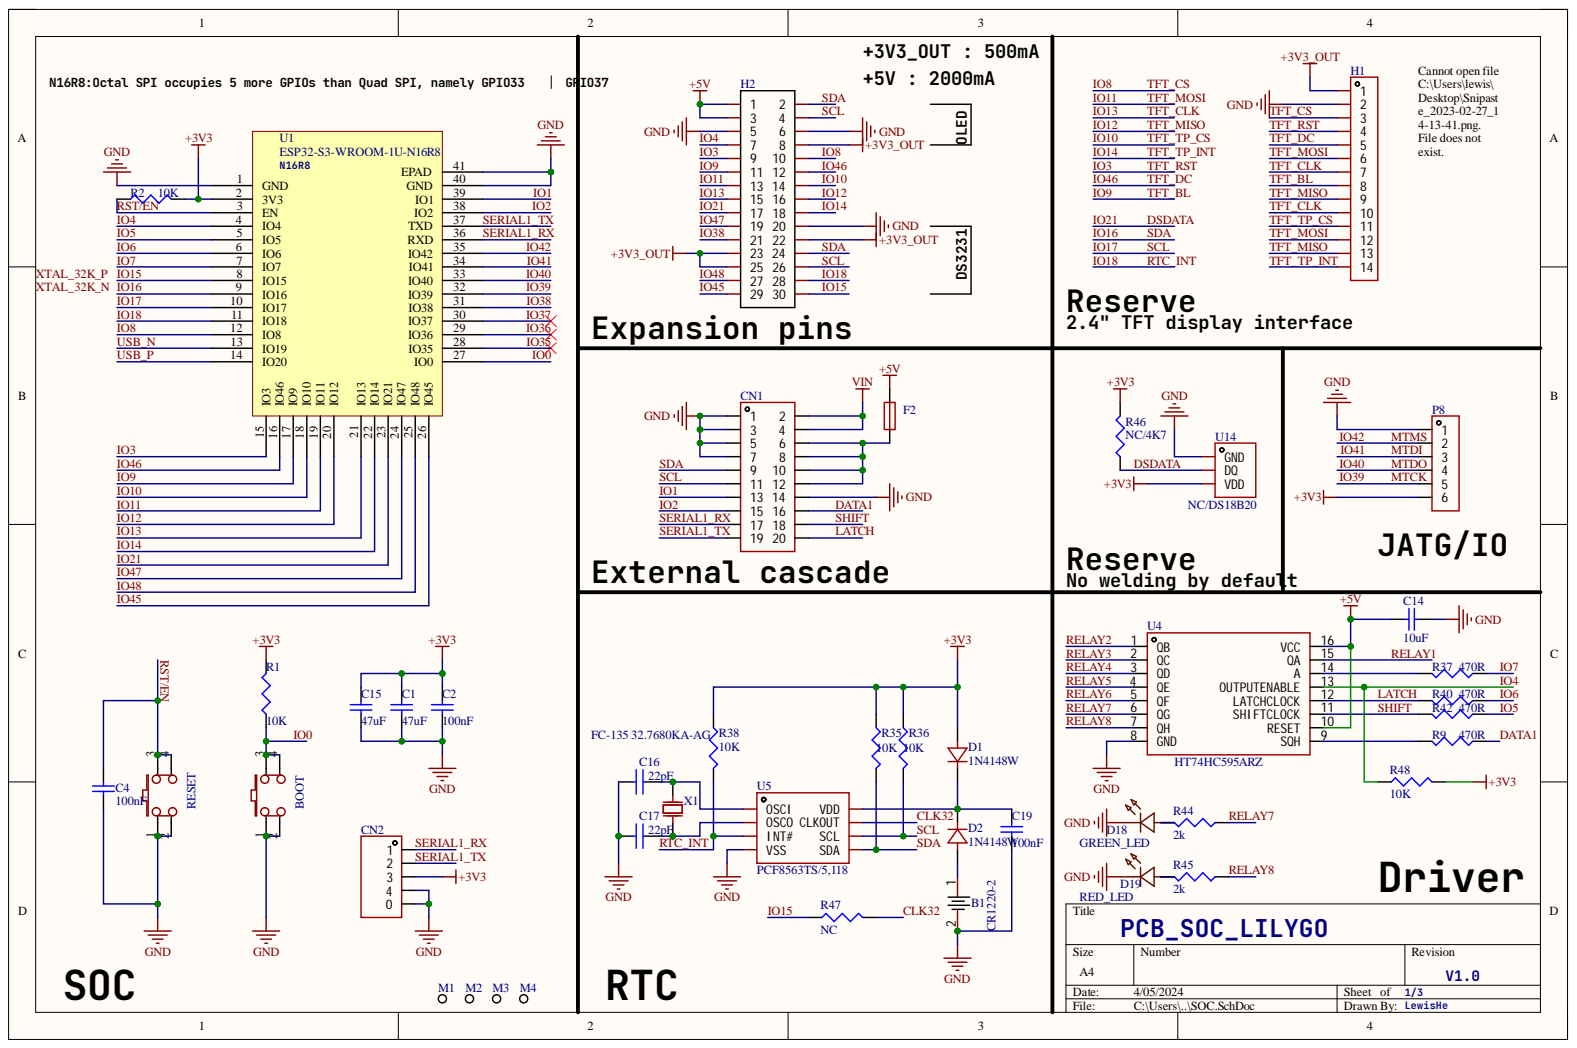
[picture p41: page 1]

Driver Cannot open file C:\Users\lewis\

Siz e A4 | Numb e r | R evisio n V1.0

Da te : 4/05/202 4 | She et of 1 / 3
File : C:\Use rs\. .\SOC . S c hD o c | Dr awn B y : L e w i s H e

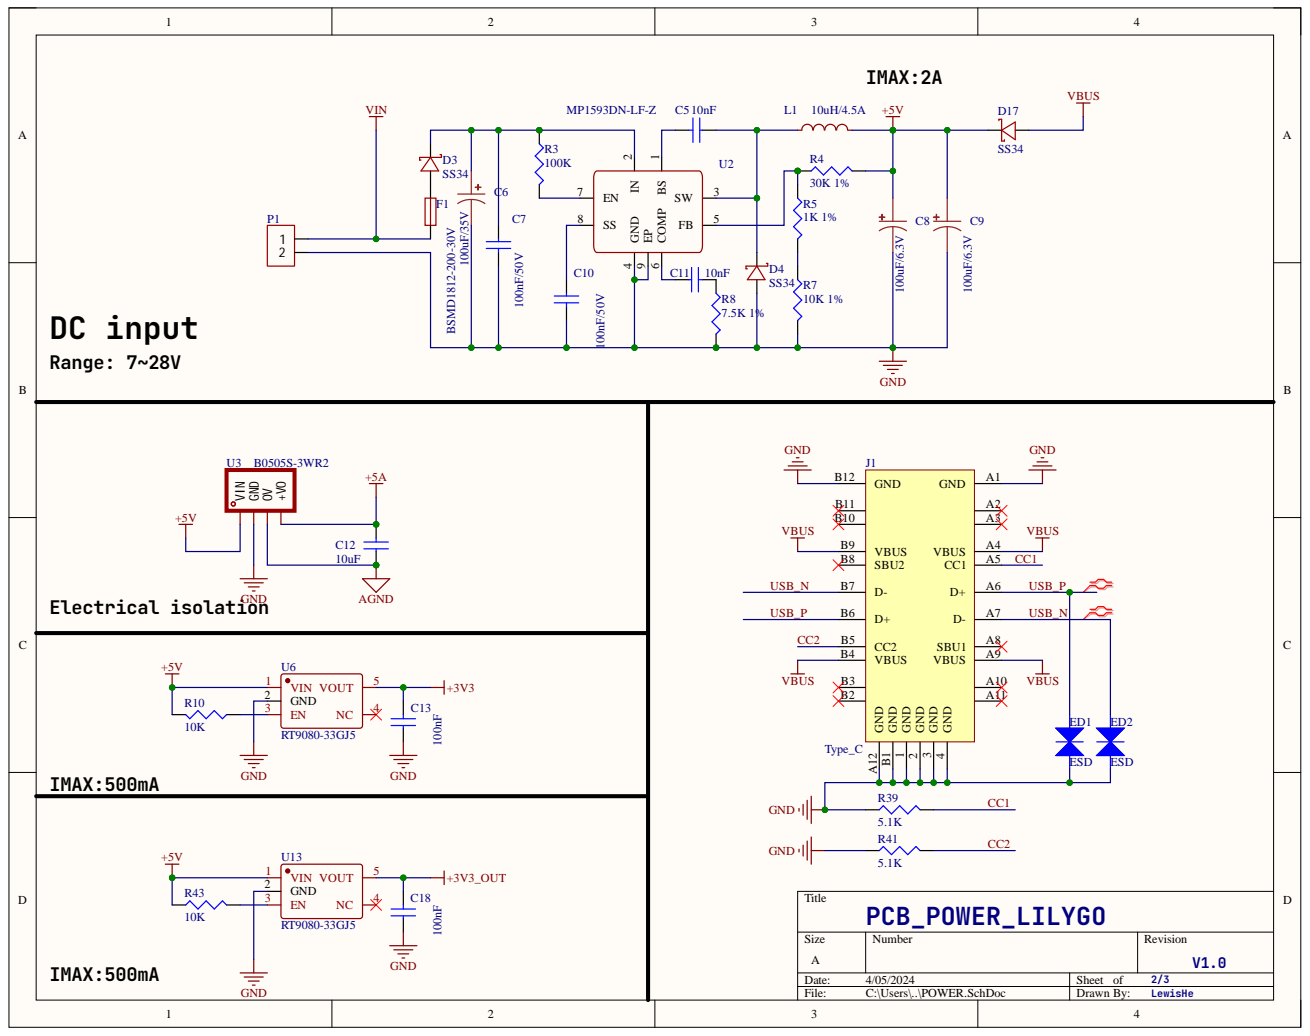
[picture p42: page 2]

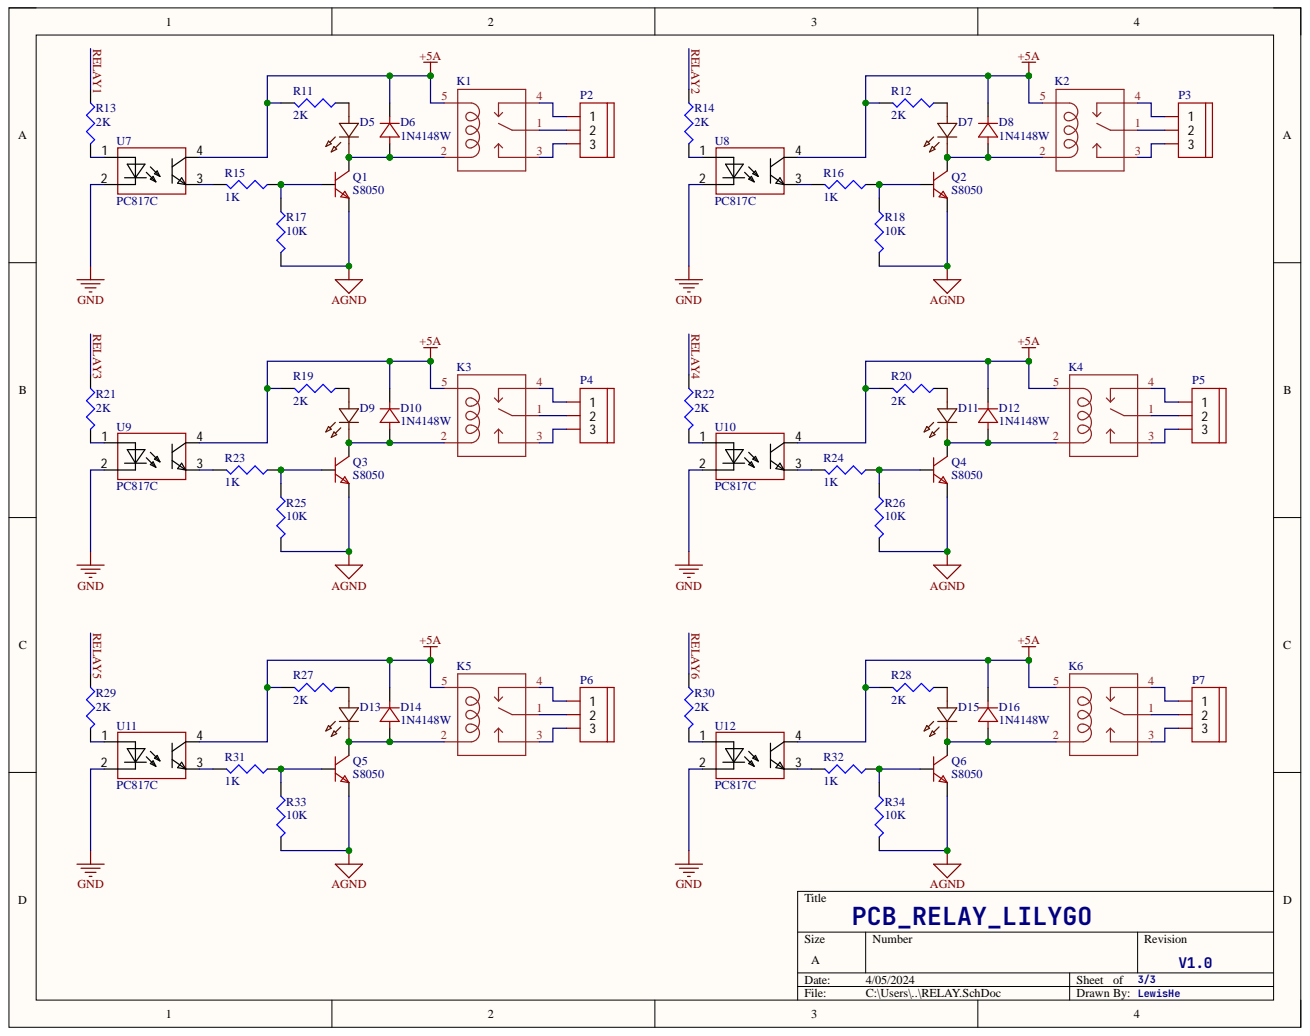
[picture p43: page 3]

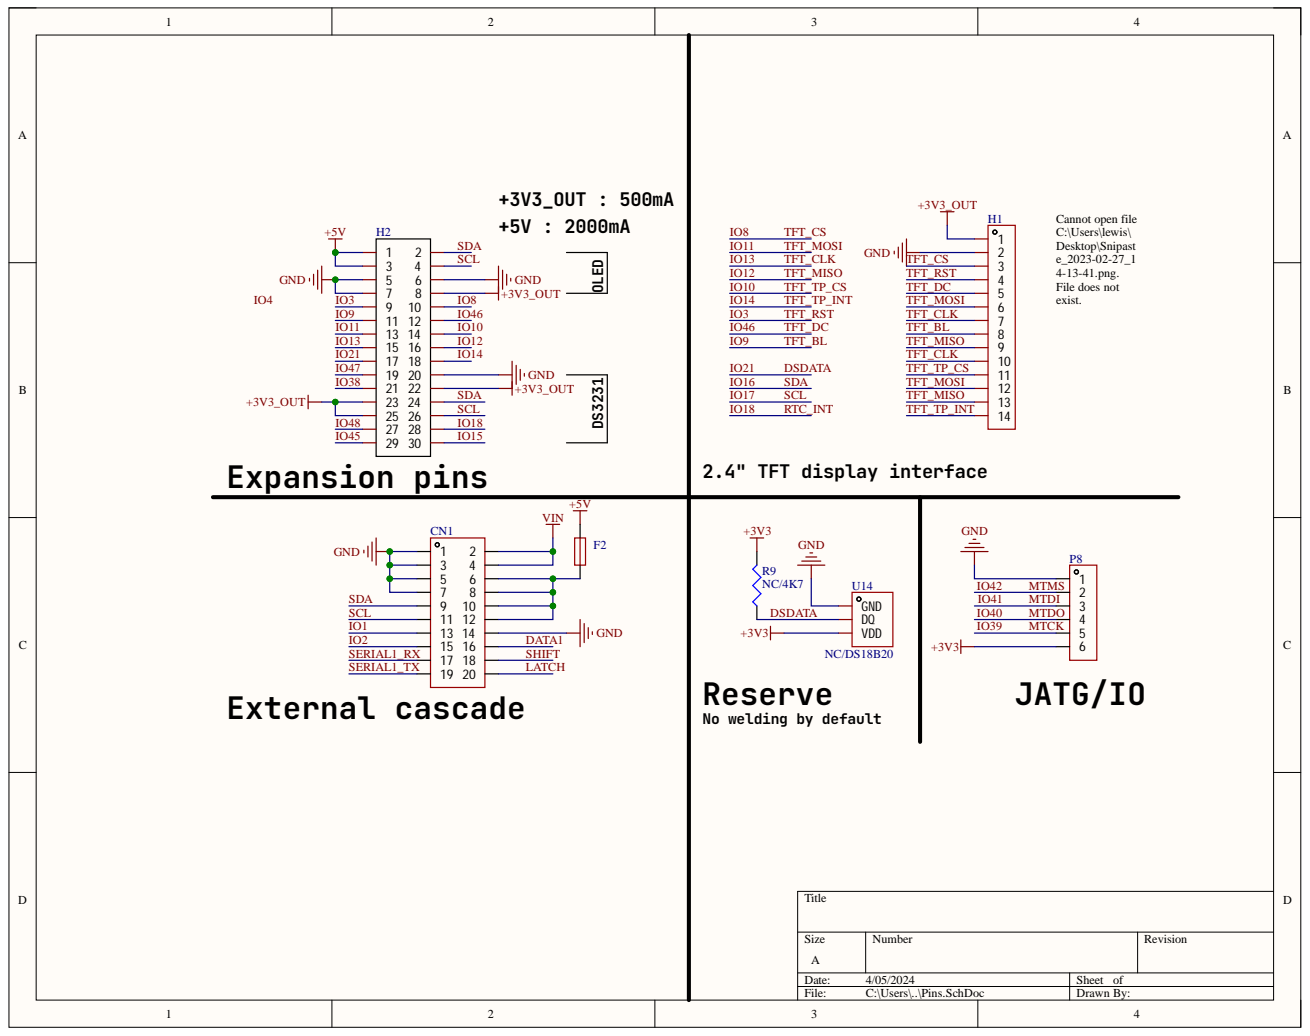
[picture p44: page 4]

4-13-41.png. File does not exist.

Reserve No welding by d

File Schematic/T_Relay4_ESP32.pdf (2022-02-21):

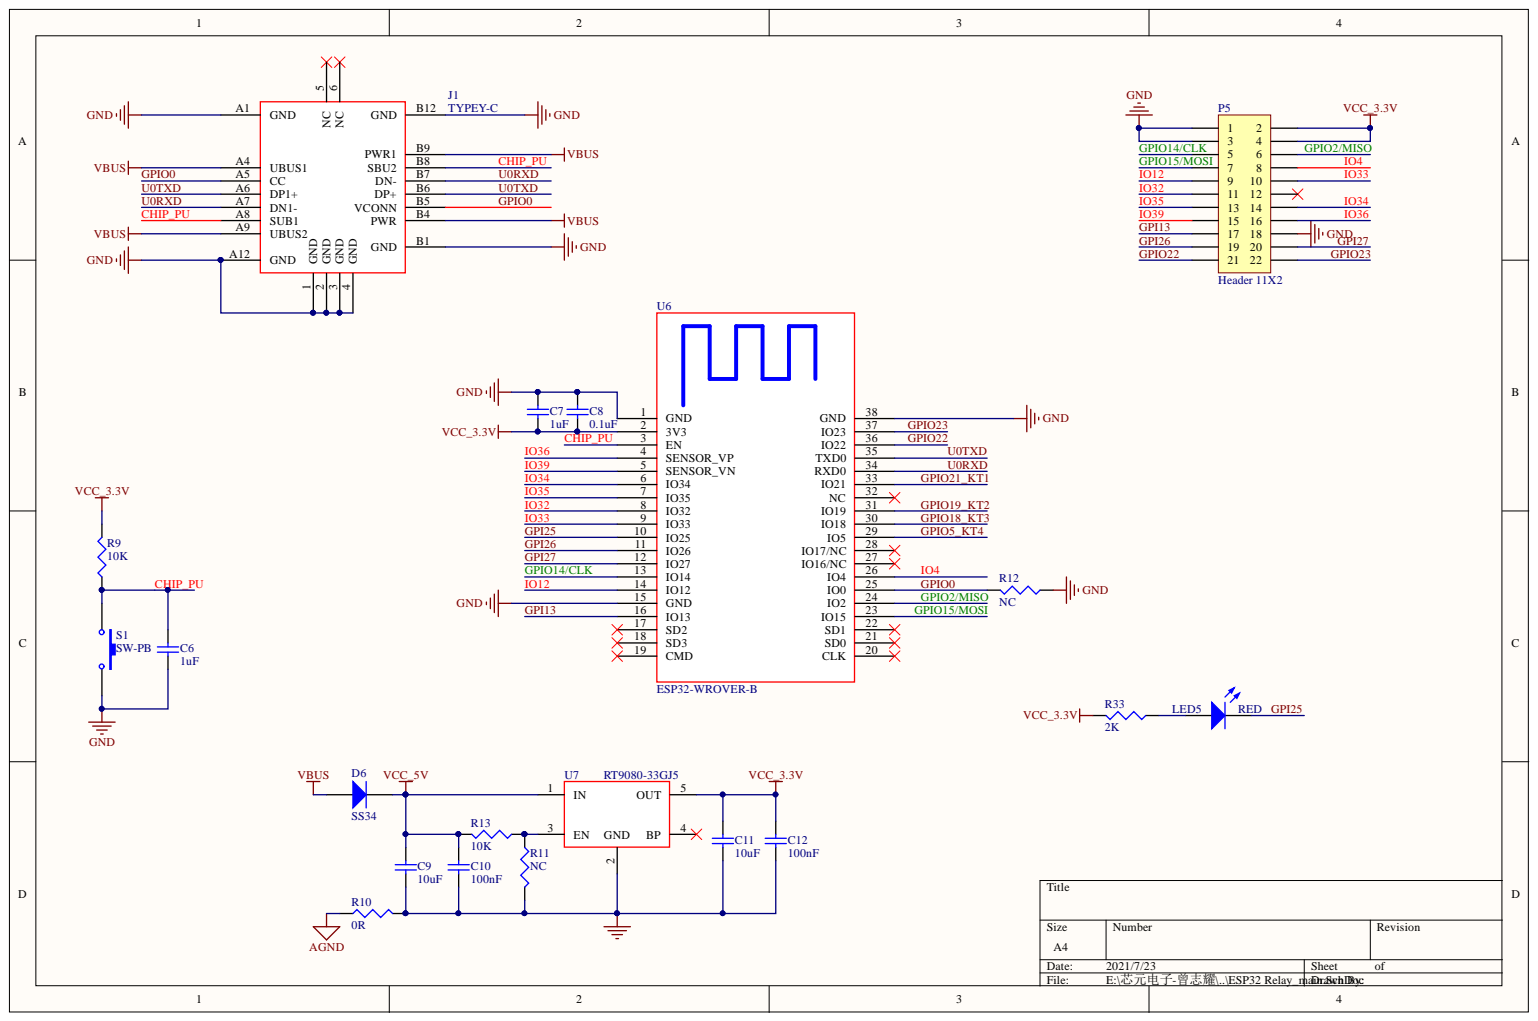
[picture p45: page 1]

C7 | C8
1uF | 3V3 2

GND 1

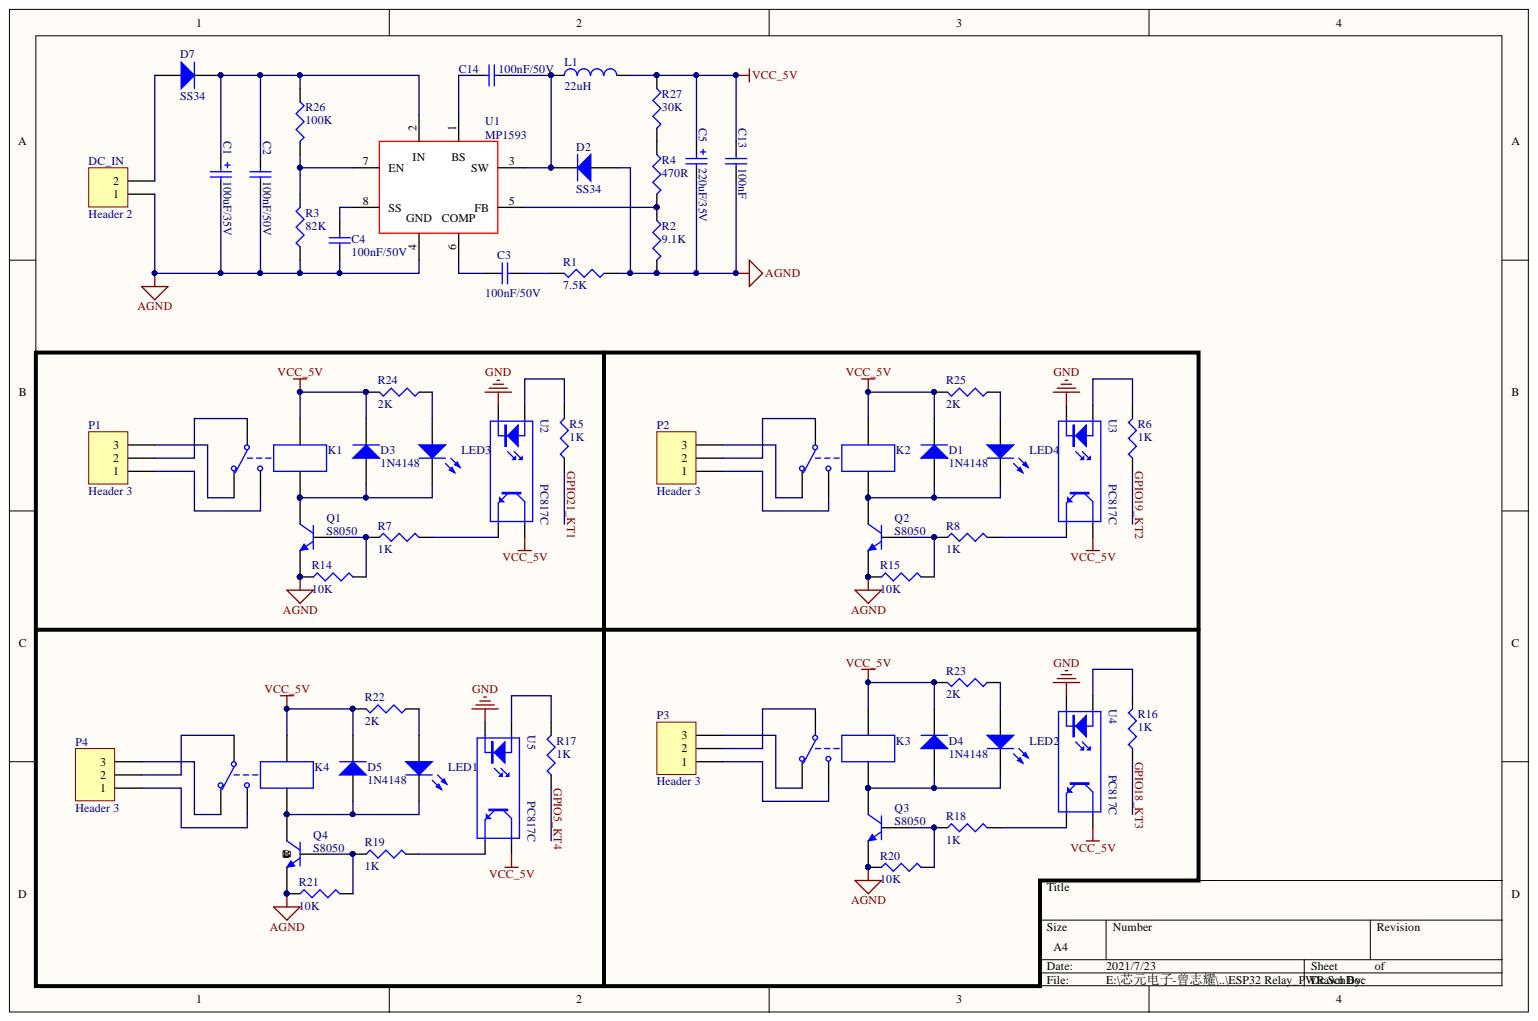
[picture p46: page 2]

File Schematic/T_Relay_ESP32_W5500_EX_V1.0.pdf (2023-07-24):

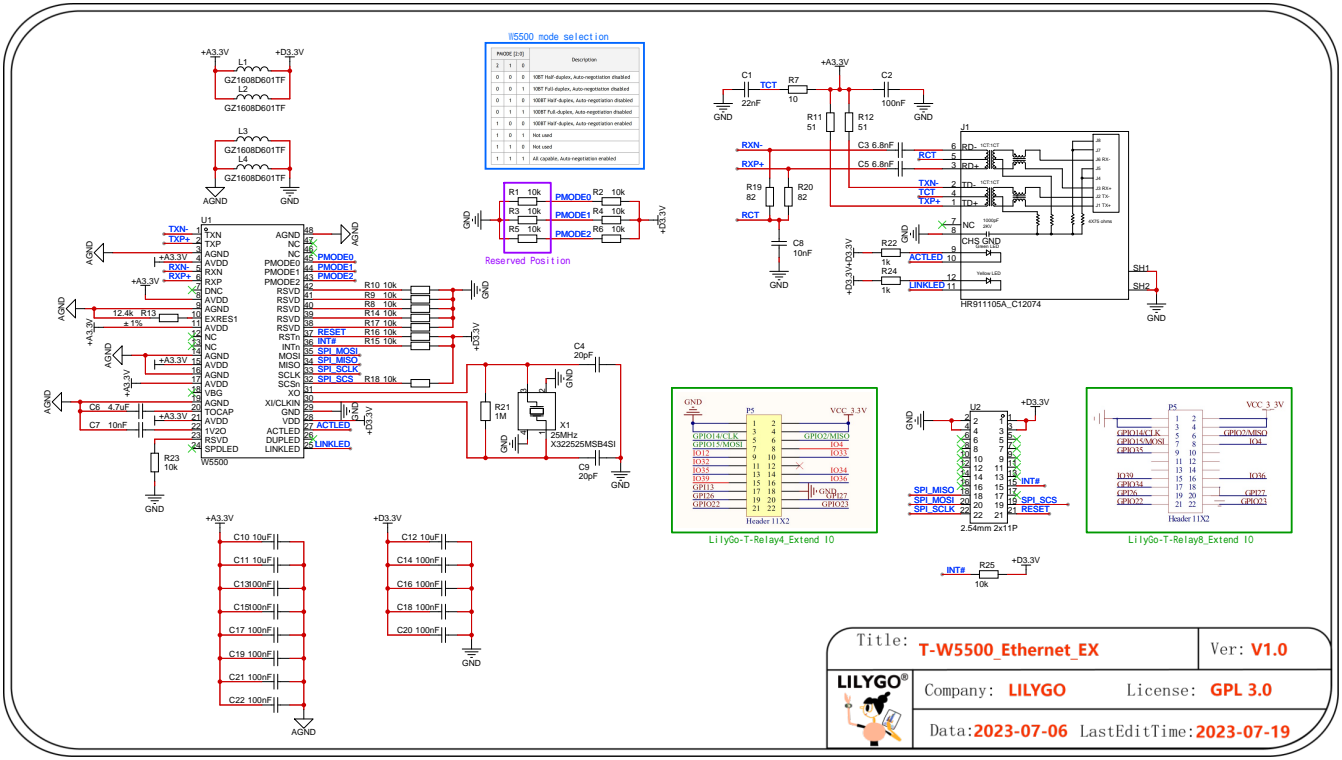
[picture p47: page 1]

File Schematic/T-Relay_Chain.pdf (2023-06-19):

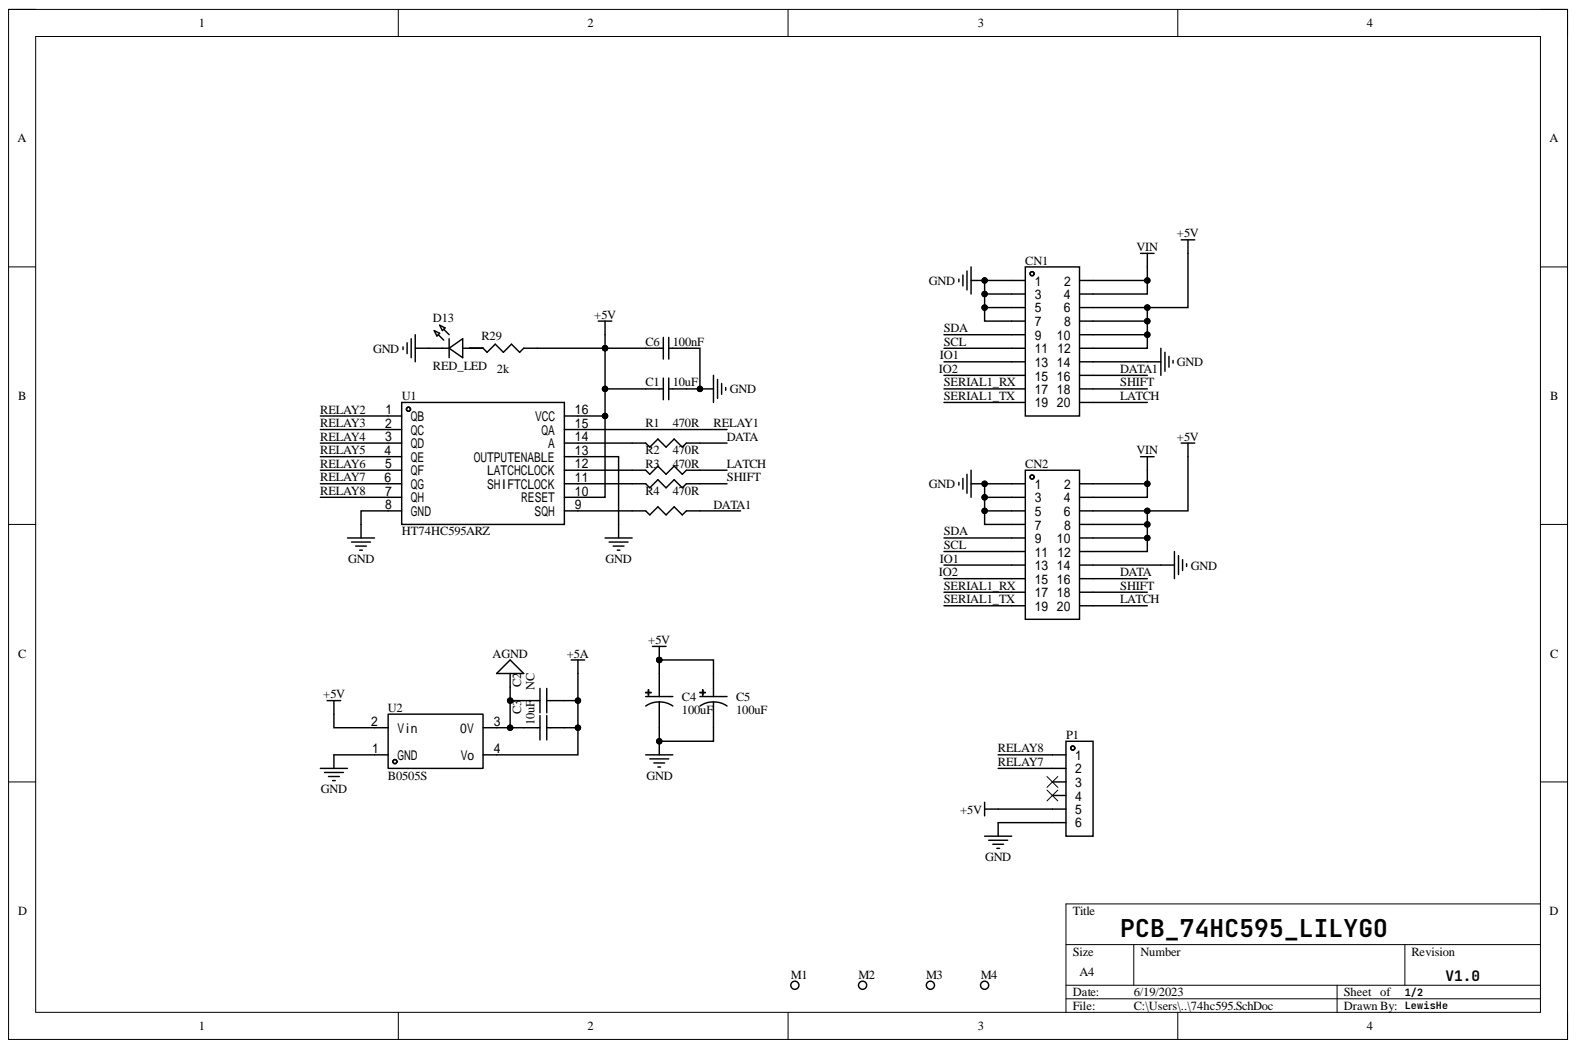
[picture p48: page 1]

Size A4 | Number | Revision V1.0

Date: 6/19/2023 | Sheet of 1/2
File: C:\Users\..\74hc595.SchDoc | Drawn By: LewisHe

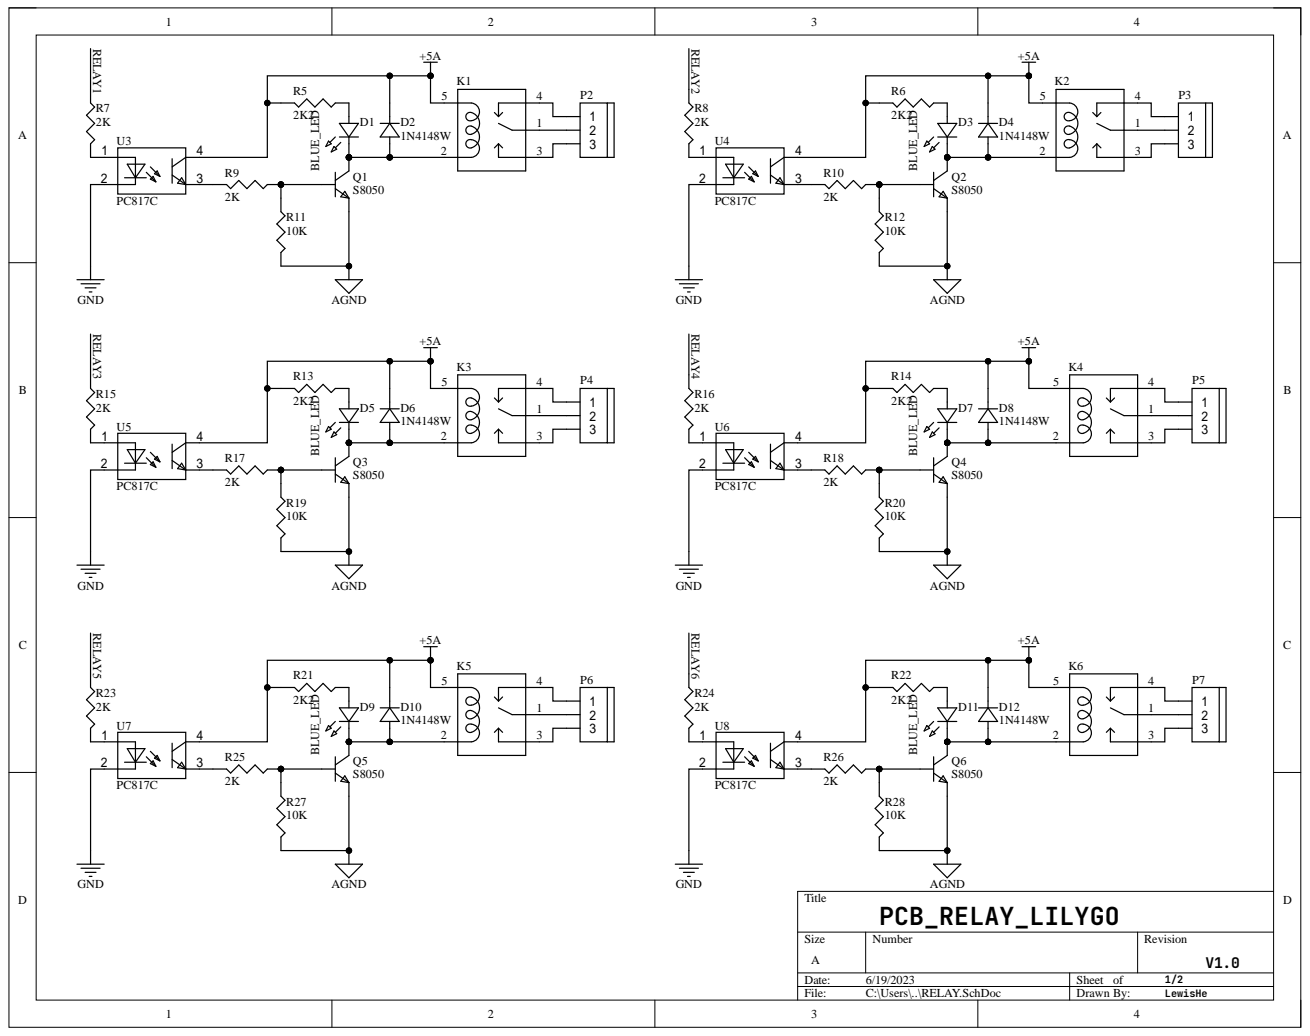
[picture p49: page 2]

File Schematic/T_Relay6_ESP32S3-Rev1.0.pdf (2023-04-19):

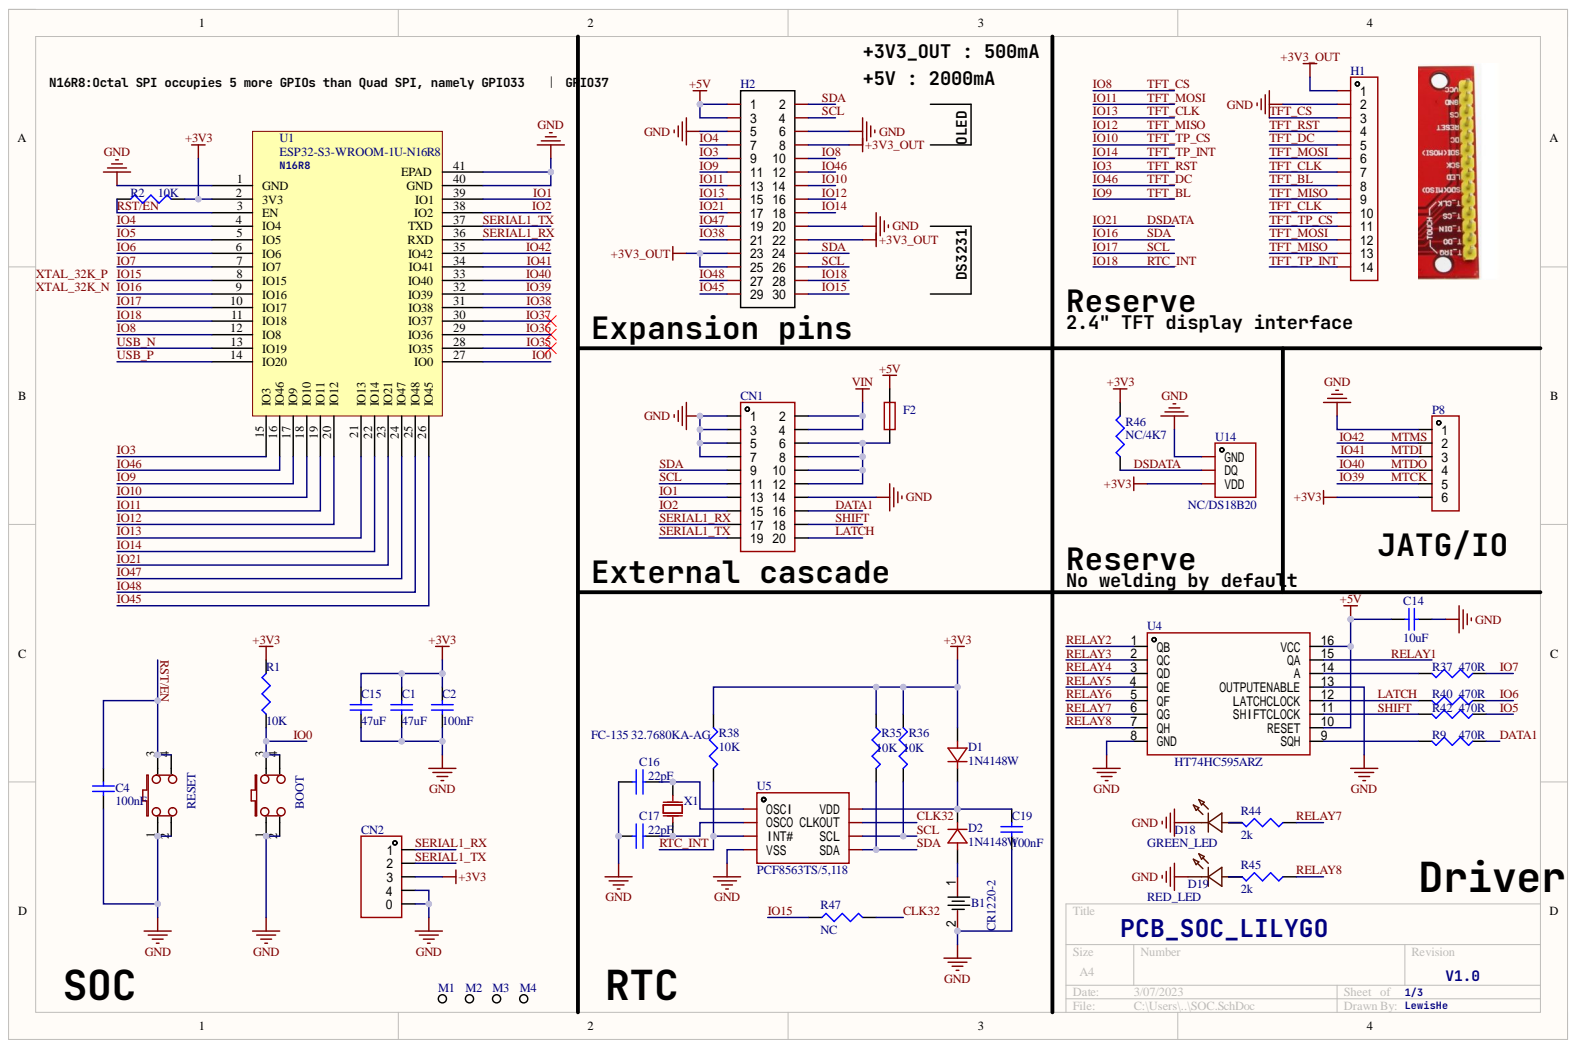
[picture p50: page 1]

Siz e A4 | Numb e r | R evisio n V1.0

Da te : 3/07/202 3 | She et of 1 / 3
File : C:\Use rs\. .\SOC . S c hD o c | Dr awn B y : L e w i s H e

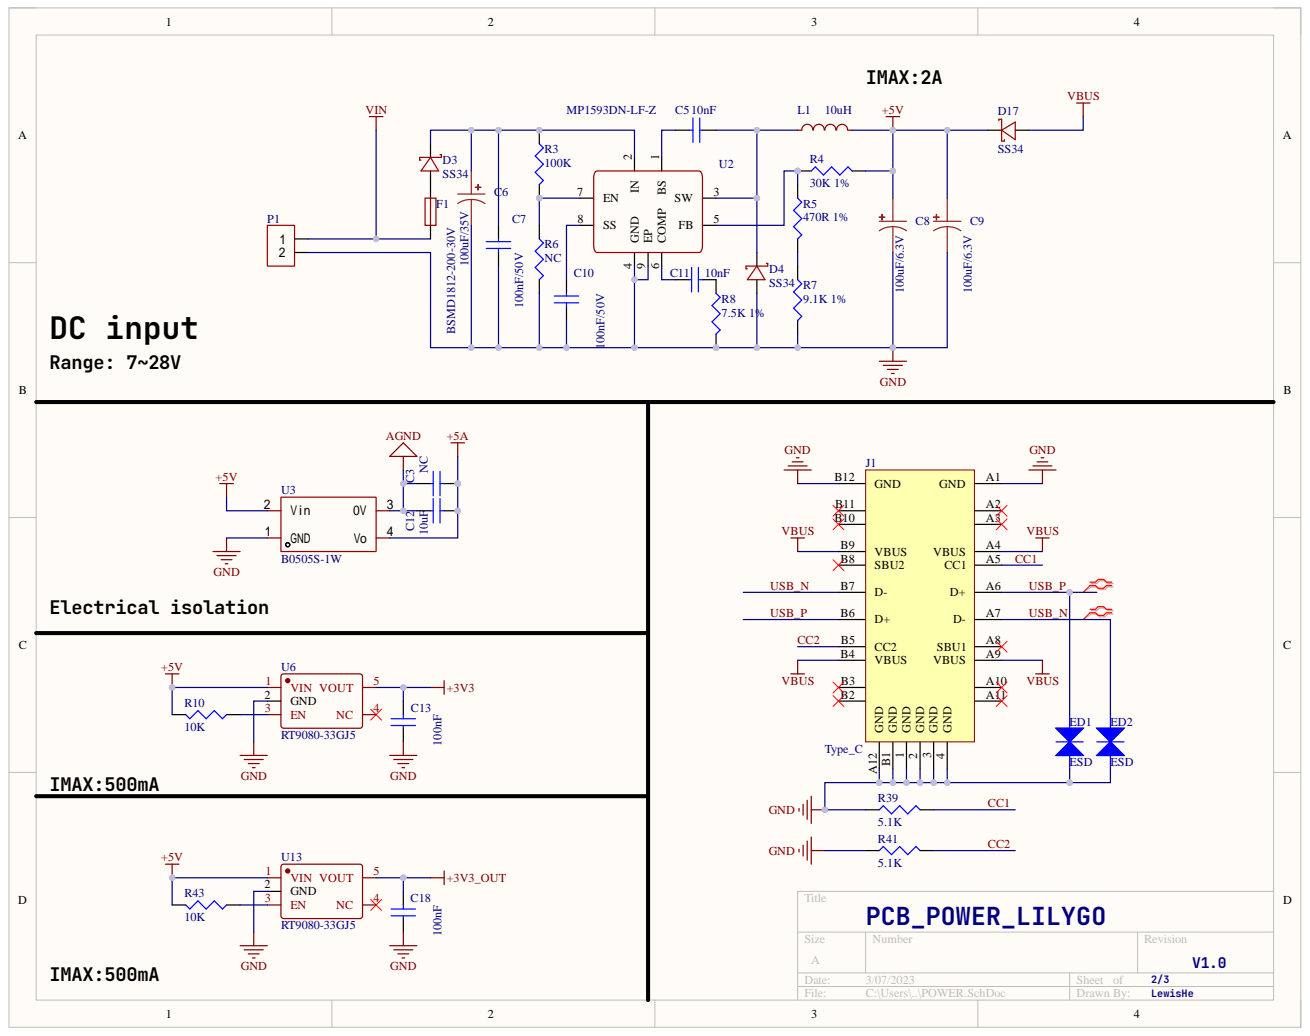
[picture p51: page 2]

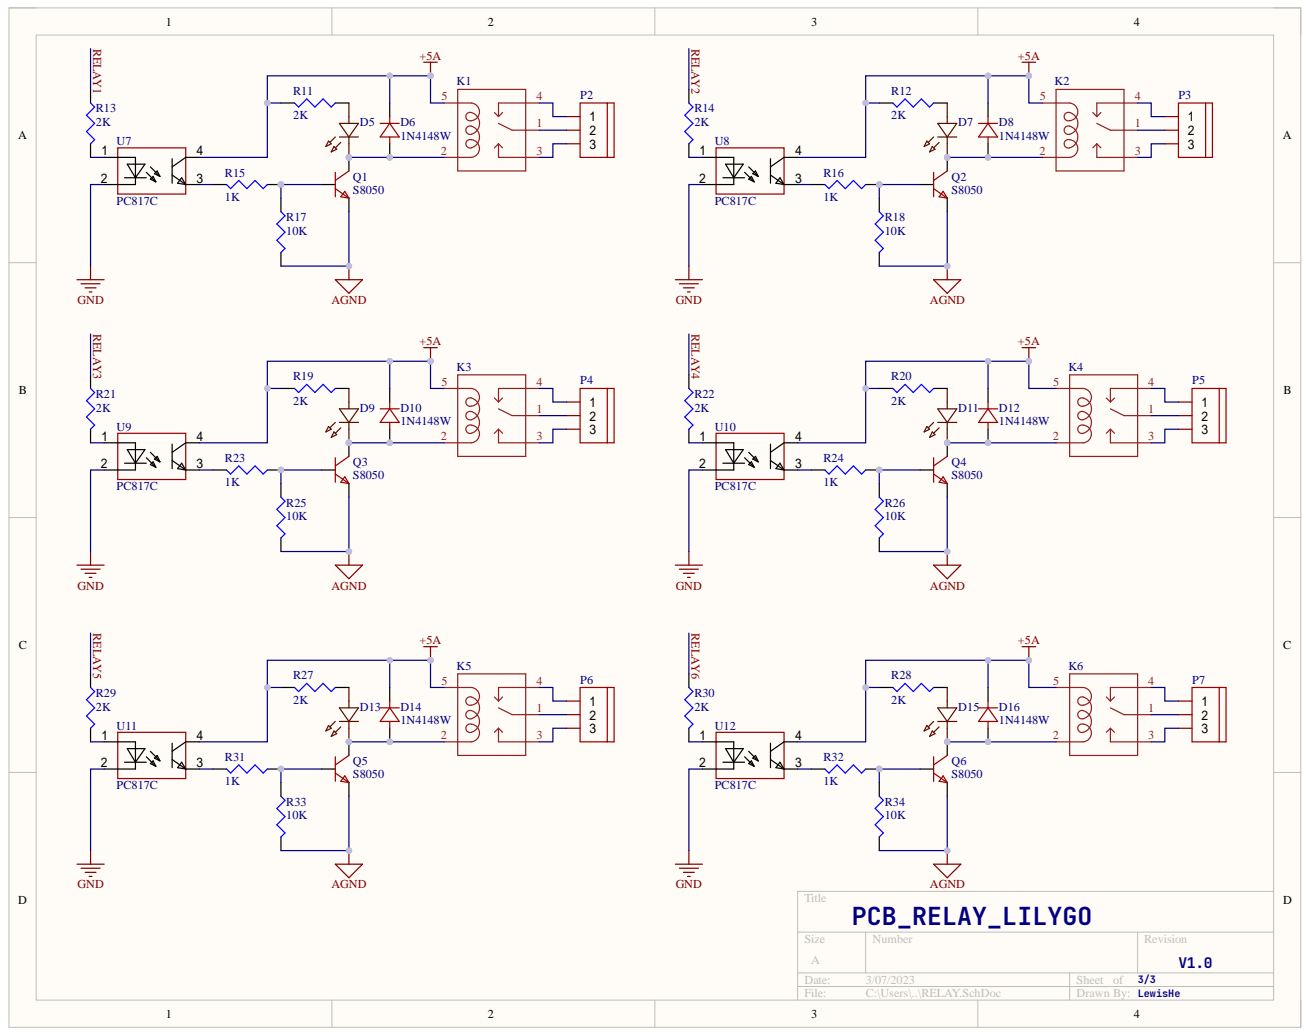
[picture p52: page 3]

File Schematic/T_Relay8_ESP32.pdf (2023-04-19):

A

1 | 2 | 3 | 4 | 5 | 6


Size | Number | Revision

Date: | Sheet of
File: | Drawn By:

# DCBA

1


Size | Number | Revision

Date: | Sheet of
File: | Drawn By:

# DCBA

1


Size | Number | Revision

Date: | Sheet of
File: | Drawn By:

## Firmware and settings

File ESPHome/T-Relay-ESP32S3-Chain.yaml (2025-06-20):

esphome:
  name: lilygo-relays3
  build_path: .esphome/build/lilygo-relays3

esp32:
  board: esp32-s3-devkitc-1
  framework:
    type: arduino

sn74hc595:
  - id: "sn74hc595_hub"
    data_pin: 7
    clock_pin: 5
    latch_pin: 6
    oe_pin: 4
    sr_count: 2  # By default, only one Chain is configured
    
switch:
  - platform: gpio
    name: "Switch 1"
    pin:
      sn74hc595: sn74hc595_hub
      number: 0
      inverted: false
      id: relay1

  - platform: gpio
    name: "Switch 2"
    pin:
      sn74hc595: sn74hc595_hub
      number: 1
      inverted: false
      id: relay2

  - platform: gpio
    name: "Switch 3"
    pin:
      sn74hc595: sn74hc595_hub
      number: 2
      inverted: false
      id: relay3

  - platform: gpio
    name: "Switch 4"
    pin:
      sn74hc595: sn74hc595_hub
      number: 3
      inverted: false
      id: relay4

  - platform: gpio
    name: "Switch 5"
    pin:
      sn74hc595: sn74hc595_hub
      number: 4
      inverted: false
      id: relay5

  - platform: gpio
    name: "Switch 6"
    pin:
      sn74hc595: sn74hc595_hub
      number: 5
      inverted: false
      id: relay6

  - platform: gpio
    name: "Switch 7"
    pin:
      sn74hc595: sn74hc595_hub
      number: 6
      inverted: false
      id: relay7

  - platform: gpio
    name: "Switch 8"
    pin:
      sn74hc595: sn74hc595_hub
      number: 7
      inverted: false
      id: relay8

  - platform: gpio
    name: "Switch 9"
    pin:
      sn74hc595: sn74hc595_hub
      number: 8
      inverted: false
      id: relay9

  - platform: gpio
    name: "Switch 10"
    pin:
      sn74hc595: sn74hc595_hub
      number: 9
      inverted: false
      id: relay10

  - platform: gpio
    name: "Switch 11"
    pin:
      sn74hc595: sn74hc595_hub
      number: 10
      inverted: false
      id: relay11

  - platform: gpio
    name: "Switch 12"
    pin:
      sn74hc595: sn74hc595_hub
      number: 11
      inverted: false
      id: relay12

  - platform: gpio
    name: "Switch 13"
    pin:
      sn74hc595: sn74hc595_hub
      number: 12
      inverted: false
      id: relay13

  - platform: gpio
    name: "Switch 14"
    pin:
      sn74hc595: sn74hc595_hub
      number: 13
      inverted: false
      id: relay14

  - platform: gpio
    name: "Switch 15"
    pin:
      sn74hc595: sn74hc595_hub
      number: 14
      inverted: false
      id: relay15

  - platform: gpio
    name: "Switch 15"
    pin:
      sn74hc595: sn74hc595_hub
      number: 15
      inverted: false
      id: relay16

      
logger:
  level: DEBUG
  baud_rate: 115200
  logs:
    mqtt.component: DEBUG
    mqtt.client: ERROR

mqtt:
  broker: mqtt server address
  username: Your mqtt username
  password:  Your mqtt password
  port: 1883

api:
  encryption:
    key: "E4AvftHULay+f6wwnKgHzsu7q7nzUdcrHp/Mjhyyjvk="

# ota:
  # password: "0204c885b8f04777ae94a8e51b4619c5"

wifi:
  ssid: "Your wifi ssid"
  password: "Your wifi password"

  ap:
    ssid: "Relay Fallback Hotspot"
    password: "fltzKdbsbDEn"

captive_portal:

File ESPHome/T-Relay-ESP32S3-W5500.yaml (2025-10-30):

esphome:
  name: lilygo_relay_s3
  friendly_name: relay

esp32:
  board: esp32-s3-devkitc-1
  framework:
    type: arduino

sn74hc595:
  - id: "sn74hc595_hub"
    data_pin: 7
    clock_pin: 5
    latch_pin: 6
    sr_count: 1

# Individual outputs
switch:
  - platform: gpio
    id: ch_en
    pin: 
      number: GPIO4
      inverted: true
    restore_mode: ALWAYS_ON

  - platform: gpio
    # SN74HC595 Pin #0
    name: "Switch 1"
    pin:
      sn74hc595: sn74hc595_hub
      # Use pin number 0
      number: 0
      inverted: false
      id: relay1

  - platform: gpio
    # SN74HC595 Pin #1
    name: "Switch 2"
    pin:
      sn74hc595: sn74hc595_hub
      # Use pin number 1
      number: 1
      inverted: false
      id: relay2

  - platform: gpio
    # SN74HC595 Pin #2
    name: "Switch 3"
    pin:
      sn74hc595: sn74hc595_hub
      # Use pin number 2
      number: 2
      inverted: false
      id: relay3

  - platform: gpio
    # SN74HC595 Pin #3
    name: "Switch 4"
    pin:
      sn74hc595: sn74hc595_hub
      # Use pin number 3
      number: 3
      inverted: false
      id: relay4

  - platform: gpio
    # SN74HC595 Pin #4
    name: "Switch 5"
    pin:
      sn74hc595: sn74hc595_hub
      # Use pin number 4
      number: 4
      inverted: false
      id: relay5

  - platform: gpio
    # SN74HC595 Pin #5
    name: "Switch 6"
    pin:
      sn74hc595: sn74hc595_hub
      # Use pin number 5
      number: 5
      inverted: false
      id: relay6

mqtt:
  broker: Your MQTT server
  # username: Your MQTT Username
  # password:  Your MQTT Password
  port: Your MQTT port

# Enable logging
logger:
  level: DEBUG
  baud_rate: 115200
  logs:
    mqtt.component: DEBUG
    mqtt.client: ERROR

# Enable Home Assistant API
api:
  encryption:
    key: "E4AvftHULay+f6wwnKgHzsu7q7nzUdcrHp/Mjhyyjvk="

ota:
  password: "0204c885b8f04777ae94a8e51b4619c5"

ethernet:
  type: W5500
  clk_pin: GPIO9
  mosi_pin: GPIO13
  miso_pin: GPIO11
  cs_pin: GPIO3
  interrupt_pin: GPIO12
  reset_pin: GPIO8
  clock_speed: 8MHz

captive_portal:

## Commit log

2022-01-19 Dimensions upload
    [T-Relay-Size.dxf]
2022-02-21 Upload schematic
2022-06-01 perfect test：Add an 8-way relay example. Platforio compilation is supported
2022-06-06 docs：Update the link
2022-06-09 test：blynk_Console
2022-06-09 docs：blynk_Console
2022-11-10 test：esphome yaml
2023-03-20 Organize Catalog
    [T-Relay-Size.dxf, T-Relay8-Size.dxf]
2023-03-20 Added T-RelayS3 Examples
2023-04-19 Update schematic
    [T-Relay-ESP32.dxf, T-Relay6-ESP32S3.dwg, T-Relay8-ESP32.dxf]
2023-06-19 Added schematic & README
2023-07-21 Updated support for W5500_Eth for LilyGo-T-Relay
2024-04-05 Fix GPIO Pin definition error https://github.com/Xinyuan-LilyGO/LilyGo-T-Relay/issues/30
    [RTC_PCF8563_TimeSynchronization.ino, UnitTestExample.ino, devices.h]
2024-04-05 Added revision T-Relay-S3 Rev1.1 schematic
2024-07-19 Update the example of version T-Relay6-S3_V1.1
2024-08-02 Update Relay S3 yaml
2024-10-04 Update relay test examples
2024-10-04 Added relay test fw https://github.com/Xinyuan-LilyGO/LilyGo-T-Relay/issues/41
2024-10-18 Fix esphome https://github.com/Xinyuan-LilyGO/LilyGo-T-Relay/issues/44
2025-01-10 Added T-Relay Chain sch https://github.com/Xinyuan-LilyGO/LilyGo-T-Relay/issues/51
2025-01-22 Added W5500 esphome yaml https://github.com/Xinyuan-LilyGO/LilyGo-T-Relay/issues/23#issuecomment-2605329434
    [T-Relay-ESP32S3-W5500.yaml]
2025-01-27 Added Output Enable pin to documentation
2025-04-02 Updating the version descriptions for T-Relay 4 Channel, T-Relay 8 Channel, and T-Relay S3. #50
2025-06-20 Added T-Relay-ESP32S3-Chain esphome yaml
2025-06-20 Added relay8 3d
    [T-Relay8-ESP32-3D.stp]
2025-07-02 Added Relay2 examples
2025-07-02 Added relay 2 fw
2025-10-30 Fix the ESPHome error "w5500.mac: w5500_reset: reset timeout" issue #23
    [T-Relay-ESP32S3-W5500.yaml]
